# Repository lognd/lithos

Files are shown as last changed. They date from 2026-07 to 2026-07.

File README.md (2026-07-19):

# lithos

lithos is four declarative engineering-design languages -- **hematite**
for mechanical parts and assemblies, **cuprite** for electrical and
computer designs, **fluorite** for fluid circuits, **calcite** for
civil/architectural design -- built over one shared regolith, plus the
**regolith** toolchain that type-checks them and discharges their
engineering claims against verification models. The core idea inverts
the usual workflow: instead of drawing an implementation and analyzing
it afterward, a design *states intent and obligations* (what the
artifact must do, how it is made, what it promises to its neighbors)
and the toolchain proves those obligations -- or reports honest
failures as data, with source spans and provenance. Text is the single
source of truth: diffable, reviewable, and statically checkable without
rendering or simulating anything.

## Names (one geology theme)

| Name | What it is |
|---|---|
| **lithos** | the umbrella project (the languages + toolchain + registry); branding, not a code identifier |
| **hematite**  | the mechanical language; files `.hema` |
| **cuprite** | the electrical/computer language; files `.cupr` |
| **fluorite**  | the fluid-circuit language; files `.fluo` (ratified cycle 20) |
| **calcite** | the civil/architectural language; files `.calx` (chartered cycle 26, D133) |
| **regolith**  | the toolchain/CLI/import name (crates `regolith-*`, Python package `regolith`, lockfile `regolith.lock`) |
| **magnetite** | the package manager (manifest `magnetite.toml`, module `regolith.magnetite`, CLI `regolith magnetite`); its registry is "the magnetite registry" (cycle 26, D132; quarry/lodestone retired) |
| **feldspar**  | an external solver pack, its own repo (github.com/lognd/feldspar); optional -- discharges FEA and closed-form engineering claims through the pack contract, checked out beside this repo for local dev |

hematite, cuprite, fluorite, and calcite are deliberately "different
vocabularies over the same machinery": the type system, quantity/
interval engine, contract model, ownership discipline, and the
claim/obligation/evidence pipeline are defined once in the regolith
and bound per domain. Learning one language is most of the way to
knowing the others.

## Architecture in brief

The one-sentence shape: a Rust compiler core behind one coarse,
schema-versioned PyO3 boundary, wrapped by a Python orchestrator that
talks to the outside world. The split follows the spec's own
serialization point -- obligations are self-contained and serializable
-- so the boundary is coarse and stable rather than chatty.

- **Rust core** (`crates/regolith-*`): lexer (logos) + layout pass +
  lossless CST parser (rowan), the quantity/unit/interval engine, the
  entity database with queries/ownership/borrows, contract IR and
  budget arithmetic, lowering of claims to content-addressed
  obligations, and one diagnostic renderer. Pure, deterministic, and
  testable entirely without Python.
- **Python orchestrator** (`python/regolith/`): the verification
  harness (model registry plus numpy/scipy model packs that discharge
  physical claims), build tiers and the evidence cache, lockfile
  authorship, the `magnetite` package client, and the `regolith` CLI.

The harness discharges claims against a model registry; closed-form
model packs ship in this repo, and higher-fidelity models (FEA and
other numeric solvers) come from **feldspar**, an optional external
solver pack (github.com/lognd/feldspar, its own repo -- checked out
beside this one for local dev). feldspar is not required: a build
without it degrades honestly, discharging what the in-tree closed-form
packs can prove and reporting the rest as open obligations rather than
failing silently. It plugs in through the one plugin seam
(`regolith.plugins`, AD-26); the pack contract itself is normative in
[`docs/spec/toolchain/20-solver-abstraction.md`](docs/spec/toolchain/20-solver-abstraction.md)
sec. 7-8.

Errors are data on both sides: `regolith-diag` diagnostics in Rust,
typani `Result` values in Python; exceptions and panics are reserved
for programmer bugs. Shared schemas are single-sourced in Rust
(schemars) and code-generated into pydantic models. The full normative
architecture (decisions AD-1..39) is in
[`docs/spec/toolchain/00-architecture.md`](docs/spec/toolchain/00-architecture.md).

## A taste of the syntax

From [`examples/tracks/hematite/pillow_block.hema`](examples/tracks/hematite/pillow_block.hema),
a profile whose radius is left for the toolchain to allocate (`minimize`
picks the value that satisfies the obligations):

```
profile BodyOutline:
    walk:
        from base_plane
        line right                    # a: base
        line up                       # b: right wall
        arc tangent, bulge=left       # c: dome
        line down                     # d: left wall
        close
    constraints:
        a.length = 90mm
        b.length = 22mm
        c.radius = in [28mm, 36mm] minimize
        symmetric(b, d, about=mid_plane)
    exports:
        mid_plane: datum
```

The `examples/` tree holds many more, including a ten-file cubesat
project (`examples/flagships/cubesat/`) used as the integration stress test.

## Getting started

Prerequisites: the pinned Rust toolchain (`rust-toolchain.toml`, stable
1.90.0) and [uv](https://github.com/astral-sh/uv) for the Python side.
One command sets up a working dev environment (uv sync plus building the
compiled extension into the venv):

```
make install
make check
```

`make check` is the single quality gate -- format, lint, types, and both
Rust and Python tests, cheapest first. Key targets:

| target | does |
|---|---|
| `install` | uv sync + build the `regolith._core` extension (debug) |
| `dev` | rebuild the extension into the venv on Rust change |
| `check` | full gate: fmt, lint, typecheck, core-import guard, tests |
| `test` | all tests (`test-rs` / `test-py` to split) |
| `snapshots`  | review insta snapshots |
| `schema` | regenerate the generated pydantic schema from Rust |
| `bench` | criterion benchmarks over the cubesat corpus |
| `fuzz` | fuzz the lexer/parser/CBOR decode (needs nightly cargo-fuzz)|
| `coverage` | Rust + Python coverage |
| `build` | release wheel via maturin |
| `health` | the repo health gate (`tools/health`): check + consistency + demos + fleet legs (D219) |

Run `make help` for the full list.

## Repository layout

Full doc index (spec, workflow, guide): [docs/index.md](docs/index.md).

```
docs/
  spec/            technical truth: regolith/ (shared abstract layer,
                    01..13), hematite/ cuprite/ fluorite/ calcite/
                    (the four language tracks), toolchain/ (normative
                    architecture + numbered design charters)
  workflow/        process: ground rules, dispatch protocol,
                    work-orders/, design-log/ (dated findings and
                    decisions, verbatim history)
  guide/           teaching guides, one per track plus authoring guides
crates/            the Rust core (regolith-util .. regolith-py)
python/regolith/   the Python orchestrator, harness, magnetite, and CLI
examples/          designs in target syntax (the golden / pressure-test corpus)
stdlib/            the standard library packages (std.*)
tests/             cross-boundary goldens, CLI end-to-end, and invariant tests
```

## The CLI

`regolith` is the single entry point; verbs include `check` (the
geometry-free linter), `fmt`, `debug`, `build`, `ship`, `optimize`
(the discrete/continuous search engine), `test` (the design-test
runner over `.test.<ext>` files), `doc`, `config`
(`get`/`where`/`list`/`set` over the four-level config doctrine),
`rules test`/`rules try` (rule-pack authoring), `plugin list` (AD-26
plugin seam), and the `magnetite` package-manager subtree
(`magnetite new`, `vendor`, `fetch`, `key`, `index`, `manifest
check`, with `new` and `vendor` also aliased at the top level). Run
`regolith --help` or `regolith <verb> --help` for the current,
authoritative list -- verbs land and change per work order faster
than this README does.

## graphite: the interaction surface

**graphite** (the drawing mineral) is the repo's interaction surface --
a TUI, and (cycle 35, D233/D234) a professional web dashboard/explorer/
artifact-viewer product. It EXTRACTED to its own sibling repo,
github.com/lognd/graphite, checked out beside this one for local dev,
exactly like feldspar: its own product charter, design system, and
work-order queue live in that repo's `docs/`, and its own `make check`
is its gate. It consumes only regolith's public surfaces -- CLI verbs
as subprocesses, reported JSON, and the D228 progress channel -- never
orchestrator or harness internals.

```
cd ../graphite && make install
graphite tui [project]     # terminal UI
graphite serve [project]   # dashboard, explorer, artifact viewers
```

The full guide, including what ships today versus what is still in
flight, is [`docs/guide/12-graphite.md`](docs/guide/12-graphite.md).

## Status

Honest state of the project:

- **Languages and specs: complete.** The regolith and all four language
  tracks (hematite, cuprite, fluorite, calcite) are settled; the
  technical open-question queue is empty by design. `docs/` is the
  normative source, led by the invariant ledger
  (`docs/spec/regolith/13-invariants.md`).
- **Toolchain: substantially built, `make check` green.** The Rust core
  (lexer, layout, CST parser, entity DB, quantity/interval engine,
  contract IR, and lowering to obligations), the PyO3 bridge, the
  Python orchestrator, the harness with closed-form model packs, and the
  `magnetite` package tool are implemented and pass the gate. CI runs
  format/lint/type/test on a matrix, with fuzzing and benchmarks wired.
- **Invariant suite (INV-1..30): mostly real green,** with a small
  number of deliberately tracked `xfail` fixtures where the enforcing
  machinery is still being wired.
- **Roadmap:** the mechanical geometry realizer (`FeatureProgram` IR
  through build123d/OCCT to STEP), the optimization engine
  (`regolith optimize`), CAM and HDL verification, and the
  design-test runner (`regolith test`) have all landed; higher-
  fidelity FEA verification escalates to the optional feldspar
  solver pack rather than living in-tree. Remaining work is tracked
  in `TODO.md` and the design-log queue -- not here (this README
  does not duplicate the ledger).

## License

GPL-2.0-only (the Linux kernel's license; owner-decided 2026-07-08):
free to use, study, modify, and redistribute -- derivatives play by
the same rules. Full text in `LICENSE`.

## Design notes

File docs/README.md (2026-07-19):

# lithos -- Documentation

Declarative, goal-oriented engineering design languages built on one
shared regolith:

- **hematite** -- mechanical design (parts, processes, assemblies).
- **cuprite** -- electrical and computer design (circuits, boards,
  logic, processors).
- **fluorite** -- fluid circuits (feed systems, coolant loops,
  hydraulics, pneumatics; ratified cycle 20, D93).
- **calcite** -- civil/architectural design (spaces, structure,
  envelope; chartered cycle 26, D133 -- the youngest track).

Named on one geology theme (D78, cycle 10; fluorite cycle 20;
magnetite + calcite cycle 26): **hematite** is iron ore (steel,
structure -> mechanical); **cuprite** is copper ore (wire, current ->
electrical); **fluorite** is the mineral named for flowing (flux ->
fluids); **calcite** is the mineral of limestone and cement (->
buildings); **magnetite** (the package manager) attracts them all;
everything is worked by **regolith** (the shared toolchain). The
whole project -- languages, toolchain, registry -- is umbrella-branded
**lithos**. Retired names: `quarry`/`lodestone` (-> magnetite, D132),
`mill`/`loom`/`dcad`/`deda`, and calcite's dead draft usage as the
fluid track's name (`.calc`, D93; the civil track uses `.calx`);
retired names appear verbatim only in `design-log/` history.

All the languages invert the traditional workflow:

```
Traditional:  Implementation -> (manual analysis) -> "does it work?"
Here:         Claims + Contracts -> (solvers, provers) -> Implementation + Evidence
```

The designer declares what the artifact must do, how it will be made,
and what it promises to other artifacts. The system derives the
implementation, allocates the numbers nobody wants to pick by hand,
and attaches evidence to every physical claim. Text is the single
source of truth: diffable, reviewable, and statically checkable
without rendering or simulating anything -- which makes design
generation (human or LLM) a locally verifiable problem. The north
star: write a declarative file, inject a high-skill engineer at the
intermediate steps only if necessary, and get something out the end
that just works.

The languages are deliberately "different vocabularies over the same
machinery": the type system, the contract model, the ownership
discipline, the claim/obligation/evidence pipeline, the lowering
architecture, and the build system are all defined once, in the
regolith, and bound per domain. Learning one language should mean
already knowing 80% of the others.

## Reading order

1. `spec/regolith/` -- the abstract backing layer. Read this first; every
   language track is an instantiation of it.
2. `spec/hematite/` -- the mechanical language. The most mature track.
3. `spec/cuprite/` -- the electrical and computer language.
4. `spec/fluorite/` -- the fluid-circuit language (ratified v1, cycle 20).
5. `spec/calcite/` -- the civil/architectural track (charter cycle 26,
   elaborated cycle 27, ratified 2026-07-08, D149; front end landed,
   WO-47).
6. `guide/` -- the teaching guides (getting started + per-track).

## Directory map

Three top-level categories (D138, cycle 26): `spec/` is technical
truth, `workflow/` is process, `guide/` is for people.

```
docs/
  spec/          TECHNICAL -- normative specifications
    regolith/    the shared abstract layer (domain-neutral), 01-13;
                 13-invariants.md is the guarantee ledger (INV-1..35;
                 INV-33 withdrawn/RESERVED, D253.4)
    hematite/    mechanical track (unified spec; version on header)
    cuprite/     electrical + computer track
    fluorite/    fluid-circuit track, `.fluo` (ratified v1, cycle 20)
    calcite/     civil/architectural track, `.calx` (charter cycle 26;
                 ratified D149, 2026-07-08)
    toolchain/   00-architecture.md (NORMATIVE, AD-1..47),
                 grammar.ebnf, numbered design charters (10-..46-);
                 20-solver-abstraction.md sec. 7-8 is the feldspar
                 pack contract (AD-26 plugin seam)

  workflow/      PROCESS -- how the project is built
    README.md    ground rules, the dispatch protocol, the WO
                 dependency graph
    work-orders/ WO-01..171, agent-executable, one per dispatchable
                 unit; the live dispatch queue is `tickets.md`
                 (`frob ticket doable`) -- WO `Status:` lines are
                 historical narrative, not a second queue
    design-log/  dated findings + decisions ledgers, one per design
                 cycle -- THE project history, verbatim (never edited)

  guide/         PEOPLE -- teaching + authoring guides
                 (getting started, per-track guides, then
                 authoring/tooling guides: DFM rules, optimization,
                 graphite, parity reports, CAM/HDL verification,
                 board correctness, design testing)

../examples/     the spec pressure corpus (see examples/README.md):
                 tracks/ per-language single-file tests, systems/
                 multi-file spec-pressure projects (dune_buggy,
                 reaction_wheel, regen_engine, sdr_transceiver),
                 flagships/ the charter-31 program members held to
                 the full ship+parity bar (cubesat Kestrel, arm_a6,
                 cnc_router_r1, printer_k1, uav_talon, and more),
                 hdl/ coverage fixtures, negative/ diagnostic
                 fixtures, registry/ component records
../stdlib/       the standard library packages (std.*, D135;
                 organization normative home: charter 39,
                 spec/toolchain/39-stdlib-organization.md)
```

graphite (the TUI + web dashboard/explorer interaction surface) is no
longer in this tree: it EXTRACTED to its own sibling repo (cycle 35,
D233/D234, github.com/lognd/graphite), checked out beside this one
for local dev exactly like feldspar. See `guide/12-graphite.md`.

## Status legend

Used throughout:

- **[SETTLED]** -- decided; changing it is a spec revision.
- **[LEANING: x]** -- default direction chosen, revisit allowed cheaply.
- **[OPEN-n] / [EOPEN-n] / [FOPEN-n] / [SOPEN-n]** -- needs a decision
  (mech / elec / fluid / regolith numbering). The technical open queue
  is EMPTY by design (F90); deferred items carry explicit reopen
  criteria in each track's open-questions doc.
- **[SEAM-n]** -- designed on both sides, the joint itself unspecified.

## Cross-domain composition

A mechatronic system is one `system` with parts from several domains:
a board is simultaneously an electrical artifact and a mechanical one;
a building (calcite) hosts fluid loops (fluorite) and power (cuprite).
The regolith's contract model is what makes this tractable -- an
interface may carry roles and promises from more than one domain's
quantity namespaces. See `regolith/10-domain-binding.md`.

## feldspar (the optional solver pack)

**feldspar** (github.com/lognd/feldspar) is an external, optional
solver pack -- its own repo, checked out beside this one for local
dev. It supplies higher-fidelity FEA and closed-form engineering
verification models that plug into the regolith harness's model
registry through the one plugin seam (`regolith.plugins`, AD-26).
It is not required: a build without feldspar checked out degrades
honestly, discharging whatever the in-tree closed-form model packs
can prove and reporting the rest as open obligations rather than
failing. The pack contract itself -- what a pack must implement,
claim-kind naming, coverage/evidence encoding, the payload-ref
channel -- is normative in
`spec/toolchain/20-solver-abstraction.md` sec. 7-8. Cite paths inside
it as `feldspar:<path>` (never a `../` path; see Conventions below).

## Conventions

- Cross-repo citations are repo-qualified, never filesystem-relative:
  `feldspar:docs/spec/09-model-integration.md` means that path in the
  `feldspar` repo (github.com/lognd/feldspar). `../` paths out of
  this repository are banned in living docs (they do not resolve on
  GitHub); design-log history keeps whatever it originally said.

- All documentation and source examples are ASCII-only. The languages
  themselves define ASCII canonical operator spellings (`&`, `dia`,
  `+-`, `deg`, `mu_`); formatters may render unicode, files never
  store it.
- Spec versions ride each track's header line and bump when the track
  materially changes; the per-cycle change ledgers live in
  `design-log/` (one dated file per cycle, findings F* and decisions
  D* numbered globally).

## Revision history

Lives in `workflow/design-log/`, one dated ledger per design cycle -- that is
the authoritative trail of every finding (F1..) and decision (D1..).
This file intentionally carries no duplicate changelog (D137: git
history and the design logs are the archive).

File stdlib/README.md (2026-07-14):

# stdlib/ -- the `std.` catalog (D135, WO-45)

**Normative home:** `docs/spec/toolchain/39-stdlib-organization.md`
(charter 39, D227/AD-37) is the normative organization doctrine for
everything in this directory -- namespace taxonomy, package anatomy,
content classes, the lithos/feldspar boundary rule, and the naming/
growth discipline, all machine-checked in the health consistency leg
(`tools/stdlib/organization.py`). This README is the working package
INDEX (below) plus the D135/D58 history this catalog started from;
where the two disagree, charter 39 wins. See also
`docs/guide/28-growing-the-stdlib.md` for a worked "where does my new
content go" walkthrough.

Governance history (regolith/11 sec. 8, D135):

- `std.` is a RESERVED namespace prefix in the magnetite registry: only
  the lithos project publishes under it.
- Nothing in the compiler special-cases `std` (grep `std.` in `crates/`
  stays clean of new logic), with the one documented exception that the
  unit tables (what `std.units` would be) live in `regolith-qty` because
  quantities are load-bearing at L1, before package resolution runs.
  `std.quantities` (below) is therefore a nominal package: it declares
  the namespace/claim-form surface the tracks already assume, so a
  project's `magnetite.toml` can depend on it like any other package,
  but it ships no records of its own -- the math lives in `regolith-qty`.
- **In-repo development home:** each `stdlib/<package>/` directory is a
  real magnetite package (its own `magnetite.toml` + record/model
  content). CI and the example corpus (`examples/`) consume these
  in-repo copies directly, via `regolith.magnetite.manifest.resolve_dependencies`
  pointed at `stdlib/` as a local search path -- no network, no separate
  "path source" concept invented (checked `magnetite/sources.py` first,
  per the WO note: `resolve_dependencies` already IS local-path
  resolution; `Sources`/`Registry` in `sources.py` is a distinct concern,
  URL-based routing for a future fetch step, not needed here).
  Publication to the public registry (out of scope, regolith/11 sec. 10)
  would be the same act as for any third-party package; the project
  signing key confers the tier (INV-14).
- **Tier honesty (D58):** every record here that transcribes a
  real-world datasheet/handbook value without an attached certified
  test report says `tier=community` in-file, and cites its source.
  Nothing here claims `tier=certified`.

## Packages (v1)

| package | kind(s) | content |
|---|---|---|
| `std.quantities` | quantities | namespace/claim-form declarations only (math in `regolith-qty`) |
| `std.materials` | materials | starter metal/polymer records, `tier=community`; cycle-33 F112 queue adds `records/composites.toml` (6 rows: E-glass/epoxy and carbon/epoxy unidirectional lamina engineering constants transcribed from the widely-reprinted Tsai/Jones/Barbero textbook table, plus a cross-ply and a quasi-isotropic laminate-modulus row per fiber system derived from those lamina constants by Barbero's closed-form approximations; `density_kg_m3` omitted on every row, no source above pins it honestly) |
| `std.contact` | materials | dry/greased contact-pair friction records, `tier=community` |
| `std.mech` | interfaces, matings | mount/flange interface packs, process capability packs (cnc/forged/formed/cast/molding/sheet/tube/turned/weld/joining/gear/linear/spring/bearings/seals), bolted/press/bearing matings; WO-64 W3/WO-66 follow-up added `Prismatic` to `mech.matings` (mirrors `Revolute`'s single-exposed-dof pattern for linear motion, content-only, no compiler change) |
| `std.sheet_metal` | process | sheet-metal process capability records; the DFM RULE-PACK half is EXCLUDED (WO-28 engine remainder owns the rule format) -- this package is the record content + package home only |
| `std.elec` | interfaces, matings, components | port/family/protocol/bus packs (buffers, buses, digital, families, logic, power, protocols, sense) PLUS (WO-66, D174/D179) a GENERATED `passive_family` E-series batch (`records/e_series.toml`, IEC 60063 resistor/capacitor parametric families) and a hand-cited `connectors.toml` batch (JST-XH/PH, Molex KK, screw-terminal classes). WO-66 follow-up batch 2 (2026-07-10) adds `records/cells.toml` (Samsung INR18650-25R cylindrical Li-ion class, EEMB LP503759 pouch LiPo class, plus a `series_pack` class deriving voltage/mass by declared cell x S-count arithmetic -- not a transcribed vendor pack SKU) and `records/servos.toml` (Hitec HS-311 standard + HS-55 micro RC servo classes), all hand-cited manufacturer datasheet figures. Cycle-33 F112 queue batch 2 (2026-07-10) adds two more `crystals.toml` rows (Epson FA-238 32.768kHz tuning-fork RTC crystal, Abracon AB-8.000MHZ HC-49/US class) and three more `connectors.toml` rows (JST-PH 4-position, Molex-KK 6-position, and a 0.1in board-to-board pin-header class carrying the first `exposure_class = "internal"` example), same hand-cited shape as the WO-79/WO-66 batches. Config-strap rows (the third WO-79-pattern item on the same queue entry) were evaluated and CUT: no stdlib package hosts MCU strap records today (the three straps: tables that exist -- `examples/registry/{rp2040,atsamd21,stm32g0}.cupr` -- are corpus, not stdlib/, out of this batch's scope), and no additional MCU part could be cited to the same section-number precision those three already meet without risking the fabricated-precision failure mode `rp2040.cupr`'s own header explicitly warns against; named growth, not silently dropped. |
| `jlc_2l` | process | JLCPCB 2-layer fab + basic SMT assembly capability records (vendor-named, rides beside `std.elec`, NOT under the `std.` prefix) |
| `std.fluid` | materials | media property tables + fitting/loss/pipe-schedule records; WO-60 (D166) added a `components.toml` batch (pump, ball valve, in-line filter, metering orifice), real-catalog cited; WO-64 W1/W2 (WO-66 follow-up, D182) added `records/polymer_melt.toml` (PLA/PETG melt-medium classes: solid density + cited melt-density/zero-shear-viscosity point sets, PETG's melt density/viscosity OMITTED with a note pending a verifiable source) and two more `[[pump]]` rows in `components.toml` (Sunon 4020 12V DC axial fan, Delta 5015 24V DC radial blower -- rated flow endpoints only, real-catalog cited) |
| `std.intents` | verbs | intent-verb schemas (`sense`, `actuate`) |
| `std.debug` | verbs | debug/probe/indicate verb schemas |
| `std.models` | models | registration manifest binding the EXISTING `python/regolith/harness/models/` code -- the code does not move, this package only names it |
| `std.mech.mechanisms` | matings, process | pattern library (D144/AD-28, WO-53 seed + Batch B; WO-60 Batch C): `four_bar`, `slider_crank`, `lead_screw`, `belt_drive`, `gear_train`, `bearing_arrangement`, `helical_spring`, `flexure_pivot`, `toggle_linkage` -- coupler-law `mating`s, `advise:`-only recognition rules (`dfm:` block) |
| `std.elec.patterns` | interfaces, components, process | pattern library (D144/AD-28, WO-53 seed + Batch A): `level_shifter`, `decoupling`, `reverse_polarity`, `tvs_clamp`, `rc_debounce`, `ldo` -- `block`s + reference impls, `advise:`-only recognition rules (`erc:` block) |
| `std.civil` | occupancy, loads, matings, sections, materials | WO-48 slice C + WO-60 widening: occupancy/egress tables (IBC), load cases + ASCE 7/AISC/NDS/geotech combination sets, transfer classes as real `mating`s with `dof: kept=` (`Pinned`/`Moment`/`Bearing`/`Roller`/`BasePlate`/`EmbeddedPost`), starter section/material/soil records PLUS (WO-60, D166) a real AISC 16th-ed. `w_shape` family (16 sections) and `hss_square` family (28 sections, ASTM A500 Grade C) so section search has a real multi-member domain; `astm_a500_grc` material added to match. The reference building-code rule pack is EXCLUDED (`TODO(WO-28)`: the engine remainder it needs is still blocked upstream). WO-66 (D174) adds a GENERATED `sections_channels_angles.toml` (`steel_channel`/`steel_angle` families, same AISC v16.0 edition) as an ADDITIVE file beside `sections.toml` -- zero existing rows touched or renamed. WO-66 follow-up batch 2 (2026-07-10) widens the `timber_sawn` family in `sections.toml` from 2 to 11 rows (nominal 2x6 through 2x12, 4x4/4x6, and 6x8/6x10/6x12 beam-class sizes; dressed dimensions per the ALSC/PS 20-based NDS Supplement Table 1B table the two original rows already cite, section properties computed from those dressed dims by the same method the original rows use) -- ADDITIVE ONLY, the two original rows untouched. |
| `std.cost` | rates, pricing, unit_costs, models | WO-54 (D147, toolchain/27): rate/pricing/unit-cost FIXTURE records (every number invented -- never transcribed vendor/RSMeans data, research note 2026-07-09 sec. 4) + the harness-half naming of the reference estimator models (`cost_elec_bom`/`cost_fluid_bom`/`cost_civil_takeoff`, the std.models code-does-not-move precedent). Includes the deliberately-expired `acme.quote_2025q4` negative-fixture pricing source. |
| `ti.logic` | components | WO-60 (D166): TI 74HC-series glue-logic component records (SN74HC02 quad NOR, SN74HC138 3-to-8 decoder, SN74HC688 8-bit identity comparator) -- the `nor_glue` candidate family for WO-56's `by select(nor_glue, cpld, mcu_chip_selects)` demo. Vendor-named, rides beside `std.elec` (regolith/11 sec. 2's own worked example row), NOT under the `std.` prefix. |
| `microchip.cpld` | components | WO-60 (D166): ATF1502AS/ATF1502ASL 32-macrocell CPLD component records (two speed grades, -7 and -25) -- the `cpld` candidate for the same WO-56 demo. Vendor-named. |
| `st.mcu` | components | WO-60 (D166): STM32F4 FSMC (RM0090) external-bus-interface chip-select record -- the `mcu_chip_selects` candidate for the same WO-56 demo (an MCU's own EBI/FSMC decode instead of external glue). Vendor-named. |

| `std.fasteners` | components | WO-66 (D174): ISO metric fastener grids -- socket head cap screws (ISO 4762), hex bolts (ISO 4014), hex nuts (ISO 4032), plain washers (ISO 7089), GENERATED from `tools/stdlib/gen_fasteners.py` over the committed `tools/stdlib/data/iso_fasteners.toml` table (D178 shape ratification). |
| `std.bearings` | components | WO-66 (D174): deep-groove ball bearing grid (60xx/62xx/608 class, ISO 15 boundary dims) + LM_UU linear bushing seed, hand-cited (D180). |
| `std.motion` | components | WO-66 (D174): NEMA 17/23 stepper rated-point classes, Tr8 leadscrew class, GT2 belt/pulley class, MGN12/15 linear rail seed, hand-cited (D180). |
| `std.machines` | components | WO-66 (D174, feeds WO-67/AD-35): 3-axis mill / FDM printer / CO2 laser CLASS records (travel/kinematics/spindle-or-nozzle), hand-cited (D180). |
| `std.tooling` | components | WO-66 (D174, feeds WO-67/AD-35): solid-carbide end-mill and ISO 235/DIN 338 jobber-drill geometry classes, hand-cited (D180). |
| `std.power` | records | WO-134 (charter 43 sec. 2-3/5, D250): NEC (NFPA 70) 2023 Edition Article 310/250 tables transcribed as data -- `conductor_ampacity` (Table 310.16, copper 14 AWG-500 kcmil + aluminum 12 AWG-500 kcmil, 60/75/90C columns), `temp_correction_factor` (Table 310.15(B)(1), 21-85C ambient bands), `conduit_fill_adjustment` (Table 310.15(C)(1), 4-41+ current-carrying conductors), `grounding_electrode_conductor` (Table 250.66), `equipment_grounding_conductor` (Table 250.122), and `motor_locked_rotor_code` (ANSI/NEMA MG 1-2016 (R2018) sec. 10.37.2 locked-rotor kVA/HP code-letter classification, A-V). Transformers, breakers/fuses (frame/trip/AIC/curve), motor HP/kW/PF/efficiency catalog rows, and busway are NAMED REFUSALS (D250 sec. 3: no offline-verifiable specific catalog source this session) recorded in the WO-134 close-out, not fabricated. |

`std.fluid.circuits` / `std.civil.assemblies` (D144 pattern libraries,
remaining catalog batches) are catalog GROWTH, not this WO's seed
(charter `docs/spec/toolchain/26-pattern-libraries.md` sec. 3
non-goal).

## Record format

Record BODIES that are ordinary language source (interface/mating/
process declarations consumed by a track's front end) are authored in
that track's own syntax, exactly like `examples/registry/*.cupr`. Data
records with no track-specific syntax yet (materials, contact pairs,
fluid media/pipe tables) are authored as plain TOML under each
package's `records/` directory and loaded by
`regolith.magnetite.stdlib_records.load_toml_records` into the ordinary
`regolith.magnetite.records.Record` model -- Python-side data
authoring only, no new Rust grammar (this WO is Python + records, no
Rust per its `Language:` header).

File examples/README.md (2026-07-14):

# examples/ -- the spec pressure corpus

Every file here is a pressure test of the language specs and (where
the toolchain can compile it) a golden-corpus input. Conventions:
comments cite the spec section a construct exercises; engineering
numbers are realistic; `.hema`/`.cupr` files are parse-clean
(INV-20: a poisoned subject is corpus rot unless deliberately
negative); claim forms the harness cannot yet lower are EXPECTED and
captured by the deferral golden (`tests/golden/`). Never hand-edit a
golden -- regenerate per the driver docstrings and diff-review.

Taxonomy rule (D188, cycle 32): `tracks/` single-file per-track
pressure tests; `systems/` multi-artifact spec-pressure designs
(CLOSED to new members); `flagships/` charter-31 program members
held to the full bar (ship + parity + demonstration inventory +
walls ledger) -- new machine-scale builds go HERE. A systems/
member may graduate to flagships/ by deliberate move + WO.

```
examples/
  tracks/       single-file (or paired) per-track pressure tests
    hematite/   mech: pillow_block, sheet_bracket, weldment_frame,
                molded_clip, torch_igniter (flagship), gear_reducer,
                regen_chamber, suspension_link; + manifold and
                sensor_boom (feldspar fixtures, D148); +
                coolant_gallery (the D152 cavity->flow_paths
                exemplar, WO-51)
    cuprite/    elec + computer: thermostat, mux6to64,
                buck_converter, motor_drive, fpga_mcu_board,
                sampled_buck, flight_controller; + psu_enclosure
                (feldspar fixture, D148)
    xdomain/    cross-track pairs: sensor_pod, imu_board,
                servo_drive + servo_module
    fluorite/   (cycle 23 / D122, grown by WO-31 D5) seven fluid
                circuits -- check-clean since WO-31, lowered since
                WO-32
    calcite/    (cycle 27 / D139) four civil designs -- spec
                pressure tests until WO-47, then its golden corpus
  flagships/    charter-31 program members, held to the full bar
                (ship + parity + demonstration inventory + walls
                ledger). New machine-scale builds land HERE (D188).
    la_jig8/    (cycle 36 / WO-127, charter 40 sec. 4) the
                logic-analyzer tap jig: the test hardware that probes
                a target board is ITSELF a lithos design, shipped
                through the same pipeline (census, calc book,
                gerbers, firmware, its own harness pack). The dogfood
                proof of charter 40's "easy to physically test"
                promise; paired with demos/demo17. Mates -- never
                restates -- the std.elec `tap_header_2x08_254` pinout
                record (D242 routed it here, not to systems/).
  systems/      multi-file, multi-track projects (the stress corpus,
                design-log cycle 23 / D119)
    cubesat/    Kestrel: the ten-file flagship + magnetite.toml
    cnc_router/ espresso_machine/ sdr_transceiver/ -- the cycle-23
                stress trio
    small_office/ (cycle 27 / D139) the cross-track building
                flagship: .calx + .fluo + .cupr + cost profiles
    reaction_wheel/ regen_engine/ dune_buggy/ -- the feldspar
                pressure fixtures, migrated cycle 27 (D148; the
                G-nn friction logs; see ../feldspar-fixtures.md)
  hdl/          (D120) foreign-HDL fixture pairs proving
                the cuprite/09 coverage matrix: legal .v/.sv/.vhd
                sources + native cuprite equivalents + equivalence
                obligations
  registry/     component-record fixtures (stm32g0, atsamd21,
                rp2040, i2c_protocol) -- the datasheet-transcription
                format, EOPEN-12/D58
  negative/     (cycle 23 / D123) the rule-breaking corpus: each
                file breaks EXACTLY ONE rule, graded obvious ->
                hidden; `# BREAKS:`/`# EXPECT:` headers drive
                tests/golden/test_negative_corpus.py; known-uncaught
                breaks are `# EXPECT-TODO:` xfails = demand signal
```

`.fluo` files have been checked sources since WO-31/32 (registered
extension, net discipline, lowering). `.calx` files are the current
spec-pressure generation: invisible to `regolith check` until WO-47
registers the extension, exactly the arc `.fluo` followed.

Every `std.*` reference in this corpus (`import std.mech.X (...)`,
bare `material: <Name>`, `process=pcb_fab(jlc_2l)`, ...) resolves
against the real starter packages in `stdlib/` at the repo root
(D135, WO-45) -- no phantom references; `tests/magnetite/
test_stdlib.py` enumerates and checks every one. `std.civil`
references (calcite fixtures) and the `std.compute`/`std.fluorite`
language-builtin namespaces are the named exceptions (see that test
module's docstring).

THIS DIRECTORY IS THE ONE CORPUS (D148, cycle 27): the feldspar
repo's `feldspar:examples/lithos/` is a verbatim MIRROR of it, refreshed by
feldspar's `make sync-examples` from a sibling checkout -- never
edited there. Fixture changes land HERE first.
Per-project READMEs carry a file map
(file | subsystem | pressure applied) and a "Candidate findings"
ledger that the coordinating design cycle promotes into
`docs/workflow/design-log/` (project authors never edit the design log).

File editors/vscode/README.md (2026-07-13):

# lithos (VS Code extension)

Makes VS Code a lithos environment for `.hema` (hematite), `.cupr`
(cuprite), `.fluo` (fluorite), and `.calx` (calcite) files: generated
TextMate highlighting, the bundled `regolith-ls` language server (when
present), snippets, `lithos: check/build/fmt/rules test` commands, and
(WO-120/D229) feature parity with the toolchain's current surface:

- **Progress-tracked commands**: `lithos: build --release`, `ship`,
  `preview`, `optimize`, `test`, `health` run the real CLI with
  `REGOLITH_LOG=DEBUG`, parse its D228 progress stream (the ONE parser
  site for that wire shape is `src/progress.ts`, citing
  `python/regolith/progress.py`'s docstring verbatim), and mirror it
  into a VS Code progress notification; diagnostics still flow through
  the existing LSP path (AD-7) and the output channel carries the full
  run log.
- **Claim hovers**: hovering a claim line inside a `require ...:` block
  shows its verdict/margin (discharged) or waiver memo/deferral/
  violation reason, read from the shipped `dist/calc/calc_book.json`
  (WO-114) -- never recomputed. With no matching shipped row (or no
  `dist/` at all), the hover degrades to an honest "(no build
  artifacts)" tail, same discipline as every other hover (D111).
- **Go to artifact** (`lithos.goToArtifact`, also on the command
  palette): from the claim under the cursor, opens the calc sheet PDF,
  calc book JSON, STEP file, or 3D viewer the audit index says
  discharges it (`src/artifacts.ts`/`src/goto-artifact.ts`).
- **Rigor census** (activity bar view "lithos" -> "Rigor census"): one
  row per `dist/` project found under the workspace, showing
  discharged/waived/deferred counts straight off its audit index
  summary, flagged stale when a source file is newer than the report.

See `docs/spec/toolchain/24-developer-tooling.md` sec. 4,
`docs/workflow/work-orders/WO-39-editor-extension.md`, and
`docs/workflow/work-orders/WO-120-vscode-extension-parity.md` for the
design and scope.

## WO-38 residuals, re-assessed (WO-120 deliverable 4)

- **Artifact-fed hover**: LANDED, via a different path than WO-38's cut
  assumed. WO-38 needed a `registry_version`-keyed evidence-cache read
  the orchestrator alone could compute; WO-114's `dist/calc/
  calc_book.json` is a self-contained, read-only JSON artifact keyed by
  claim name, so `crates/regolith-ls/src/artifacts.rs` reads it
  directly -- no Python embedding, no registry-version sidecar needed.
- **Registry-id completion**: STILL CUT. No Rust crate in
  `regolith-ls`'s dependency reach (`regolith-api` and below) reads a
  magnetite package index; that index reader does not exist anywhere in
  Rust today. Landing this needs a new Rust-side magnetite index reader
  crate, which is an architecture decision (a new crate + its layering
  slot), not an in-scope WO-120 implementation detail -- escalated as
  WO120-F1.

## Development

```
npm install
npm run gen:grammar          # regenerate syntaxes/*.tmLanguage.json from
                              # the compiler's own tables (cargo run -p
                              # regolith-syntax --bin grammar-json)
npm run gen:magnetite-schema # regenerate schemas/magnetite.schema.json
npm run compile               # tsc + esbuild -> dist/extension.js
npm test                      # grammar snapshot + drift + keyword tests
npm run package                # build a .vsix (no marketplace publish)
```

Both generators are drift-checked in CI (`npm run check:grammar`,
`npm run check:magnetite-schema`) exactly like `python/regolith/_schema/`
-- regenerate and commit rather than hand-editing `syntaxes/*.json` or
`schemas/magnetite.schema.json`.

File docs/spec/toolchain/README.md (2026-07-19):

# toolchain spec index

Normative toolchain architecture (`00-architecture.md`, AD-1..47) plus
the numbered design charters it wins over any WO body conflicting with
it. This is a link index; `00-architecture.md` is still the normative
root.

| doc | file |
|---|---|
| 00-architecture | [00-architecture.md](00-architecture.md) |
| 10-test-infra-and-ci | [10-test-infra-and-ci.md](10-test-infra-and-ci.md) |
| 20-solver-abstraction | [20-solver-abstraction.md](20-solver-abstraction.md) |
| 21-rule-packs | [21-rule-packs.md](21-rule-packs.md) |
| 22-mech-geometry-realizer | [22-mech-geometry-realizer.md](22-mech-geometry-realizer.md) |
| 23-lowering-output-surface | [23-lowering-output-surface.md](23-lowering-output-surface.md) |
| 24-developer-tooling | [24-developer-tooling.md](24-developer-tooling.md) |
| 25-drawings-and-artifacts | [25-drawings-and-artifacts.md](25-drawings-and-artifacts.md) |
| 26-pattern-libraries | [26-pattern-libraries.md](26-pattern-libraries.md) |
| 27-costing | [27-costing.md](27-costing.md) |
| 28-optimization | [28-optimization.md](28-optimization.md) |
| 29-interaction-surface | [29-interaction-surface.md](29-interaction-surface.md) |
| 30-geometry-lowering | [30-geometry-lowering.md](30-geometry-lowering.md) |
| 31-flagships | [31-flagships.md](31-flagships.md) |
| 32-stdlib-depth | [32-stdlib-depth.md](32-stdlib-depth.md) |
| 33-cam-verification | [33-cam-verification.md](33-cam-verification.md) |
| 34-topology | [34-topology.md](34-topology.md) |
| 35-signal-integrity | [35-signal-integrity.md](35-signal-integrity.md) |
| 36-board-correctness | [36-board-correctness.md](36-board-correctness.md) |
| 37-design-testing | [37-design-testing.md](37-design-testing.md) |
| 38-emission-and-release | [38-emission-and-release.md](38-emission-and-release.md) |
| 39-stdlib-organization | [39-stdlib-organization.md](39-stdlib-organization.md) |
| 40-debug-and-bring-up | [40-debug-and-bring-up.md](40-debug-and-bring-up.md) |
| 41-artifact-presentation | [41-artifact-presentation.md](41-artifact-presentation.md) |
| 42-injection-and-artifact-surface | [42-injection-and-artifact-surface.md](42-injection-and-artifact-surface.md) |
| 43-power-distribution | [43-power-distribution.md](43-power-distribution.md) |
| 44-boundary-charter | [44-boundary-charter.md](44-boundary-charter.md) |
| 45-process-record-schema | [45-process-record-schema.md](45-process-record-schema.md) |
| 46-traced-profiles | [46-traced-profiles.md](46-traced-profiles.md) |

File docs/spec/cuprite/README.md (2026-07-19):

# cuprite -- Declarative Electrical and Computer Design

> Spec 0.13 (design sketch). NAMED **cuprite** (`.cupr`) in cycle 9
> (D78). 0.10 -> 0.11 (cycle 18, WO-28 spec cycle): the `drc:`/`erc:`
> rule grammar and the discipline boundary landed
> ([04-structural-layer.md](04-structural-layer.md) sec. 4, [07-vocabulary-sketch.md](07-vocabulary-sketch.md)
> sec. A2). 0.11 -> 0.12 (cycle 23, D120): the HDL coverage matrix
> ([09-hdl-coverage.md](09-hdl-coverage.md)) makes the "HDL superset" banner precise and
> testable. 0.12 -> 0.13 (cycle 36, D248/AD-42, WO-132): the power
> layer ([10-power-layer.md](10-power-layer.md)) adds facility power
> distribution as a fourth `NetDiscipline`. This track is
> deliberately younger than the mechanical one: the regolith is
> proven against mech first, and this directory's job is to
> demonstrate that the same machinery carries electrical and computer
> design without deformation -- and to flag where it does not.

cuprite is the electrical instantiation of the regolith (`../regolith/`).
It covers two coupled sub-tracks:

- **Circuit track:** boards and analog/mixed-signal design -- from named
  intents down to gerbers.
- **Computer track:** computation as a first-class design object -- from
  workload intents down to RTL you synthesize or silicon you buy.

At the highest level there are **no chips, no pins, no nets** -- only
named intents, flows between them, and boundary truth. Implementation is
derived, the same way hematite derives geometry from claims.

| doc | contents |
|---|---|
| [01-overview.md](01-overview.md) | vision; how the two sub-tracks relate; inheritance from the regolith |
| [02-intent-layer.md](02-intent-layer.md) | the top: named intents, flows, boundary, budgets |
| [03-behavioral-layer.md](03-behavioral-layer.md) | the HDL superset: blocks, ports, processes, continuous relations, single-driver ownership |
| [04-structural-layer.md](04-structural-layer.md) | binding to real components, packages, pins, layout; DRC/ERC; PVT corners |
| [05-computer-track.md](05-computer-track.md) | workloads -> architecture contracts -> implementation (buy or build) |
| [06-lowering.md](06-lowering.md) | the elec L0-L6 stack and checks per level |
| [07-vocabulary-sketch.md](07-vocabulary-sketch.md) | draft keyword tables mapped to the regolith |
| [08-open-questions.md](08-open-questions.md) | the EOPEN list |
| [09-hdl-coverage.md](09-hdl-coverage.md) | the HDL coverage matrix |
| [10-power-layer.md](10-power-layer.md) | facility power distribution: the fourth `NetDiscipline`, its vocabulary, discipline rules, claim forms (WO-132) |

Status: the core is [SETTLED] as of 0.10 -- the boundary/interior
intent rule, the event-bounded hybrid semantics (03 sec. 1a), the
analog net discipline, host binding, the component record schema, and
the computer track's realization ledger were each settled by worked
examples (16 single-file designs plus the ten-file Kestrel project),
and the EOPEN queue is empty ([08-open-questions.md](08-open-questions.md)). What keeps this
track honestly younger than mech: it has not been implemented against,
and its vocabulary tables (`07`) remain a sketch in layout though not
in substance. Naming (EOPEN-1) is the one open decision.

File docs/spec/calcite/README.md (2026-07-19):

# calcite -- the civil/architectural track (`.calx`)

Chartered cycle 26 (D133), elaborated cycle 27 (D139): spaces +
structure + envelope over the shared regolith; loads and
building-code compliance as pack content; structural evidence
through the same obligation pipeline (feldspar is the frame/FEA
home). The name's earlier life as the fluid track's draft (`.calc`,
dead since D93) is unrelated; the civil track uses `.calx`.

Reading order:

- [01-charter.md](01-charter.md) -- the SETTLED v1 charter: scope, the three
  artifact families, lowering shape, non-goals with reopen criteria,
  corpus plan. Still the normative root; 02-04 elaborate it.
- [02-language.md](02-language.md) -- sites/grids, spaces, circulation nets, members,
  transfers, structures (the load-path net), loads, envelope
  assemblies, claims, cross-track composition, vocabulary.
- [03-lowering.md](03-lowering.md) -- the L0-L6 table, elaboration rules, the two
  net disciplines (E0204-E0209), the `frame` payload field list,
  obligation shapes, the ship surface.
- [04-open-questions.md](04-open-questions.md) -- deferrals with reopen criteria ONLY (the
  COPEN queue is empty by construction).

Corpus: `examples/tracks/calcite/` (bus_shelter, pole_barn,
footbridge, retaining_wall) + `examples/flagships/small_office/` (the
cross-track flagship: `.calx` + `.fluo` + `.cupr`).

Status: elaboration complete, awaiting owner ratification (WO-46
flips on ratification); front end = WO-47, lowering + `std.civil`
packs = WO-48, drawing sheets = WO-50 (D140).

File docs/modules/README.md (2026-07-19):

# Module contract docs

One file per `crates/regolith-*` crate, each a concise WHY/WHAT contract
for that crate's public API surface, with one anchor per symbol (or
tight symbol group) so `frob:doc` edges in the Rust source have a real
target. These are companions to -- not replacements for -- the
normative spec: where a spec section already describes a surface, the
crate doc points at it instead of duplicating prose (see
`docs/spec/toolchain/00-architecture.md` AD-1..43 for the crate-level
architecture these expand on).

Rust crates:

- [regolith-util](regolith-util.md) -- bottom-of-layering primitives
  (canonical CBOR, content addressing, hashing).
- [regolith-lower](regolith-lower.md) -- the pass-pipeline driver
  (AD-17).
- [regolith-syntax](regolith-syntax.md) -- lexing/parsing and the
  extension-string registry (AD-14).
- [regolith-sem](regolith-sem.md) -- semantic analysis.
- [regolith-ir](regolith-ir.md) -- the intermediate representations.
- [regolith-oblig](regolith-oblig.md) -- the obligation engine.
- [regolith-qty](regolith-qty.md) -- quantities and units.
- [regolith-diag](regolith-diag.md) -- the one diagnostic renderer
  (AD-7).
- [regolith-api](regolith-api.md) -- the stable API crate.
- [regolith-ls](regolith-ls.md) -- the LSP server.
- [regolith-py](regolith-py.md) -- the `regolith._core` PyO3 FFI
  crate (AD-2/AD-4, marshalling only).

Python packages (python/regolith):

- [py-regolith](py-regolith.md) -- package top level (compiler seam,
  config, errors, plugins, procio, toolenv, progress, schema base).
- [py-orchestrator](py-orchestrator.md) -- the build orchestrator.
- [py-harness](py-harness.md) -- the model harness.
- [py-realizer](py-realizer.md) -- mech/elec/firmware realizers.
- [py-backends](py-backends.md) -- artifact backends (drawings,
  three_d, bom, calc, and friends).
- [py-magnetite](py-magnetite.md) -- the package manager and citation
  models.
- [py-cli](py-cli.md) -- the CLI surface.
- [py-docgen](py-docgen.md) -- documentation generation.

Periphery:

- [tools](tools.md) -- tools/health, tools/stdlib, tools/codegen.
- [demos](demos.md) -- the demo proof packs and their harness.
- [vscode-extension](vscode-extension.md) -- editors/vscode.
- [examples](examples.md) -- examples/ flagship sources.

Entries whose file does not exist yet are planned surface for the
in-progress crates/python sweep (`tickets.md` T-0002); each file is
created together with its `frob:doc` edges.

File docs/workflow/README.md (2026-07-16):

# Implementation Work Orders

Agent-executable decomposition of the roadmap (mech `06-roadmap.md`):
WO-01..19 cover Phases A-B (schemas, parser, the geometry-free
`check` linter, lowering, harness spine); WO-20..29 cover Phases C-E
plus the solver/ship extensions (realizers, numeric solves, the
solver plugin layer + signed evidence per `design/20-solver-abstraction.md`,
rule packs per `design/21-rule-packs.md`, manufacturing backends, and the
lowering output surface per `design/23-lowering-output-surface.md`);
WO-30..37 cover cycles 20-21 (pack contract v2 per
`design/20-solver-abstraction.md` sec. 8, the fluorite fluid track per
`docs/spec/fluorite/`, computed fields, routed runs, the elec
pin-assignment completion, the elec behavioral bodies, and the
firmware realizer); WO-38..41 cover cycle 22 (the developer-tooling
surface per `design/24-developer-tooling.md`: language server, editor
extension, lints + watch, docsgen + scaffolding); WO-42 covers
cycle 24 (realized-domain IRs per AD-25/D128: L4 payload schemas,
realizer promotion, the realized-input channel, the staged build
loop); WO-43..49 cover cycle 26 (D132-D137: the `regolith build`
CLI verb, the AD-26 plugin seam, stdlib v1, the calcite civil track
spec/front-end/lowering, and the FluidPort medium binding);
WO-50..54 cover cycle 27 (D139-D147: drawings/schedules backends
with quality audit, the FeatureProgram producer, fluorite mixing +
gas corpus, pattern libraries, and costing); WO-55..60 cover cycle
30 (D159-D166: the optimization engine per `28-optimization.md`
with `by select` + section search + staged-loop optimization, the
interaction surface per `29-interaction-surface.md` -- pass
diagrams, config doctrine, the `graphite` TUI/GUI package -- and
stdlib growth batch C); WO-62..67 cover cycle 31 (D169-D175:
geometry depth per `30-geometry-lowering.md`, the parity bar +
flagship program per `31-flagships.md`, the stdlib depth program
per `32-stdlib-depth.md` (cross-repo with feldspar WO-23/24), and
CAM verification per `33-cam-verification.md`); WO-68..108 cover
cycles 32-34 (topology/SI/board-correctness/design-testing charters
34-37, the fleet program, and emission/release v2 per
`38-emission-and-release.md`, AD-36); WO-109..122 cover cycle 35
(the rigor campaign, D220..D229, + stdlib organization per
`39-stdlib-organization.md`, AD-37); WO-123..127 cover cycle 36
(debug/bring-up per `40-debug-and-bring-up.md`, AD-38, and artifact
presentation per `41-artifact-presentation.md`, AD-39). As of cycle 21 (D107,
reaffirmed cycles 26 and 27) EVERY remaining work order is zero-shot
dispatchable: no WO requires a design decision its file plus cited
specs does not contain. WO-46's output (the elaborated calcite spec,
executed cycle 27) awaits the owner ratification pass that flips its
Status and un-gates WO-47/48 (the D93 fluorite precedent).
Each `WO-nn-*.md` is self-contained: goal,
normative spec references, deliverables, acceptance criteria,
dependencies. An implementer agent should be able to execute one work
order end-to-end reading only that file plus the referenced spec
sections.

## Layout (taxonomy per D138, cycle 26: spec / workflow / guide)

```
docs/
  spec/                TECHNICAL truth: the regolith + language
                       tracks, and toolchain/ (00-architecture.md
                       AD-1..39, grammar.ebnf, the numbered design
                       charters 10-..41- -- a charter wins over the
                       WO bodies it governs)
  workflow/            PROCESS: this file (ground rules, dispatch
                       protocol, dependency graph, status
                       conventions), work-orders/ (WO-01..127, one
                       file per dispatchable unit), design-log/
                       (dated F*/D* ledgers -- verbatim history)
  guide/               PEOPLE: getting started + per-track teaching
                       guides + authoring guides
```

**Architecture is decided and normative:
`../spec/toolchain/00-architecture.md`**
(AD-1..26). It defines the Rust/Python split, the workspace layout,
the parser stack, the FFI boundary, and the per-WO language
assignment (AD-14). Where an older WO body conflicts with it, the
architecture document wins; WO acceptance criteria stand.

## Ground rules (all work orders)

1. **Languages:** per `00-architecture.md` AD-1/AD-14 and each WO's
   `Language:` header line. Rust: pinned stable toolchain, workspace
   lints, `thiserror` (no `anyhow` in library crates), `tracing`
   everywhere; user-facing failures are `regolith-diag` diagnostics
   (values), `Err` is for infrastructure and bugs. Python 3.12+:
   models are **pydantic v2** (`ConfigDict(frozen=True)`), fallible
   operations return **typani** `Result[T, E]`; user-facing failures
   are error values, never exceptions; exceptions only for
   programmer bugs (`CoreBug` from the boundary included).
2. **Logging:** Rust `tracing` (span per pass, log every resolution
   decision and error path), bridged via pyo3-log; Python module
   logger + dictConfig per `~/.claude/refs/logging.md`. Never
   `print` for diagnostics -- the ONE diagnostic renderer lives in
   `regolith-diag` (AD-7).
3. **Layout** (fixed by WO-01 per AD-2): cargo workspace `crates/`
   (`regolith-util`, `regolith-diag`, `regolith-qty`, `regolith-syntax`, `regolith-sem`,
   `regolith-ir`, `regolith-oblig`, `regolith-api`, `regolith-py`) + Python package
   `python/regolith/` (`compiler.py` facade, `_schema/` generated,
   `orchestrator/`, `harness/`, `magnetite/`, `cli/`), pytest in
   `tests/`, goldens under `tests/golden/`. Strict crate layering;
   `regolith-py` contains marshalling only.
4. **Docs as part of done:** every public symbol gets a one-line
   docstring (Rust `///` included); each WO updates its listed doc
   artifacts in the same change.
5. **ASCII only** in every file. Conventional-commit messages, no
   Co-Authored-By line. Use `frob` utilities (edit staging, outline)
   for Python changes; `make check` must pass before a WO is closed.
6. **Naming:** all names are SETTLED (cycle 9 D78, renamed cycle 10;
   fluorite added cycle 20 D93; magnetite + calcite cycle 26
   D132/D133): languages **hematite** (mechanical, `.hema`),
   **cuprite** (electrical/computer, `.cupr`), **fluorite** (fluid
   circuits, `.fluo`), and **calcite** (civil/architectural, `.calx`
   -- chartered, WO-46..48); package manager **magnetite**
   (`magnetite.toml`; quarry/lodestone are retired names, the
   registry carries no separate name); the umbrella
   distribution/import/CLI name is **regolith** (lockfile
   `regolith.lock`) -- one geology theme. Extension strings live in
   ONE registry module (`regolith-syntax`); nothing else may
   hard-code any of these strings. Note on calcite: its pre-cycle-26
   usage as the fluid track's DRAFT name (with extension `.calc`) is
   dead, and `.calc` stays dead -- the civil track's extension is
   `.calx` (D133); the civil-track name assignment is a fresh
   cycle-26 owner decision.

## Dispatch protocol (every agent, every work order)

An agent picking up a WO must do these IN ORDER; no code before
step 4 is complete.

1. **Read, in order:** this README (ground rules), then
   `00-architecture.md` end-to-end (it is normative and wins over
   the WO body), then the WO itself, then every spec section the
   WO's `Spec:` line names. WO bodies written before cycle 9 may
   still phrase deliverables in Python terms; the `Language:`
   header + architecture doc decide what is actually built.
2. **Plan hierarchically before any leaf.** Decompose the WO
   top-down: deliverables -> components -> functions/types, down to
   leaves that are each trivially implementable, and map the WHOLE
   tree before implementing any single leaf. Identify, per leaf,
   which crate/module it lives in (AD-2 layering), what it depends
   on, and which acceptance criterion covers it.
3. **Write the plan down** as a checklist (TODO.md section or the
   dispatch's tracking mechanism) with one entry per leaf, plus one
   entry per WO acceptance criterion and per doc artifact. The
   checklist is driven to zero before the WO is closed; cut scope is
   recorded as cut, never silently dropped.
4. **Check the plan against the WO's acceptance criteria** -- every
   criterion must be covered by some leaf; every leaf must serve
   some deliverable. Anything in neither list is scope creep: leave
   it out.
5. **Stick to the work order.** The WO's scope is a contract: no
   extra features, no speculative generality, no refactors of
   neighboring code. On spec ambiguity, STOP and escalate to a
   design-log entry; on architecture ambiguity, escalate to
   `00-architecture.md`; never invent or quietly reinterpret.
6. **Close out:** `make check` green, invariant tests the WO enables
   un-reddened (WO-17 placement per AD-11), doc artifacts updated in
   the same change, WO `Status:` line flipped.

## Dependency graph

```
WO-01 scaffolding (hybrid workspace; both languages)
  -> WO-02 units/quantities -> WO-03 intervals/ranges -> WO-04 value sources   [Rust regolith-qty]
  -> WO-06 diagnostics                                                          [Rust regolith-diag]
WO-02..04, WO-06
  -> WO-05 lexer/parser (CST + typed AST)                                       [Rust regolith-syntax]
  -> WO-07 entity DB -> WO-08 query engine -> WO-09 ownership/borrows           [Rust regolith-sem]
  -> WO-10 stages/scopes                                                        [Rust regolith-sem]
  -> WO-11 profile walks (needs WO-05)                                          [Rust regolith-syntax + regolith-sem]
WO-05..11
  -> WO-12 contract IR (interfaces, matings, ledgers)                           [Rust regolith-ir]
  -> WO-13 claims -> obligations/evidence schemas                               [Rust regolith-oblig]
WO-06, WO-13
  -> WO-18 FFI bridge + schema pipeline + typed facade                          [both]
WO-12..13, WO-18
  -> WO-14 lockfile                                                             [Python orchestrator]
  -> WO-16 package/registry loader                                              [Python magnetite]
WO-05..13, WO-18
  -> WO-19 lowering pipeline (AST->entities->IR->obligations->discharge)        [Rust regolith-lower]
     -> gates WO-15 golden corpus + the bulk of WO-17
WO-05..14, 16, 18, 19 -> WO-15 `check` CLI + golden tests over examples/        [Python cli]

WO-13, WO-18, harness spine
  -> WO-20 solver plugin layer (packs + subprocess adapter)                     [Python harness; AD-19]
WO-20, WO-16
  -> WO-21 evidence signing + trust floors (adds INV-28)                        [both; AD-20]
WO-19, WO-20
  -> WO-22 mech geometry realizer (feature IR -> OCCT -> STEP)                  [Python realizer]
  -> WO-26 harness completion (claim-form lowering, numeric tier, planners)     [both]
WO-12, WO-11
  -> WO-23 L2 numeric solves (statics, stiffness, sketch) [Rust regolith-ir `solve`]
WO-16, WO-19, WO-20
  -> WO-24 elec structural realizer (bind -> netlist -> KiCad layout)           [Python realizer]
WO-22, WO-24, WO-14, WO-21
  -> WO-25 manufacturing backends + `regolith ship` (L6)                        [Python backends/cli]
WO-20, WO-21, WO-22
  -> WO-27 reference external FEA pack (packs/feldspar, separate distribution)  [Python, own wheel]
WO-05, WO-08, WO-19 (static half; realized-fact half also WO-22/24)
  -> WO-28 rule packs: DFM/DRC/ERC authoring surface + engine                   [Rust + Python cli; AD-21]
WO-19 (+ the WO-05 residue it selects)
  -> WO-29 lowering output surface (feature program, binding bridge,
     domain entities, connect->Mating)                                          [Rust regolith-lower/-sem/-syntax + schema; Python bridge]
     -> gates the END-TO-END halves of WO-22/WO-24, the WO-28 engine
        remainder (deliverables 3-8), and WO-23's connect->Mating cut
        (see `design/23-lowering-output-surface.md`, the F96 pattern)

WO-20, WO-21
  -> WO-30 pack contract v2 (structured coverage, payload-ref channel,
     given resolution + regimes, kind competition)                              [Rust regolith-oblig + Python harness/orchestrator]
     -> gates WO-27's remaining conformance surface + feldspar M4/M6
WO-05, WO-07/08
  -> WO-31 fluorite front end (.fluo, grammar/CST, AD-23 net core +
     elec discipline refit)                                                     [Rust]
WO-31, WO-30, WO-22 (engine half)
  -> WO-32 fluorite lowering (flownet payload + the routed-geometry
     extraction seam)                                                           [Rust + Python]
WO-30, WO-13/19
  -> WO-33 computed indexed fields (compute claims, field payloads)             [Rust + Python]
WO-32 (the extraction seam)
  -> WO-34 routed runs (cuprite harness: blocks, extracted lengths)             [Rust + Python]
WO-24 (engine half), WO-16
  -> WO-35 elec assignment completion (pin-mux solver, real-KiCad gate)         [Python realizer]
WO-05, WO-11
  -> WO-36 elec behavioral bodies (typed CST -> ConverterGraph, INV-16)         [Rust]
WO-35, WO-24 (engine half), WO-36, WO-16
  -> WO-37 firmware realizer (contract header, BSP codegen, extern bindings)    [Python realizer]
WO-05..19 (done)
  -> WO-38 language server regolith-ls (LSP on the compiler crates; AD-24)      [Rust]
     -> WO-39 editor extension `lithos` (generated grammars + bundled server)   [TypeScript editors/vscode]
        (grammar half of WO-39 is dispatchable before WO-38)
WO-06, WO-19, WO-16
  -> WO-40 lint framework + `check --watch` (Lint code family, [lints] config)  [Rust + Python]
WO-05, WO-16, WO-18
  -> WO-41 docsgen (`regolith doc`) + scaffolding (`magnetite new`)                [Python]
WO-30, WO-22 (engine half), WO-24 (engine half), WO-32 (D1/D2)
  -> WO-42 realized-domain IRs (L4 schemas, realizer promotion,
     realized-input channel, staged build loop; AD-25/D128)                     [Rust + Python]
     -> gates WO-32 D4b end-to-end, WO-34 extraction over real
        records, and WO-25's IR-derived reports
WO-42 (done), WO-25 framework
  -> WO-43 `regolith build [--release]` CLI verb (D136)                          [Python cli]
WO-20, WO-21, WO-25 framework, WO-37
  -> WO-44 plugin architecture v1 (`regolith.plugins`, AD-26/D134)               [Python]
WO-16, (WO-44 preferred)
  -> WO-45 stdlib v1 (`stdlib/` std.* packages, D135)                            [Python + records]
docs/spec/calcite/01-charter.md (SETTLED, D133)
  -> WO-46 calcite spec elaboration (docs + corpus; owner-ratified)              [docs]
     -> WO-47 calcite front end (.calx, grammar/CST, civil net disciplines)      [Rust]
        -> WO-48 calcite lowering + std.civil (frame IR per AD-25; needs WO-45;
           code-pack half also WO-28 engine)                                     [Rust + Python]
WO-31, WO-32 (done)
  -> WO-49 FluidPort medium binding + FOPEN-1 (closes WO-32's last item)         [Rust]
     -> WO-52 fluorite Mixer + compressible-regime corpus (D141/D142)            [Rust]
WO-25 framework, WO-42 (done), (WO-44 preferred; civil leg after WO-48)
  -> WO-50 drawings + schedules backends (DrawingModel IR, quality audit;
     AD-27/D140)                                                                 [Rust + Python]
WO-42 (done), WO-11 (done), WO-29 (done)
  -> WO-51 FeatureProgram producer (Walk promotion + cavity->flow_paths;
     D143 -- closes WO-22's end-to-end half)                                     [Rust + Python]
WO-45, WO-44, WO-41, WO-28 engine remainder
  -> WO-53 pattern libraries v1 (seed packs + advise recognition;
     AD-28/D144)                                                                 [packages + Python]
WO-30 (done), WO-45, WO-44 (+ WO-48/planner gates per estimator)
  -> WO-54 costing v1 (profiles, records, estimators, itemized evidence;
     AD-29/D147)                                                                 [Rust + Python + records]
WO-30/42 (done), NogoodCache (done), WO-14 causes
  -> WO-55 optimization engine + THE cycle-30 schema bump (AD-30/D159/D160)      [Rust schemas + Python orchestrator/cli]
     -> WO-56 `by select` + calcite section search (D161; corpus verdicts)       [Rust + Python]
     -> WO-57 staged-loop (realized-domain) optimization (D162)                  [Python]
        (WO-56/57 serialize at integration: shared orchestrator/CLI surfaces)
     -> WO-58's trace-sheet slice; WO-59's trace view
WO-50 (done)
  -> WO-58 pass-visualization diagram producers (D165; bdf-shaped views)         [Python backends]
     -> WO-59 graphite v1: config + TUI + local-web GUI (AD-31/D163/D164)        [Python; apps/graphite]
        (WO-59 deliverable 1, `regolith config`, is independent -- may land first)
WO-45/53 conventions (done)
  -> WO-60 stdlib growth batch C (D166; feeds WO-56's demo, soft)                [records]
WO-55 (bump first), WO-58's landed layout/wiring conventions
  -> WO-61 ContractGraphPayload + contract-graph sheet (D167; the ONE
     serialized follow-up bump; completes WO-58's escalated D2)                  [Rust + Python]
WO-22/42/51/55/57 (done)
  -> WO-62 geometry depth: closure solve, gauge source, coverage ledger,
     RealizedAssembly (AD-32; owns cycle-31's bump 23->24)                       [Rust + Python]
WO-50 (done), WO-55 (done)
  -> WO-63 parity report in ship --explain (AD-33/D170)                          [Python]
31-flagships.md (charter)
  -> WO-64 flagship-1 printer: phase A contract-first NOW; B/C after
     WO-62+63 (AD-33/D172)                                                       [corpus authoring]
WO-45/53/60 conventions (done)
  -> WO-66 stdlib depth wave 1: tools/stdlib generation + exhaustive
     families (AD-34/D174; feldspar half = its WO-24, after its WO-23)           [Python + records]
WO-51/42/20/44 (done), (WO-66 soft for machine/tool records)
  -> WO-67 CAM verification v1: std.cam check-mode pack (AD-35/D175)             [Python pack]
feldspar WO-23 (its repo: tributary load paths; D173)
  -> WO-65 five-design section-search verdict flip (the WO-56/F108
     residual's named reopen; un-gated -- WO-68 landed both of its
     escalated blockers, D181)                                                   [Python]
WO-62 (done)
  -> WO-68 forall-combo obligation emission + `in registry(...)`
     domains + FrameMember.section_domain (D181; owns bump 24->25,
     the D168 train rule) -- DONE, un-gates WO-65's remainder         [Rust regolith-syntax/-lower/-oblig + Python]

D256 hash window (cycle 37; serializes before every other lithos
code WO listed below, per its own design-log entry)
  -> WO-138 std.fluid property depth: roughness + IAPWS/NASA-Glenn
     point tables + the six missing media (D258.1/F158)              [records + tools/stdlib]
     -> WO-139 friction-factor model (64/Re + Haaland; D97 transition
        honesty; D258.3)                                             [Python harness]
        -> WO-140 minor losses (Hooper 2-K/Darby 3-K/Borda-Carnot;
           Crane/Idelchik owner-gated out; D258.2)                    [records + Python]
        -> WO-141 feldspar fluids pack bridge, LITHOS HALF ONLY (the
           feldspar half is its own already-dispatched WO; F159)      [Python orchestrator/harness]
        -> WO-143 Moody calc-sheet figure (`diagram.moody`, charter 41
           rule 6, AD-39 visual proof)                                [Python backends/drawings]
     -> WO-142 heat-transfer correlation growth (feldspar-side +
        conditional thin lithos pad check; parallel after WO-138)     [feldspar repo (+ Python)]
  WO-140, WO-141 (lithos half), WO-143
     -> WO-144 fluid demo close-out (small_office waiver burn-down,
        demo run + PROOF.md, F152 honesty bar; regime/fill half
        additionally gated on the F157 claim-shape slice)             [corpus + demos]

D256 hash window
  -> WO-145 processors first slice: `Cited`/`Citation` models +
     health tightening + ti.mcu MSP430FR5 family (D257; DigiKey
     stays discovery-only and out of this WO entirely)                [records + Python]

WO-146 traced-profile format spec + `.rgp` ratification (D261.3;
  docs-only, NOT window-gated -- may run before/parallel to D256)     [docs]
D256 hash window, WO-146
  -> WO-147 `.rgp` schema + extern-profile elaboration; OWNS the
     cycle-37 SCHEMA_VERSION bump (D261.4; carries the WO-141
     FlownetPayload/DischargeRequest claim-target passenger)          [Rust]
     -> WO-148 traced-profile Python realizer + citation +
        artifact-index consumption (D261.4)                          [Python]
     -> WO-149 native-walk fitting / "promote to native profile"
        (v1.5, UNSCHEDULED -- reopen criterion only, D261.4)          [Rust + Python]

D256 hash window
  -> WO-150 no bare dimensioned values in artifacts: structural
     unreachability + sweep half + INV-34(-TBD) proof argument
     (D262) -- precedes WO-143 (the Moody sheet renders through
     THIS WO's enforced interfaces)                                   [Rust + Python]

D256 hash window
  -> WO-151 waveform/mask record class + spec + the authored-posture
     refusal (E11xx `bringup_expectation_authored_posture`; D263.1-3)  [docs + Python]
     -> WO-152 waveform/mask sheet rendering + AUTHORED badge
        (D263.1)                                                      [Python]

D256 hash window
  -> WO-153 the in-house process-I/O seam `regolith.procio` (D264.1;
     six call sites migrate, AD-19 wire protocol kept verbatim,
     tools/health stays raw)                                          [Python]

(docs-only, not window-gated -- may run any time, parallel to WO-153)
  -> WO-154 sim/timing gate spec deltas + INV-<N> ledger entry text
     (D264.3-6)                                                        [docs]

WO-153, WO-154
  -> WO-155 cuprite functional sim gate: source-generic
     `hdl.sim_assert`, stimulus-binding grammar, `signal_table`
     payload, content-address cache (D264.2/3/4/5)                    [Rust + Python]
WO-145 (done), WO-155
  -> WO-156 timing closure v1: `budget kind=timing` grounded over
     WO-145's cited part values + route-derived delay (D264.2/6)      [records + Rust + Python]
WO-155
  -> WO-157 sim/timing fleet adoption: census flip, waiver burn,
     coverage/named-absence sweep, E1105 cross-check, INV-<N>
     ship-path check (D264; F152 honesty bar)                         [corpus + Python + goldens]
     (WO-156 additionally gates the timing-half rows; sim-half may
     land first as an honest partial)
WO-157
  -> WO-158 riscv_hart_rv1 sim demo: census-rise PROOF.md +
     expected_signals-vs-sim E1105 cross-check demo beat             [demos + corpus]
```

Sequencing (cycle 26 restatement; supersedes the D101/D107/D128
paragraphs -- their history is in the design logs): the live queue
and its order are maintained in ONE place, TODO.md's "DISPATCH
QUEUE" section. Structural constraints that stay true regardless of
queue order: anything bumping `SCHEMA_VERSION` serializes with
anything else that does (WO-48, WO-50, WO-54 all add schemas);
WO-40 and WO-51 serialize with anything editing regolith-lower's
pass driver; WO-47/48 are gated on WO-46's ratification; WO-45
wants WO-44 first (else its registrations move twice); WO-25's
remainder wants WO-43; WO-52 lands with or after WO-49 (it extends
that WO's consistency check); WO-53 wants WO-45 + the WO-28 engine
remainder; WO-54's estimator set scopes to its landed gates (its
dependency note).

WO-02/03/04/06 are parallelizable after WO-01. WO-07..11 are
parallelizable after WO-05. WO-17 (the invariant suite,
regolith/13) starts after WO-06 and grows with every WO: a WO is not
done while it reddens an invariant test it enables; test placement
per AD-11 (each INV family lands beside its enforcing layer;
cross-boundary INVs in pytest).

## Stub convention (architecture-first scaffolding)

The crates are being scaffolded architecture-first: the full public
type surface, module layout, and tests land first; the logic bodies a
less-capable agent can fill follow. Every deferred body is a greppable
marker so the remaining work is a single search:

```
grep -rn 'todo!("STUB WO-' crates/     # Rust bodies still to implement
```

Each marker names its WO and what it must do
(`todo!("STUB WO-03: outward-rounded endpoint sum ...")`). Trivial data
plumbing (constructors, accessors, serde derives, builders) is
implemented inline so types are usable and tests compile; only real
logic is stubbed. Tests for stubbed behaviour are written now and
`#[ignore]`-d with a reason ending `... pending`; un-ignoring them is
the acceptance signal when the body lands. A WO is `done` only when its
STUB markers are gone, its ignored tests pass, and `make check` is
green.

## Status

Mark each WO's Status line (`todo` / `in-progress` / `done` / `cut`)
in place; a cut must name why and where the scope went.

### Status-line vocabulary (HEALTH-F4, WO-116; normalized 2026-07-13)

The first word after `Status:` is the ONLY token
`tools/health/consistency.py::_wo_status_map` parses (everything
after it is free-text detail, parenthetical or not, and is never
matched). Every WO file's first word MUST be one of this enumerated
set -- no synonyms, no alternate casing, no compound hyphenation
inventing a new word:

- `todo` / `open` -- never started (`open` is the sanctioned
  synonym already established across the cycle-35 queue, WO-109..117;
  new WOs may use either word, but not a third spelling).
- `in-progress` -- actively worked, not yet landed end to end.
- `honest-partial` / `partial` -- landed with a named, evidence-backed
  residual the file's own close-out ledger records (`partial` is the
  bare/lighter-weight spelling for a residual noted inline rather than
  in a separate ledger section; both are non-gating by construction,
  see below). Former stragglers `SCALAR HALF DONE`,
  `landed-with-accepted-residuals`, `done-honest-partial` all meant
  exactly `honest-partial` and are retired to it.
- `phase` -- a multi-phase WO tracks sub-phase completion inline
  (`phase A done; phase B seeded ...`); non-gating, same as
  `honest-partial`.
- `done` -- every deliverable and acceptance criterion landed
  (former straggler `DONE`, any casing variant, retired to this).
- `cut` -- scope explicitly dropped; the file must name why and
  where the scope went (see above).

The consistency check's gating rule only cares whether the word
starts with `done` or `cut` (queue-done + file-done/cut is not a
lie) versus `todo` (queue-done + file-todo IS the gating lie) --
everything else, including `honest-partial`, is a non-gating
reported residual by design. Keeping the vocabulary to this
enumerated set (rather than ad hoc phrases) is what lets that
`.startswith` check and any future stricter enum match stay correct
without also special-casing prose.

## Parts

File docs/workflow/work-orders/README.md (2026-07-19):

# Work orders index

Every dispatchable unit of work, one file per WO. This is a link index
only -- status, dependencies, and acceptance criteria live in each WO's
own `Status:`/`Depends:` header and body; the live dispatch queue is
`tickets.md` (`frob ticket doable`), not this table.

| WO | file |
|---|---|
| WO-01-scaffolding | [WO-01-scaffolding.md](WO-01-scaffolding.md) |
| WO-02-quantity-core | [WO-02-quantity-core.md](WO-02-quantity-core.md) |
| WO-03-intervals-ranges | [WO-03-intervals-ranges.md](WO-03-intervals-ranges.md) |
| WO-04-value-sources | [WO-04-value-sources.md](WO-04-value-sources.md) |
| WO-05-parser | [WO-05-parser.md](WO-05-parser.md) |
| WO-06-diagnostics | [WO-06-diagnostics.md](WO-06-diagnostics.md) |
| WO-07-entity-db | [WO-07-entity-db.md](WO-07-entity-db.md) |
| WO-08-query-engine | [WO-08-query-engine.md](WO-08-query-engine.md) |
| WO-09-ownership-borrows | [WO-09-ownership-borrows.md](WO-09-ownership-borrows.md) |
| WO-10-stages-scopes | [WO-10-stages-scopes.md](WO-10-stages-scopes.md) |
| WO-11-profiles | [WO-11-profiles.md](WO-11-profiles.md) |
| WO-12-contract-ir | [WO-12-contract-ir.md](WO-12-contract-ir.md) |
| WO-13-obligations | [WO-13-obligations.md](WO-13-obligations.md) |
| WO-14-lockfile | [WO-14-lockfile.md](WO-14-lockfile.md) |
| WO-15-check-cli | [WO-15-check-cli.md](WO-15-check-cli.md) |
| WO-16-registry-loader | [WO-16-registry-loader.md](WO-16-registry-loader.md) |
| WO-17-invariant-suite | [WO-17-invariant-suite.md](WO-17-invariant-suite.md) |
| WO-18-ffi-bridge | [WO-18-ffi-bridge.md](WO-18-ffi-bridge.md) |
| WO-19-lowering-pipeline | [WO-19-lowering-pipeline.md](WO-19-lowering-pipeline.md) |
| WO-20-solver-plugin-layer | [WO-20-solver-plugin-layer.md](WO-20-solver-plugin-layer.md) |
| WO-21-evidence-signing | [WO-21-evidence-signing.md](WO-21-evidence-signing.md) |
| WO-22-mech-geometry-realizer | [WO-22-mech-geometry-realizer.md](WO-22-mech-geometry-realizer.md) |
| WO-23-l2-numeric-solves | [WO-23-l2-numeric-solves.md](WO-23-l2-numeric-solves.md) |
| WO-24-elec-structural-realizer | [WO-24-elec-structural-realizer.md](WO-24-elec-structural-realizer.md) |
| WO-25-manufacturing-backends | [WO-25-manufacturing-backends.md](WO-25-manufacturing-backends.md) |
| WO-26-harness-completion | [WO-26-harness-completion.md](WO-26-harness-completion.md) |
| WO-27-reference-fea-pack | [WO-27-reference-fea-pack.md](WO-27-reference-fea-pack.md) |
| WO-28-rule-packs | [WO-28-rule-packs.md](WO-28-rule-packs.md) |
| WO-29-lowering-output-surface | [WO-29-lowering-output-surface.md](WO-29-lowering-output-surface.md) |
| WO-30-pack-contract-v2 | [WO-30-pack-contract-v2.md](WO-30-pack-contract-v2.md) |
| WO-31-fluorite-front-end | [WO-31-fluorite-front-end.md](WO-31-fluorite-front-end.md) |
| WO-32-fluorite-lowering | [WO-32-fluorite-lowering.md](WO-32-fluorite-lowering.md) |
| WO-33-computed-fields | [WO-33-computed-fields.md](WO-33-computed-fields.md) |
| WO-34-routed-runs | [WO-34-routed-runs.md](WO-34-routed-runs.md) |
| WO-35-elec-assignment | [WO-35-elec-assignment.md](WO-35-elec-assignment.md) |
| WO-36-elec-behavioral-bodies | [WO-36-elec-behavioral-bodies.md](WO-36-elec-behavioral-bodies.md) |
| WO-37-firmware-realizer | [WO-37-firmware-realizer.md](WO-37-firmware-realizer.md) |
| WO-38-language-server | [WO-38-language-server.md](WO-38-language-server.md) |
| WO-39-editor-extension | [WO-39-editor-extension.md](WO-39-editor-extension.md) |
| WO-40-lints-and-watch | [WO-40-lints-and-watch.md](WO-40-lints-and-watch.md) |
| WO-41-docsgen-and-scaffolding | [WO-41-docsgen-and-scaffolding.md](WO-41-docsgen-and-scaffolding.md) |
| WO-42-domain-irs | [WO-42-domain-irs.md](WO-42-domain-irs.md) |
| WO-43-build-cli | [WO-43-build-cli.md](WO-43-build-cli.md) |
| WO-44-plugin-architecture | [WO-44-plugin-architecture.md](WO-44-plugin-architecture.md) |
| WO-45-stdlib-v1 | [WO-45-stdlib-v1.md](WO-45-stdlib-v1.md) |
| WO-46-calcite-spec | [WO-46-calcite-spec.md](WO-46-calcite-spec.md) |
| WO-47-calcite-front-end | [WO-47-calcite-front-end.md](WO-47-calcite-front-end.md) |
| WO-48-calcite-lowering | [WO-48-calcite-lowering.md](WO-48-calcite-lowering.md) |
| WO-49-fluidport-binding | [WO-49-fluidport-binding.md](WO-49-fluidport-binding.md) |
| WO-50-drawings-backends | [WO-50-drawings-backends.md](WO-50-drawings-backends.md) |
| WO-51-feature-program-producer | [WO-51-feature-program-producer.md](WO-51-feature-program-producer.md) |
| WO-52-fluorite-mixing-and-gas | [WO-52-fluorite-mixing-and-gas.md](WO-52-fluorite-mixing-and-gas.md) |
| WO-53-pattern-libraries | [WO-53-pattern-libraries.md](WO-53-pattern-libraries.md) |
| WO-54-costing | [WO-54-costing.md](WO-54-costing.md) |
| WO-55-optimization-engine | [WO-55-optimization-engine.md](WO-55-optimization-engine.md) |
| WO-56-discrete-selection | [WO-56-discrete-selection.md](WO-56-discrete-selection.md) |
| WO-57-staged-optimization | [WO-57-staged-optimization.md](WO-57-staged-optimization.md) |
| WO-58-pass-diagrams | [WO-58-pass-diagrams.md](WO-58-pass-diagrams.md) |
| WO-59-graphite | [WO-59-graphite.md](WO-59-graphite.md) |
| WO-60-stdlib-growth | [WO-60-stdlib-growth.md](WO-60-stdlib-growth.md) |
| WO-61-contract-graph-payload | [WO-61-contract-graph-payload.md](WO-61-contract-graph-payload.md) |
| WO-62-geometry-depth | [WO-62-geometry-depth.md](WO-62-geometry-depth.md) |
| WO-63-parity-report | [WO-63-parity-report.md](WO-63-parity-report.md) |
| WO-64-flagship-printer | [WO-64-flagship-printer.md](WO-64-flagship-printer.md) |
| WO-65-section-verdicts | [WO-65-section-verdicts.md](WO-65-section-verdicts.md) |
| WO-66-stdlib-depth | [WO-66-stdlib-depth.md](WO-66-stdlib-depth.md) |
| WO-67-cam-verification | [WO-67-cam-verification.md](WO-67-cam-verification.md) |
| WO-68-forall-emission-and-domains | [WO-68-forall-emission-and-domains.md](WO-68-forall-emission-and-domains.md) |
| WO-69-plan-linkage | [WO-69-plan-linkage.md](WO-69-plan-linkage.md) |
| WO-70-flagship-uav | [WO-70-flagship-uav.md](WO-70-flagship-uav.md) |
| WO-71-flagship-mainboard | [WO-71-flagship-mainboard.md](WO-71-flagship-mainboard.md) |
| WO-72-flagship-cnc-router | [WO-72-flagship-cnc-router.md](WO-72-flagship-cnc-router.md) |
| WO-73-flagship-hydro-press | [WO-73-flagship-hydro-press.md](WO-73-flagship-hydro-press.md) |
| WO-74-flagship-pavilion | [WO-74-flagship-pavilion.md](WO-74-flagship-pavilion.md) |
| WO-75-flagship-robot-arm | [WO-75-flagship-robot-arm.md](WO-75-flagship-robot-arm.md) |
| WO-76-fea-loop | [WO-76-fea-loop.md](WO-76-fea-loop.md) |
| WO-77-material-removal-vocabulary | [WO-77-material-removal-vocabulary.md](WO-77-material-removal-vocabulary.md) |
| WO-78-signal-integrity | [WO-78-signal-integrity.md](WO-78-signal-integrity.md) |
| WO-79-board-correctness | [WO-79-board-correctness.md](WO-79-board-correctness.md) |
| WO-80-model-pin | [WO-80-model-pin.md](WO-80-model-pin.md) |
| WO-81-flagship-riscv | [WO-81-flagship-riscv.md](WO-81-flagship-riscv.md) |
| WO-82-hdl-verification | [WO-82-hdl-verification.md](WO-82-hdl-verification.md) |
| WO-83-design-testing | [WO-83-design-testing.md](WO-83-design-testing.md) |
| WO-84-record-path-resolution | [WO-84-record-path-resolution.md](WO-84-record-path-resolution.md) |
| WO-85-load-lowering-cluster | [WO-85-load-lowering-cluster.md](WO-85-load-lowering-cluster.md) |
| WO-86-cg-moment-budget | [WO-86-cg-moment-budget.md](WO-86-cg-moment-budget.md) |
| WO-87-elec-entity-population | [WO-87-elec-entity-population.md](WO-87-elec-entity-population.md) |
| WO-88-convertergraph-ffi | [WO-88-convertergraph-ffi.md](WO-88-convertergraph-ffi.md) |
| WO-89-digital-vocabulary | [WO-89-digital-vocabulary.md](WO-89-digital-vocabulary.md) |
| WO-90-opaque-require-and-forall-plural | [WO-90-opaque-require-and-forall-plural.md](WO-90-opaque-require-and-forall-plural.md) |
| WO-92-conformance-windows | [WO-92-conformance-windows.md](WO-92-conformance-windows.md) |
| WO-93-flagship-cubesat | [WO-93-flagship-cubesat.md](WO-93-flagship-cubesat.md) |
| WO-94-flagship-espresso | [WO-94-flagship-espresso.md](WO-94-flagship-espresso.md) |
| WO-96-assembly-instructions | [WO-96-assembly-instructions.md](WO-96-assembly-instructions.md) |
| WO-97-bounded-sketch-optimize | [WO-97-bounded-sketch-optimize.md](WO-97-bounded-sketch-optimize.md) |
| WO-98-release-acceptance-ledger | [WO-98-release-acceptance-ledger.md](WO-98-release-acceptance-ledger.md) |
| WO-99-emission-registries-and-package | [WO-99-emission-registries-and-package.md](WO-99-emission-registries-and-package.md) |
| WO-100-real-views-and-3d | [WO-100-real-views-and-3d.md](WO-100-real-views-and-3d.md) |
| WO-101-bom-v2-cost-schedule | [WO-101-bom-v2-cost-schedule.md](WO-101-bom-v2-cost-schedule.md) |
| WO-102-computer-track-backends | [WO-102-computer-track-backends.md](WO-102-computer-track-backends.md) |
| WO-103-real-kicad-outline-and-gerbers | [WO-103-real-kicad-outline-and-gerbers.md](WO-103-real-kicad-outline-and-gerbers.md) |
| WO-104-geometry-schema-wave | [WO-104-geometry-schema-wave.md](WO-104-geometry-schema-wave.md) |
| WO-105-fleet-ship-campaign | [WO-105-fleet-ship-campaign.md](WO-105-fleet-ship-campaign.md) |
| WO-106-fleet-release-gate | [WO-106-fleet-release-gate.md](WO-106-fleet-release-gate.md) |
| WO-107-log-readability-and-color | [WO-107-log-readability-and-color.md](WO-107-log-readability-and-color.md) |
| WO-108-optimization-proof-packs | [WO-108-optimization-proof-packs.md](WO-108-optimization-proof-packs.md) |
| WO-109-claim-routing-by-call-form | [WO-109-claim-routing-by-call-form.md](WO-109-claim-routing-by-call-form.md) |
| WO-110-builtin-model-depth | [WO-110-builtin-model-depth.md](WO-110-builtin-model-depth.md) |
| WO-111-feldspar-model-growth | [WO-111-feldspar-model-growth.md](WO-111-feldspar-model-growth.md) |
| WO-112-lowering-surface-expansion | [WO-112-lowering-surface-expansion.md](WO-112-lowering-surface-expansion.md) |
| WO-113-corpus-enrichment-and-waiver-burndown | [WO-113-corpus-enrichment-and-waiver-burndown.md](WO-113-corpus-enrichment-and-waiver-burndown.md) |
| WO-114-calc-package-audit-trail | [WO-114-calc-package-audit-trail.md](WO-114-calc-package-audit-trail.md) |
| WO-115-feature-proof-packs | [WO-115-feature-proof-packs.md](WO-115-feature-proof-packs.md) |
| WO-116-cycle34-residue-burndown | [WO-116-cycle34-residue-burndown.md](WO-116-cycle34-residue-burndown.md) |
| WO-117-verification-and-health-v2 | [WO-117-verification-and-health-v2.md](WO-117-verification-and-health-v2.md) |
| WO-118-stdlib-organization-alignment | [WO-118-stdlib-organization-alignment.md](WO-118-stdlib-organization-alignment.md) |
| WO-119-graphite-progress-feedback | [WO-119-graphite-progress-feedback.md](WO-119-graphite-progress-feedback.md) |
| WO-120-vscode-extension-parity | [WO-120-vscode-extension-parity.md](WO-120-vscode-extension-parity.md) |
| WO-121-docs-refresh-and-guides | [WO-121-docs-refresh-and-guides.md](WO-121-docs-refresh-and-guides.md) |
| WO-122-bound-parse-hardening | [WO-122-bound-parse-hardening.md](WO-122-bound-parse-hardening.md) |
| WO-123-artifact-presentation-v2 | [WO-123-artifact-presentation-v2.md](WO-123-artifact-presentation-v2.md) |
| WO-124-board-fab-completeness | [WO-124-board-fab-completeness.md](WO-124-board-fab-completeness.md) |
| WO-125-debug-profile-and-taps | [WO-125-debug-profile-and-taps.md](WO-125-debug-profile-and-taps.md) |
| WO-125-plan | [WO-125-plan.md](WO-125-plan.md) |
| WO-126-bringup-harness-pack | [WO-126-bringup-harness-pack.md](WO-126-bringup-harness-pack.md) |
| WO-127-la-jig-exemplar | [WO-127-la-jig-exemplar.md](WO-127-la-jig-exemplar.md) |
| WO-128-resolved-numerics-and-units | [WO-128-resolved-numerics-and-units.md](WO-128-resolved-numerics-and-units.md) |
| WO-129-injection-channel | [WO-129-injection-channel.md](WO-129-injection-channel.md) |
| WO-130-universal-artifact-surface | [WO-130-universal-artifact-surface.md](WO-130-universal-artifact-surface.md) |
| WO-131-one-code-space-and-explain | [WO-131-one-code-space-and-explain.md](WO-131-one-code-space-and-explain.md) |
| WO-132-power-front-end | [WO-132-power-front-end.md](WO-132-power-front-end.md) |
| WO-133-power-lowering | [WO-133-power-lowering.md](WO-133-power-lowering.md) |
| WO-134-std-power-records | [WO-134-std-power-records.md](WO-134-std-power-records.md) |
| WO-135-power-models | [WO-135-power-models.md](WO-135-power-models.md) |
| WO-136-power-calcite-tandem | [WO-136-power-calcite-tandem.md](WO-136-power-calcite-tandem.md) |
| WO-137-factory-flagship | [WO-137-factory-flagship.md](WO-137-factory-flagship.md) |
| WO-138-fluid-property-depth | [WO-138-fluid-property-depth.md](WO-138-fluid-property-depth.md) |
| WO-139-friction-factor-model | [WO-139-friction-factor-model.md](WO-139-friction-factor-model.md) |
| WO-140-minor-losses | [WO-140-minor-losses.md](WO-140-minor-losses.md) |
| WO-141-fluids-pack-bridge | [WO-141-fluids-pack-bridge.md](WO-141-fluids-pack-bridge.md) |
| WO-142-heat-transfer-correlation-growth | [WO-142-heat-transfer-correlation-growth.md](WO-142-heat-transfer-correlation-growth.md) |
| WO-143-moody-calc-sheet-figure | [WO-143-moody-calc-sheet-figure.md](WO-143-moody-calc-sheet-figure.md) |
| WO-144-fluid-demo-closeout | [WO-144-fluid-demo-closeout.md](WO-144-fluid-demo-closeout.md) |
| WO-145-processors-first-slice | [WO-145-processors-first-slice.md](WO-145-processors-first-slice.md) |
| WO-146-traced-profile-spec | [WO-146-traced-profile-spec.md](WO-146-traced-profile-spec.md) |
| WO-147-traced-profile-elaboration | [WO-147-traced-profile-elaboration.md](WO-147-traced-profile-elaboration.md) |
| WO-148-traced-profile-realizer | [WO-148-traced-profile-realizer.md](WO-148-traced-profile-realizer.md) |
| WO-149-native-walk-promotion | [WO-149-native-walk-promotion.md](WO-149-native-walk-promotion.md) |
| WO-150-unit-enforcement | [WO-150-unit-enforcement.md](WO-150-unit-enforcement.md) |
| WO-151-waveform-mask-record-class | [WO-151-waveform-mask-record-class.md](WO-151-waveform-mask-record-class.md) |
| WO-152-waveform-sheet-rendering | [WO-152-waveform-sheet-rendering.md](WO-152-waveform-sheet-rendering.md) |
| WO-153-procio-seam | [WO-153-procio-seam.md](WO-153-procio-seam.md) |
| WO-154-sim-gate-spec | [WO-154-sim-gate-spec.md](WO-154-sim-gate-spec.md) |
| WO-155-cuprite-sim-gate | [WO-155-cuprite-sim-gate.md](WO-155-cuprite-sim-gate.md) |
| WO-156-timing-closure-v1 | [WO-156-timing-closure-v1.md](WO-156-timing-closure-v1.md) |
| WO-157-sim-fleet-adoption | [WO-157-sim-fleet-adoption.md](WO-157-sim-fleet-adoption.md) |
| WO-158-riscv-sim-demo | [WO-158-riscv-sim-demo.md](WO-158-riscv-sim-demo.md) |
| WO-159-surface-facade | [WO-159-surface-facade.md](WO-159-surface-facade.md) |
| WO-160-artifact-provenance-tier | [WO-160-artifact-provenance-tier.md](WO-160-artifact-provenance-tier.md) |
| WO-161-registration-derived-classification | [WO-161-registration-derived-classification.md](WO-161-registration-derived-classification.md) |
| WO-162-promotion-ticket-rule | [WO-162-promotion-ticket-rule.md](WO-162-promotion-ticket-rule.md) |
| WO-163-realized-layout-put-seam | [WO-163-realized-layout-put-seam.md](WO-163-realized-layout-put-seam.md) |
| WO-164-realizer-capability-registry | [WO-164-realizer-capability-registry.md](WO-164-realizer-capability-registry.md) |
| WO-165-perfboard-program | [WO-165-perfboard-program.md](WO-165-perfboard-program.md) |
| WO-166-wire-edm-die-set-program | [WO-166-wire-edm-die-set-program.md](WO-166-wire-edm-die-set-program.md) |
| WO-167-dwelling-wiring-program | [WO-167-dwelling-wiring-program.md](WO-167-dwelling-wiring-program.md) |
| WO-168-process-record-schema | [WO-168-process-record-schema.md](WO-168-process-record-schema.md) |
| WO-169-process-population-wave1 | [WO-169-process-population-wave1.md](WO-169-process-population-wave1.md) |
| WO-170-process-population-wave2 | [WO-170-process-population-wave2.md](WO-170-process-population-wave2.md) |
| WO-171-process-population-wave3 | [WO-171-process-population-wave3.md](WO-171-process-population-wave3.md) |

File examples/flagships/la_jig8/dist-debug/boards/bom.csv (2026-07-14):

reference | part_number | description | vendor_ref | quantity
cb_3v3 | CAP-22UF-X5R-0805 | Bulk reservoir, 3V3 rail | cap_22uf_x5r_0805 | 1
cb_core | CAP-22UF-X5R-0805 | Bulk reservoir, 1V1 core rail | cap_22uf_x5r_0805 | 1
cb_vbus | CAP-22UF-X5R-0805 | Bulk reservoir, VBUS | cap_22uf_x5r_0805 | 1
cd_bypass | CAP-100NF-X7R-0402 | Local HF bypass, one per RP2040 power pin (iovdd/dvdd/usb_vdd/adc_avdd/qspi_vdd/vreg_vin) | cap_100nf_x7r_0402 | 6
d_dm | PESD5V0S1BA | ESD clamp, USB D- | tvs_pesd5v0s1ba | 1
d_dp | PESD5V0S1BA | ESD clamp, USB D+ | tvs_pesd5v0s1ba | 1
d_vbus | PESD5V0S1BA | TVS clamp, VBUS | tvs_pesd5v0s1ba | 1
j_swd | FTSH-105-01-L-DV-K | SWD debug header (the jig is itself debuggable) | swd_header_ftsh_105 | 1
j_tap | TAP-HDR-2X08-254 | Tap header, 2x8 2.54mm shrouded box header -- MATES the target board's debug-profile header (std.elec tap_header_2x08_254) | tap_header_2x08_254 | 1
j_usb | USB4085-GF-A | USB Type-C 2.0 receptacle, 16-pin -- bus power in, capture stream out | usb_c_2p0_receptacle_16p | 1
tp_rails | TP-1MM2 | Rail probe pads: VBUS, 3V3, core | tp_probe_pad_1mm2 | 3
u_mcu | RP2040 | Capture MCU: PIO parallel capture + native USB device | rp2040 | 1

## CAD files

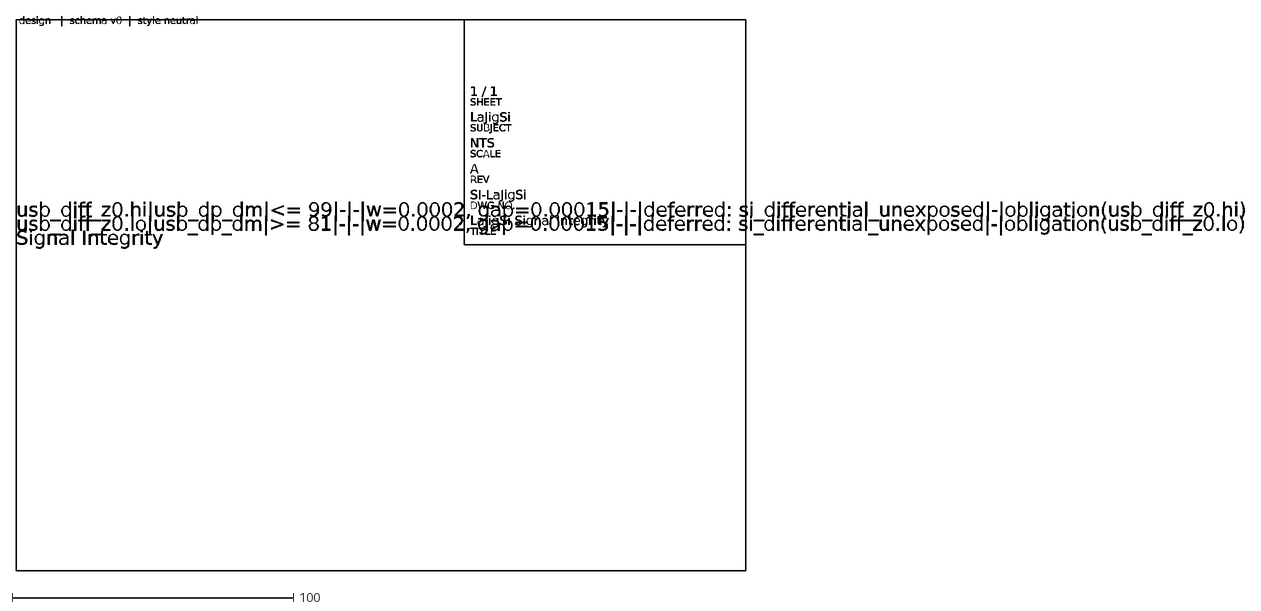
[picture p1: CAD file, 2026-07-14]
examples/flagships/la_jig8/dist-debug/drawings/drawings/LaJigSi.dxf
TITLE
LaJigSi Signal Integrity
DWG NO.
SI-LaJigSi
REV
A
SCALE
NTS
SUBJECT
LaJigSi
SHEET
1 / 1
design | schema v0 | style neutral
Signal Integrity
usb_diff_z0.lo|usb_dp_dm|>= 81|-|-|w=0.0002, gap=0.00015|-|-|deferred: si_differential_unexposed|-|obligation(usb_diff_z0.lo)
usb_diff_z0.hi|usb_dp_dm|<= 99|-|-|w=0.0002, gap=0.00015|-|-|deferred: si_differential_unexposed|-|obligation(usb_diff_z0.hi)

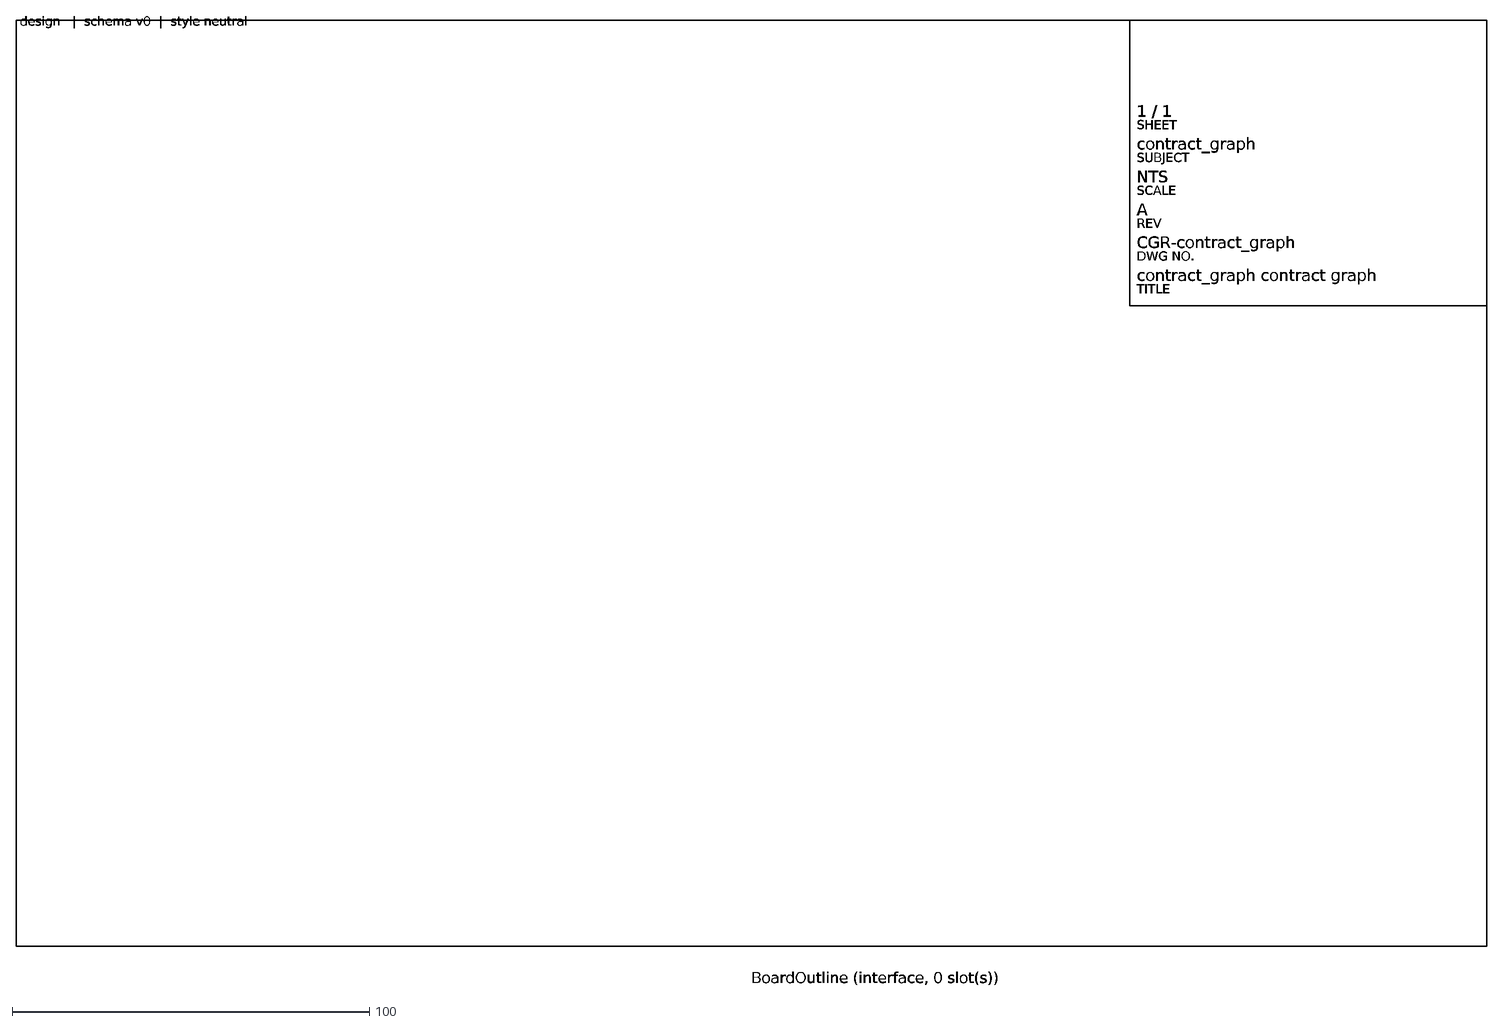
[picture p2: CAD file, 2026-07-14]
examples/flagships/la_jig8/dist-debug/drawings/drawings/contract_graph.dxf
TITLE
contract_graph contract graph
DWG NO.
CGR-contract_graph
REV
A
SCALE
NTS
SUBJECT
contract_graph
SHEET
1 / 1
design | schema v0 | style neutral
BoardOutline (interface, 0 slot(s))

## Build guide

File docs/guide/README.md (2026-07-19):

# The lithos guide

Learning-path documentation for the four design languages and their
toolchain. Read in order:

| doc | what you learn |
|---|---|
| [00-getting-started.md](00-getting-started.md) | install, write a first part, run `regolith check`, read a diagnostic |
| [01-hematite-guide.md](01-hematite-guide.md) | the mechanical language, by example, with the full vocabulary |
| [02-cuprite-guide.md](02-cuprite-guide.md) | the electrical/computer language, same treatment |
| [03-fluorite-guide.md](03-fluorite-guide.md) | the fluid-circuit language, same treatment |
| [04-calcite-guide.md](04-calcite-guide.md) | the civil/architectural language, same treatment |
| [10-writing-dfm-rules.md](10-writing-dfm-rules.md) | authoring DFM/DRC/ERC rule packs (for manufacturing experts too) |
| [11-optimization.md](11-optimization.md) | `regolith optimize`: the discrete/continuous search engine, trace, resume, pinning |
| [12-graphite.md](12-graphite.md) | `regolith config` doctrine + graphite (now a sibling repo, D233/D234): install pointer, what ships today, honest in-flight pointers |
| [13-parity-report.md](13-parity-report.md) | `regolith ship --explain`: the D170 parity ledger (provenance classes, decision/demand tables, the honest attention-list caveat) |
| [14-cam-verification.md](14-cam-verification.md) | verifying a supplied G-code plan (`std.cam`): parse, envelope, collision, removal, coverage |
| [15-board-correctness.md](15-board-correctness.md) | the encoded board-review checklist (`std.board_correctness` `erc:` packs, WO-79) |
| [16-hdl-verification.md](16-hdl-verification.md) | verifying digital logic (`std.hdl`): verilator build/sim_assert/equiv_directed over the cuprite/09 fixture corpus |
| [17-design-testing.md](17-design-testing.md) | `regolith test`: `test` declarations, `.test.<ext>` discovery, the runner and its cache |
| [18-external-tools.md](18-external-tools.md) | the optional external tools (verilator, ghdl, ngspice, kicad-cli, ccx, gmsh, feldspar): what each unlocks, install + troubleshooting, `regolith doctor` |
| [19-signal-integrity.md](19-signal-integrity.md) | calculated impedance windows over fab stackup records, sized termination claims, the stackup `by select`, and the SI table sheet (WO-78, charter 35) |
| [20-emission-and-packaging.md](20-emission-and-packaging.md) | the `dist/<project>/` release package layout, `[artifacts] formats` selection, and extending emission with a producer/renderer plugin (WO-99, charter 38) |
| [21-reading-build-output.md](21-reading-build-output.md) | the two-stream split (stdout is data, stderr is the log stream), the readable/colorized default log view, and `-v`/`-q`/`--color`/`NO_COLOR` (WO-107, D217) |
| [22-proving-optimizations.md](22-proving-optimizations.md) | the `demos/` proof packs: `make demos`, physical artifacts (drawings/STEP/GLB/BOM) per optimizer surface AND per user-facing feature family (WO-108/WO-115, D218/D222), the content-hashed manifest + PROOF.md, and the completeness/determinism gate |
| [23-health-gate.md](23-health-gate.md) | `make health` (D219): the check/consistency/demos/fleet legs, the standardized `LegSummary` row shape, and what each leg actually gates versus reports |
| [24-calc-package.md](24-calc-package.md) | the `calc/` calc book + audit index: per-discharged-obligation calc sheets (inputs with provenance pins, model/citation, margin, evidence hash chain) and the total obligation accounting that maps every obligation to one disposition (WO-114, D221) |
| [25-manufacturability-and-models.md](25-manufacturability-and-models.md) | the `manufacturable(<process>)` realized-geometry channel ([[machine]]/[[tool]] grounded envelope checks, the named deferral vocabulary, what a VIOLATED verdict means), the NPSH/torsion closed forms, the critical-speed pack adapter, and the bare unit-cost adapter (WO-110, D232) |
| [26-reading-the-rigor-census.md](26-reading-the-rigor-census.md) | the D220 rigor doctrine: discharged vs accepted-deviation vs deferred, what the fleet census golden reports today, and what the health fleet leg actually gates on it |
| [27-authoring-for-discharge.md](27-authoring-for-discharge.md) | D224 corpus authoring: provenance rules (record / derivation / citation), the same-change waiver burn-down, and fixing the DESIGN on a real VIOLATED verdict -- worked from the real arm_a6 bearing and uav_talon spar stories |
| [28-growing-the-stdlib.md](28-growing-the-stdlib.md) | charter 39: the `std.` namespace taxonomy, the lithos-vs-feldspar boundary rule, citation/tier bar, generated batches, and where a new record/model/pack goes |
| [29-the-progress-channel.md](29-the-progress-channel.md) | the D228 progress-event wire shape (`python/regolith/progress.py`): in-process subscription vs subprocess stderr parsing, and the graphite/editor consumers |
| [30-hardware-bring-up.md](30-hardware-bring-up.md) | `--emit-profile debug` (WO-125) + the `harness/` bring-up pack (WO-126, charter 40): the tap model, `tap_map.json`/INV-32, `expected_signals.json`'s D224 provenance rule, `bringup.md`, and the sigrok-cli capture configs |
| [31-diagnostics-and-explain.md](31-diagnostics-and-explain.md) | the ONE code space (D247/WO-131): the families incl. E09xx/E10xx/E11xx, the code-stability rule, `regolith explain <code> [--json]`, the machine-checked completeness legs, and how a producer adds a new coded failure |
| [32-the-artifact-surface.md](32-the-artifact-surface.md) | WO-130 (D244/AD-41): the universal `artifact_index.json`, the closed viewer vocabulary + its one-home registry, the health consistency check, `regolith artifacts`, and the three edit models (boards/drawing sheets/assemblies) |

Numbering convention: 00 is getting started, 01-09 are per-track
guides in track order (hematite, cuprite, fluorite, calcite), 10+
are authoring/tooling guides.

Two ground rules for reading:

1. **These guides teach; the spec decides.** Every list here is a
   learning view of a normative document, and each section names its
   source (`docs/spec/hematite/`, `docs/spec/cuprite/`, `docs/spec/regolith/`). If a
   guide and the spec ever disagree, the spec wins and the guide has
   a bug -- please fix the guide.
2. **Status honesty.** The toolchain is under construction. What each
   guide shows is marked:
   - WORKING -- runs today (`regolith check`, `fmt`, `debug`,
     `build`, `ship`, `optimize`, `test`, the rule-pack engine, the
     geometry realizer, the closed-form harness).
   - DESIGNED -- specced and work-ordered, not yet runnable; each
     guide names the WO that will flip its section.

The corpus in `examples/` is the best companion to these guides:
dozens of single-file designs per track under `examples/tracks/`,
multi-file systems under `examples/systems/`, and the charter-31
flagship programs under `examples/flagships/` (led by the ten-file
Kestrel cubesat, `examples/flagships/cubesat/`) -- all in real
syntax, all compiled by CI, all built and shipped by the health
fleet leg.

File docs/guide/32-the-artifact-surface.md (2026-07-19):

# The universal artifact surface: one index, no hardcoded families

STATUS: WORKING (WO-130; provenance tier WO-160/AD-45; registration-
derived classification WO-161/AD-46). Every `regolith ship` package
carries an `artifact_index.json` at its root describing EVERY file it
emitted -- family, kind, path, content hash, size, media type, a
viewer hint, a required provenance tier, and the subject/claim/
obligation ids that produced it (when known).
`regolith artifacts <package_dir> [--json]` publishes it straight from
the shipped package -- no rebuild.

The index is READ-ONLY DESCRIPTION: it says what a file IS, so a viewer
can render any family without a hardcoded list. The write-back half
(edit models, the `override` ledger and CLI) was PARKED by D253 and is
preserved on the branch `experimental/injection-channel`.

Source: design-log F145/D244 (charter `docs/spec/toolchain/
42-injection-and-artifact-surface.md` secs. 6-7, AD-41). Machinery:
`python/regolith/backends/registry.py` (the viewer-hint registry, one
home beside the AD-36 producer/renderer registrations),
`python/regolith/backends/artifact_index.py` (the index itself),
wired into `python/regolith/backends/ship.py` and the `regolith
artifacts` CLI verb (`python/regolith/cli/app.py`).

## Why this exists

Before this WO, a consumer that wanted to RENDER a shipped package
(graphite's preview pane, an editor, a one-off script) had to know, by
name, which families existed and how to read each one. That list
lived nowhere central and fell behind: F145 recorded graphite
rendering 5 of the fleet's 8 artifact families and previewing only the
`Edge.Cuts` layer of a 14-layer board fab set, because its renderer
carried its own hardcoded family switch that two cycles of new
families (`harness`, the full fab set) never reached.

The fix is structural, not a patch to graphite's switch statement: the
toolchain now publishes ONE typed index describing every file well
enough that a consumer never needs to know what family it is. A new
family is viewable the day it ships, because the index -- not a
viewer's own code -- is what says how to show it.

## The index shape

One row per emitted file (`regolith.backends.artifact_index.ArtifactRow`):

```json
{
  "family": "boards",
  "kind": "gerber_layer.F_Cu",
  "relpath": "boards/gerbers/board-F_Cu.gtl",
  "content_hash": "<sha256 hex>",
  "bytes": 223,
  "media_type": "application/vnd.gerber",
  "viewer": "gerber",
  "provenance": {"tier": "deterministic", "tool": null},
  "source_refs": []
}
```

`provenance` (WO-160, AD-45) is REQUIRED -- no default, never
post-hoc-inferred from relpath naming or toolenv state. `tier` is
`real_tool` (produced by an actual third-party tool invocation --
`tool` required, `{name, version_digest}`) or `deterministic`
(regolith's own deterministic logic, no external tool -- `tool` is
`null`). A producer supplies it at construction time
(`OutputFile.of(relpath, content, provenance=...)`); an untagged
`OutputFile` resolves to the honest `deterministic` default when
`build_index` builds the row, never an invented `real_tool` claim. The
fake/real KiCad fork (`regolith.backends.elec.ElecBackend`) is the
worked example: the real `kicad-cli` leg tags every export with
`tier=real_tool, tool={name: "kicad-cli", version_digest: <observed
version string>}`; the fake-KiCad tier (`elec_fabset.
build_fake_fab_set`) tags its files `tier=deterministic, tool=null`
explicitly.

`family` is the package's top-level directory the file lives under
(`boards`, `drawings`, `3d`, `bom`, `cost`, `firmware`, `hdl`,
`instructions`, `harness`, `evidence`, `calc`, `mech`), or `"ledgers"`
for the root-level side files (`manifest.json`, `index.md`,
`gate_summary.json`, `parity_ledger.json`, `acceptance_ledger.json`,
and `artifact_index.json` itself -- which never lists its own row, the
same rule `index.md` already followed). `kind` narrows within a
family (e.g. `gerber_layer.F_Cu` vs. `drill.PTH` vs. `job_file` all
live under `boards`). `viewer` is the CLOSED vocabulary:

```
svg | raster | gerber | glb | table | markdown | json | text | binary
```

A viewer that understands none of a family's own richer forms still
has the honest fallback ladder `table`/`json`/`text`/`binary` -- a
consumer always has something truthful to render (a hash + size + a
reason beats a blank pane).

## Where the viewer hint lives

ONE home, beside the family's own registration: `regolith.backends.
registry.default_artifact_family_registry()` -- the same module the
AD-36 producer/renderer registries already live in. Every family
`regolith.backends.package.FAMILY_DIRS` names carries a default
viewer here; each family's own `path_patterns` (WO-161, matched via
`registry.match_path_pattern`) narrow individual files whose kind does
not match the family default (a
board's `board_status.json` is `json`, not `gerber`; its gerber
layers keep the family default). **A family with no registered
default is a REGISTRATION ERROR** -- `build_index` refuses to build a
lossy index rather than silently omitting rows, and the ship refuses
with it. This is the loud-vs-silent discipline the producer/renderer
registries already enforce for duplicates, extended to viewer hints.

Registering a new family's hint is one call:

```python
registry.register(ArtifactFamilyRegistration("my_family", "table"))
```

## The health consistency check

`regolith.backends.artifact_index.check_index_consistency(index,
files)` enforces five things, ALL as failures (never warnings):

1. every emitted file appears in the index;
2. every index row resolves to an emitted file;
3. every row's family carries a registered viewer hint;
4. every row's family carries a `path_patterns` entry that actually
   matches its relpath (WO-161) -- with `classify()` deleted, this is
   the one remaining place a new artifact type could sneak in without
   registering patterns at all;
5. every row's `provenance` is internally consistent -- `tool` present
   iff `tier == "real_tool"` (WO-160).

`ship` runs this immediately after building the index and BEFORE
writing `artifact_index.json`; drift refuses the whole ship. Tests in
`tests/backends/test_artifact_index.py` demonstrate each case: an
index row built against a family that was never registered (case 3),
a family registered but with no matching `path_patterns` entry (case
4), and a `real_tool` row with `tool=None` (case 5) -- the check fails
naming the offending relpath/family in every case.

## Publishing the index without a rebuild

```
regolith artifacts <ship_output_dir>
regolith artifacts <ship_output_dir> --json
```

Reads `artifact_index.json` straight from the package; `--json` emits
the raw bytes (what a script/graphite parses), the default renders an
ASCII table (family, kind, viewer, size, path).

## Escalations recorded at close-out

(The edit-model escalations F-WO130-1/-2/-4 went with the D253 park --
see below; they live on with the code on `experimental/injection-channel`.)

- **F-WO130-3**: `source_refs` (subject/claim/obligation ids) is
  populated empty by `ship` today -- threading per-file provenance
  through every backend's `OutputFile` is out of this WO's zero-shot
  scope (`OutputFile` carries no id today); the field exists and is
  honestly empty rather than fabricated, ready for a follow-up WO to
  populate.
- **F-WO130-5**: the CLI's `builtin_backends["mech"]` package (STEP
  models, its own `bom.csv`/`bom.json`, `fab_notes.json`) had never
  joined `package.FAMILY_DIRS` -- closed in this same change (added to
  `FAMILY_DIRS` and given a viewer hint), itself an instance of the
  exact hardcoded-list drift F145 describes, one layer down.

## What was parked (D253)

WO-130's edit-model deliverable -- the movable-slot models for boards,
drawing sheets, and assemblies, and the `edit_model` reference that
pointed each artifact row at one -- is PARKED, together with the whole
WO-129 injection channel (the `overrides.toml` ledger, target
resolution, and the `regolith override` verbs). All of it is preserved
on the branch `experimental/injection-channel`; D253 is the decision and
F150 is the finding that made it safe (the channel was inert -- no build
or ship path ever read the ledger).

The index half above STANDS and is what the artifact surface is: a
viewer reads `artifact_index.json` and renders any family. Moving an
engineering quantity is a source edit, not a GUI gesture.

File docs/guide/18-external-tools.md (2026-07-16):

# External tools

WORKING (`regolith doctor` + the `regolith.toolenv` registry; the
per-tool call-site wiring varies -- each tool's entry below says
what is wired up in this repo today).

The toolchain shells out to a handful of OPTIONAL external binaries
for the higher evidence tiers (real layout, real simulation, real
FEA), and loads one optional Python plugin pack (feldspar). None of
them are required to install regolith or to run `regolith check`.
Two rules govern every one of them:

1. If a design does NOT need a tool, its absence is a graceful,
   honest skip -- the affected claims render INDETERMINATE (deferred,
   with a named reason), never a broken build, never a crash.
2. If a design DOES need a tool (e.g. it makes an elec layout claim,
   which needs `kicad-cli`), a missing tool is a LOUD, constructive
   diagnostic: the tool's name, why THIS design needs it, and exact
   install guidance -- never a bare traceback, never a silent pass.

Every tool's identity, capability wording, and install-hint COMMAND
strings are single-sourced in ONE module,
`python/regolith/toolenv.py`. This guide quotes them for reading
convenience, but the registry is authoritative: `regolith doctor`
prints the live strings, and a drift test
(`tests/test_toolenv.py::test_guide_quotes_registry_capabilities`)
keeps this guide's capability wording in sync with the code.

## `regolith doctor` -- start here

```
regolith doctor
```

Prints one row per registered tool: found/MISSING, the resolved
path, the probed version, the capability the tool unlocks, and (for
anything missing) the install guidance -- the same strings this
guide quotes, from the same registry. `regolith doctor --json`
emits the identical data as JSON for CI environment probes.

`regolith doctor` is the FIRST thing to run on any "nothing
discharges" symptom (see the feldspar troubleshooting entry below).

## The tools

### kicad-cli (+ pcbnew)

- Unlocks: elec layout tier for cuprite designs
  (placement/routing/DRC/export). Without it, layout realization and
  the elec manufacturing backend (`regolith ship`'s gerber/drill/pos
  exports) return an honest `tool_unavailable` error value, and
  `elec.layout.drc_clean` claims cannot be discharged.
- Wired up today: yes -- `regolith.realizer.elec.kicad` and
  `regolith.backends.elec`.
- Real board outlines (WO-103, charter 38 sec. 1.10): the real KiCad
  wrapper (`regolith.realizer.elec.kicad_wrapper`) draws the DESIGN'S
  own rectangular board outline (`LayoutRequest.outline_w_mm`/
  `outline_d_mm` -- the same geometry the deterministic fake tier
  already renders; the old fixed 50mm placeholder square is retired).
  `kicad-cli pcb export gerbers|drill|pos` then re-exports that real,
  outline-shaped (but unrouted -- no footprint-library resolution
  machinery exists yet, routing is a separate scope) board; in a
  `regolith ship` release package these land in the `boards/` family
  beside the pinned `board.kicad_pcb` and an honest
  `board_status.json`, and the package index labels the family with
  that status (unrouted gerbers are fab-shape evidence, labeled as
  such). The fake tier (`regolith.realizer.elec.fake_kicad`) remains
  the deterministic, no-install CI leg, always stamped
  `generator regolith-fake-kicad`; it never claims to be the real
  leg's output.
- Install: `sudo apt install kicad` (the KiCad PPA for KiCad 10).
  The `pcbnew` python API additionally needs `make kicad-link` to
  link the system module into the venv; `kicad-cli` alone does not
  open the real-tool gate
  (`regolith.realizer.elec.kicad.real_kicad_available()`).

### verilator

- Unlocks: HDL sim-tier evidence for cuprite digital designs
  (`hdl.build`, `hdl.sim_assert`, `hdl.equiv_directed` for
  Verilog/SystemVerilog fixtures). Without it, every hdl.* claim
  renders indeterminate with the install hint cited in the deferral
  message.
- Wired up today: yes -- `regolith.harness.models.hdl` (the std.hdl
  pack, WO-82).
- Install: `sudo apt install verilator`.

### ghdl

- Unlocks: VHDL sim-tier evidence for cuprite digital designs.
  Registered so the VHDL deferral message can honestly report ghdl's
  live PATH status; note that TODAY no ghdl adapter is implemented
  (a WO-82 scope cut) -- VHDL hdl.* claims defer even with ghdl
  installed, and the deferral message says which case you are in.
- Install: `sudo apt install ghdl`.

### ngspice

- Unlocks: SPICE simulation tier for cuprite analog/power designs.
- Wired up today: no realizer in this repo invokes it yet;
  registered so `regolith doctor` reports the full optional surface
  and a future call site never re-derives install text.
- Install: `sudo apt install ngspice` (see troubleshooting for the
  KiCad-PPA conflict).

### ccx (CalculiX)

- Unlocks: FEA solve tier (CalculiX) for hematite/feldspar stress
  claims.
- Wired up today: invoked by the feldspar pack (its own repo), not
  by lithos directly; registered here so one `regolith doctor` run
  covers the whole environment.
- Install: `sudo apt install calculix-ccx`.

### gmsh

- Unlocks: FEA meshing tier for hematite/feldspar geometry-to-mesh.
- Wired up today: invoked by the feldspar pack, same note as ccx.
- Install: `sudo apt install gmsh` where apt can resolve it; on
  KiCad-PPA and/or arm64 hosts apt cannot -- see troubleshooting,
  conda-forge is the working route there.

### sigrok-cli

- Unlocks: logic-analyzer capture tier for the WO-126 bring-up
  harness pack (dist/<proj>/harness/ capture configs).
- Wired up today: the harness pack's capture configs are always
  emitted (config-only tier); `sigrok-cli` absence never blocks a
  ship -- it is only needed to actually RUN a capture by hand. See
  guide `30-hardware-bring-up.md`.
- Install: `sudo apt install sigrok-cli`.

### feldspar (plugin pack, not a binary)

- Unlocks: the external FEA/solver evidence tiers for hematite (and
  the mixed-domain flagships). It is a Python plugin distribution,
  not a PATH binary, so it is NOT in `regolith doctor`'s binary
  table; its absence-handling is the WO-27 skip-if-absent posture
  (`tests/packs/test_feldspar_conformance.py`): tests and harness
  runs that need it skip/defer honestly.
- Install (local dev): check the repo out beside this one and
  `uv pip install -e ../feldspar` into the ACTIVE venv.

## `regolith.procio` -- the ONE process-invocation seam (WO-153)

Every tool invocation above (kicad-cli, verilator, and the AD-19
subprocess-solver wire protocol) runs through `python/regolith/procio.py`
-- the one seam that generalizes `regolith.harness.adapter.
solve_via_subprocess`'s wire discipline (typed argv, a mandatory
explicit timeout, captured stdout/stderr, a typani `Result` failure
value, never a bare exception) to every OTHER call site instead of
restating it. Design precedent: `../lograder`'s process module proved
two ideas (typed-argv models, invocation-as-data with mandatory
timeouts) that `procio` adopts fresh, without depending on or vendoring
lograder (see the module docstring for the dependency-posture
reasoning, D264 ruling 1).

Adding a new tool verb: define a `procio.ToolArgs` subclass whose
`emit()` returns the flag/positional argv for that verb (see
`VerilatorLintArgs`/`KicadDrcArgs` for the shape), then call
`procio.run_tool(name, args, cwd=..., timeout_s=...)` -- it resolves
`name` through this module's own `toolenv` registry (a missing binary
short-circuits to the tool's teaching message, never an auto-install
attempt) and returns `Result[ToolOutput, ToolFailure]`.

The ONE recorded exception (D264 ruling 1): `tools/health/*` and
`tools/codegen/generate_codes.py` stay on raw `subprocess.run` --
dev tooling outside the shipped package; migrating them would couple
the health harness to the package under test for no benefit.

## Troubleshooting

### ngspice: dpkg "trying to overwrite .../ngspice/analog.cm"

On a host with the KiCad PPA enabled, `sudo apt install ngspice`
can fail with dpkg refusing to overwrite
`.../ngspice/analog.cm` (or another `.cm` file): the
`libngspice-kicad` package ships the same XSPICE code models as the
ngspice CLI package. Fix:

```
sudo apt install ngspice -o Dpkg::Options::="--force-overwrite"
```

Caveat: the CLI package's (v36) code models then shadow the KiCad
lib's (v43) copies on disk. If KiCad's built-in simulator later
misbehaves, undo the shadowing with
`sudo apt install --reinstall libngspice-kicad`.

### gmsh: unmet OCCT dependencies (libocct-*-7.6 Breaks 7.5)

Ubuntu jammy's `gmsh` package needs OCCT 7.5, but a KiCad-10-PPA
host pins `libocct-*-7.6`, which declares `Breaks` on 7.5 -- apt
`gmsh` is unwinnable on such a host; do not fight the resolver.
Additionally, on arm64 there is NO pip wheel and NO upstream binary
tarball for gmsh. The working route:

```
micromamba create -n gmsh -c conda-forge gmsh
ln -s ~/micromamba/envs/gmsh/bin/gmsh /usr/local/bin/gmsh   # or ~/.local/bin
```

(the symlink gives global PATH visibility, which is what the
registry's `which()` resolution and every subprocess call site
need). On x86_64 the upstream Linux64 tarball from gmsh.info is an
alternative to conda-forge.

### calculix-ccx: apt refuses to install it

`calculix-ccx` has NO OCCT dependency. If apt refuses it, it was
almost certainly batched in one transaction with `gmsh` (whose OCCT
conflict poisons the whole transaction) -- install it alone:

```
sudo apt install calculix-ccx
```

### feldspar: every harness discharge defers (discharged=0)

Symptom: a build that used to discharge claims suddenly reports
zero discharged, all deferred, with NO error anywhere. Cause: a
rebuilt venv (e.g. `uv sync` after a lockfile change, or a fresh
clone) drops the editable feldspar install, and the plugin seam
skips the absent pack honestly -- which is exactly the graceful-skip
posture doing its job, but it looks like a silent regression if you
do not know to check. Fix:

```
uv pip install -e ../feldspar
```

Run `regolith doctor` FIRST on any "nothing discharges" symptom: it
shows the binary-tool half of the environment at a glance, and a
fully-green doctor table with zero discharges points you straight at
the plugin half (feldspar).

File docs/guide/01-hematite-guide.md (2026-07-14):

# The hematite guide (mechanical design)

hematite describes manufactured mechanical artifacts: what they are
made of, how they are made, what they promise, and what must be true
of them. This guide walks the language bottom-up, then gives the
complete vocabulary. Normative sources: `docs/spec/hematite/02-language.md`
(the language), `docs/spec/hematite/04-vocabulary.md` (every keyword),
`docs/spec/regolith/` (everything shared with cuprite).

## 1. The core idea

A hematite part is not a solid model you sculpt -- it is a
**manufacturing pipeline with contracts**. You declare stages
(laser-cut, press-brake, mill), features within stages, interfaces
the part implements, and claims that must hold. Geometry is an
OUTPUT (realized at build time), not the input.

Three sentence summary of the whole language: **blocks declare,
sources resolve, claims prove.** Every construct is exactly one of:
a declaration (structure), a value source (who decides a number), a
claim (what must be true), or a selector (which entities).

## 2. Profiles (2D sketches, done differently)

A `profile` is a 2D constraint system serialized as a **walk** --
the topology written as a path, with the metric constraints separate:

```
profile BracketFlat:
    walk:
        from left_edge
        line right                 # a
        line up                    # b
        line left                  # c
        close                      # d
    hole wire_pass:
        circle(dia 8mm)
    constraints:
        a.length = 80mm
        b.length = 50mm
        wire_pass.center to a = 32mm
    regions:
        flange_band: between(c, c.offset(12mm))
        web:         interior - flange_band - holes
    exports:
        mid_plane: datum
```

- The walk pins every discrete branch (direction words like `right`,
  `bulge=left` on arcs, `tangent` joins) so the sketch has ONE
  topology; constraints then pin the metrics. Under- and
  over-constraint are compile diagnostics (the DOF ledger).
- `regions:` names areas features can consume; `exports:` publishes
  datums. No freehand splines -- curves come from `from_table()` /
  `from_fn()`.

### 2a. Closure, sheet gauge, and what actually realizes (WO-62 D171/AD-32)

A labeled `close` step (`d: close`) is an unconstrained 2-DOF return
vector -- it closes the loop by definition, so it absorbs the entire
closure gap and leaves nothing for another `free` segment length to
solve against. Two shapes follow from that:

- Every OTHER explicit segment pinned (as `BracketFlat` above, once
  `c.length` is asserted): closes trivially, no diagnostic.
- Any explicit segment still `free` alongside a `close` edge:
  under-constrained by construction -- `E0447`, naming the residual
  segment and the missing constraint class. Assert its length, or the
  closure gap has no source.

The over-constrained sibling (every length pinned but the numbers
don't agree) is `E0441`, unchanged.

Sheet-metal blank thickness has its own value SOURCE: a stage's
`process=laser_cut(sheet=<t>)` (or a sibling sheet process spelled the
same shape) supplies it, recorded as `cause: process(<proc>.sheet)`
(INV-21) in the lockfile. An explicit `thickness=` arg on the `Blank`
op itself wins when spelled. A sheet part with neither is `E0448` --
never a silently unthickened blank.

Only some `then:` constructors realize to actual OCCT geometry today;
the realizer PUBLISHES which ones as a committed, drift-checked
**feature-coverage ledger**
(`python/regolith/realizer/mech/coverage.py`): every constructor either
`realizes` or is a named `skips(E0443)` row, and every skip the current
corpus exercises is listed there (checked live against the compiler by
`tests/realizer/mech/test_coverage.py`, the schema-check pattern
applied to capability -- an unledgered addition reddens that test). An
op outside the ledger's `realizes` set is always the named `E0443`
skip, never a silent truncation of the emitted `FeatureProgram`.

### 2a. Assembly realization (WO-62 slice B; charter `30-geometry-
lowering.md` sec. 1.4)

An `assembly`'s `connect:` mate graph realizes to a placed, content-
addressed `RealizedAssembly` (kind `assembly.realized`, AD-25's L4 IR
set): `regolith.realizer.mech.assembly.solve_assembly` places every
part deterministically over a spanning order of the mate graph (the
first declared part sits at identity; every other part is placed by
composing mate transforms along the first tree edge that reaches it).
A mate not on the spanning tree closes a loop; if its declared
transform disagrees with the tree placement it closes back to (beyond
the interface tolerance), the solve returns a diagnostic naming every
mate on the loop rather than silently absorbing the mismatch. The
solved assembly exports to one STEP file (every part's own realized
solid, placed), and extracts an assembly-level mass/COM plus every
pairwise interference fact (both part names, an overlap measure) --
these compose with the cycle-30 optimizer as ordinary evidence with no
engine change (`docs/spec/toolchain/28-optimization.md`).

Today's integration seam (recorded honestly, the same posture WO-42's
`geometry_realizable` model documents): no `regolith-lower` pass yet
turns a `connect:` block's `align:`/`dof:` mating clauses into a
numeric mate-transform graph, so `solve_assembly` is exercised over a
hand-declared `AssemblyDef` (see `tests/realizer/mech/test_assembly.py`
and the exemplar `examples/tracks/hematite/gantry_carriage.hema`) until
that lowering lands.

## 3. Parts and stages

```
part SensorBracket:
    material: AISI_304

    stage cut: process=laser_cut(sheet=1.5mm)
        then:
            blank  = Blank(BracketFlat)
            mounts = PatternOf<Pierce<circle(dia 4.5mm)>>(n=4,
                         grid(2, 2, 56mm x 30mm),
                         frame=blank.mid_plane.offset(y=8mm))

    stage formed: process=press_brake, from=cut
        flange = Bend(edge=cut.blank.top_edge, angle=90deg, radius=free)
```

- `stage <name>: process=<pack>(...)` binds one process step;
  `from=` chains stages. The process pack brings capability limits
  and DFM rules with it.
- Inside a stage, `then:` opens a concurrent scope (features read a
  snapshot, commit together); `seq:` is the sequential sugar. Bare
  statements are their own scope.
- Machining stages contain `setup` blocks (`hold:` the fixtured
  geometry, `flip about <axis>` to re-fixture); omitted setups are
  planner-allocated.
- Multi-piece parts (weldments) use `pieces:` with per-piece
  materials and joining stages with `joins=[...]`.
- Discrete externally-chosen configurations use
  `variant <name>: {a, b}` with `when <variant> = <v>` guards; every
  variant is verified.

### 3a. Declared material removal (the honest erosion; WO-77)

Lightening a part is DECLARED, never synthesized: you name a removal
family over the stage's working solid and (optionally) leave its
parameters to the optimizer with the ordinary bounded/discrete slot
forms. Four families exist (charter `34-topology.md` sec. 2, D200):

```
stage milled: process=cnc_mill(std.removal)
    then:
        body       = Blank(PanelOutline, depth=18mm)
    then:
        lightening = Ribs(count in [4, 8], pitch=20mm,
                          thickness in [2mm, 5mm], height=12mm)
        tray       = PocketGrid(nx=3, ny=2, wall=4mm, floor=3mm)
        hollow     = Shell(t=2mm)
        core       = Lattice(cell=gyroid, density=0.35)
```

- Signatures: `Ribs(count: int, pitch: length, thickness: length,
  height?: length)` (height defaults to the region's depth),
  `PocketGrid(nx: int, ny: int, wall: length, floor: length,
  depth?: length)`, `Shell(t: length)`, `Lattice(cell: {gyroid,
  honeycomb, cubic}, density: [0, 1])`. A malformed spelling is the
  constructive `E0451`, naming the signature.
- Bounded slots (`count in [4, 8]`) are ordinary planner slots: the
  optimizer explores them against your mass/stiffness claims and pins
  the winner with `cause: optimize(...)` -- DFM rules re-check every
  pinned candidate (a lattice a process cannot make is infeasible,
  not clever).
- `Ribs`/`PocketGrid`/`Shell` realize to real geometry; `Lattice`
  lowers like any op but has no v1 realizer projection -- its program
  stays honestly pending with the skip named (the coverage ledger's
  "lattice: no v1 projection" row).

**Ownership is real.** A feature that consumed a face owns it; a
later feature touching it is a borrow conflict (a compile error, not
a surprise at regen). Cross-stage references are qualified
(`cut.blank.top_edge`); `rebind()` re-evaluates after an intervening
modifier; datums (`.as_datum()`) are borrow-exempt reference geometry.

**Queries, never indices.** Entities are addressed semantically:

```
faces.where(normal=+z).only
holes.where(dia < 5mm).all
edges.nearest(mid_plane)
at_intersection(boss, web)      # explicit cross-ownership join
```

`.only` asserts exactly one match (over/under-match is E0301);
`.all` takes the set; `.any` says any member is acceptable
(orbit-checked). Numeric indices do not exist.

## 4. Interfaces, impls, matings

An `interface` is a contract: a reference frame, named geometric
roles, tolerance demands, and promise slots:

```
interface SensorPad:
    frame:
        origin: pad.center
        z: pad.normal
    roles:
        pad: planar, rect(>= 20mm x 20mm)
    tolerances:
        pad: flatness(0.2mm)
    loads:
        static: <= 12N
        structure: static
```

A part binds geometry to the roles with `impl`:

```
impl SensorPad for self:
    pad = formed.flange.face
```

The binding is a permanent borrow; `= todo!` defers the conformance
PROOF (release-gated) while keeping the contract concrete. `refines`
narrows an interface one-way -- the only inheritance-like mechanism.

A `mating` is a connection contract between named sides: `align:`
(frame coincidence -- the only positioning mechanism), `fit:` (ISO
286 designations, capability-checked), `dof:` (`removed=`/`kept=`
freedoms feeding the assembly ledger), `preload:`, `effects:`
(declared physics via `model<sig>(...)`), `capability:`, and its own
`require` groups.

## 5. Assemblies

```
assembly SensorMount:
    parts:
        bracket: SensorBracket
        rails:   4 x Rail
    boundary:
        ambient: [-20degC, 60degC]
        event drop: shock(50g, 11ms, half_sine)
    connect:
        mount: PadMate(a=bracket, b=sensor) exposing align.theta
    budget alignment: kind=tolerance
        members: [bracket, rails.all]
        allocate: worst_case
    require Survival:
        shock: peak(mech.stress, during drop) < material.sigma_y, sf=1.5
```

- `boundary:` is the ONLY place a human asserts physical truth
  (loads, temperatures, life, spectra). Parts have no boundary;
  standalone parts take loads from `interface_envelope(<I>)`.
- `budget` blocks allocate a shared quantity across `members:` with
  a policy; `locked:` fixes individual entries by hand.
- `n x thing` forms orbits; `pairwise(a_set, b_set) by <Mating>`
  zips equal-cardinality sets into per-pair connections.
- `redundant(<dof>)` declares static indeterminacy explicitly.

## 6. Claims

Claims live in named `require` groups on parts, matings, and
assemblies. The full shared claim system (windows, events, masks,
`forall`, safety factors) is regolith vocabulary -- see the tables
below and `docs/spec/regolith/07-claims-and-evidence.md`. Mech-specific
claim forms worth knowing by name: `mech.life`/`mech.damage`
(fatigue, `scatter_factor=`), `mech.weld_stress`,
`equilibrium(...): stable`, `manufacturable(stage)`, and the `mfg.*`
namespace (`unit_cost`, `cycle_time`, `lead_time`).

Honest-deferral ladder (shared): `assume!(expr, basis=...)` accepts a
claim without evidence; `todo!` defers an impl's proof;
`waive <target> [on <scope>]: basis: ...` accepts a specific failed
result. All three are ledgered and release-gated; none can turn
violated into discharged.

## 7. The complete vocabulary (learning view)

Normative source: `docs/spec/hematite/04-vocabulary.md` -- the spec wins
on any disagreement. `[S]` = regolith-shared with cuprite.

### Registries (shared foundations)

| keyword | purpose |
|---|---|
| `namespace` [S] / `quantity` [S] | typed physical quantities (`mech.stress: Pa`) |
| `zones(...)` [S] | zone-indexed field values |
| `class` [S] / `properties:` [S] | material class hierarchy + property schema |
| `material` | concrete material: `f(T)` intervals, `condition(...)`, fatigue data |
| `contact { A, B }` [S] | unordered-pair properties (friction, conductance) |
| `process` [S] / `capability:` [S] | manufacturing module: capability table + DFM rules |
| `signature` [S] / `impl <sig> by` [S] | physics model contracts and implementations |

### Sketch layer

| keyword | purpose |
|---|---|
| `profile` / `walk:` / `from <datum>` | 2D constraint system; topology as a walk |
| `line`, `arc`, `tangent`, `perpendicular`, `bulge=left/right` | walk entities, joins, branch pins |
| `close [via axis]` | loop closure; revolve centerline |
| `hole <name>:` / `regions:` / `constraints:` / `exports:` | inner loops, named areas, metrics, published datums |
| `from_table()`, `from_fn()` | data-/math-defined curves |

### Part layer

| keyword | purpose |
|---|---|
| `import <pkg-or-path> (<names>)` [S] | bring declarations into scope (cross-language too) |
| `part` / `material:` | a manufactured component |
| `pieces:` / `joins=[...]` | weldments: per-piece stock and joining |
| `variant <name>: {a, b}` / `when <v> = <x>` | discrete config axes; guarded construction |
| `stage` [S] / `from=` / `sealed` [S] | process steps; import sealing |
| `setup` / `hold:` / `flip about` | workholding states |
| `then [label] [on <region>]:` [S] / `seq:` [S] | concurrent scope / sequential sugar |
| `datum` [S] / `.as_datum()` | borrow-exempt reference geometry |
| `impl <Interface> for <Part>` [S] / `todo!` | role binding; deferred proof |
| `merge(a before b / a over b)` [S] / `rebind()` [S] | overlap ordering; re-borrow |
| `sequence: a before b` [S] / `plan:` | pinned manufacturing order; supplied plan |

### Contract layer

| keyword | purpose |
|---|---|
| `interface` [S] / `frame:` / `roles:` / `tolerances:` | contract, its frame, slots, GD&T demands |
| `loads:` / `stiffness:` / `thermal:` + `structure:` [S] | promise slots + time structure |
| `refines` [S] | one-way contract narrowing |
| `mating` / `align:` [S] / `fit:` / `dof:` (`removed=`/`kept=`) | connection contract |
| `couples:` [S] / `preload:` [S] / `effects:` [S] / `capability:` [S] | kinematics, internal state, physics, envelope |

### Assembly layer

| keyword | purpose |
|---|---|
| `assembly` / `parts:` [S] / `vendor()` [S] | the system and its part bindings |
| `boundary:` [S] | THE human-asserted physical truth |
| `connect:` [S] / `exposing` [S] / `redundant(<dof>)` / `lubrication:` | connection instances |
| `budget` [S] / `members:` / `allocate:` / `locked:` | cross-part allocation |
| `zones over <set>:` / `remainder` | named partitions of entity sets |
| `target <name> of <system>` [S] / `reserves:` / `draws:` [S] | additive overlays and set-asides |

### Claims and evidence (all [S])

| form | purpose |
|---|---|
| `require <Group>:` | named claim group |
| `forall <cfg> [in <domain>]:` | quantify over a config domain |
| `sf=` / `scatter_factor=` | safety multiplier; fatigue scatter divisor |
| `@hint(...)` | droppable guidance (never load-bearing) |
| `all` | the full subject domain (`mech.mass(all)`) |
| `during` / `within .. after` / `until` | time windows over events |
| `peak`, `settles`, `overshoot`, `rms(band=)`, `stays_within(mask)` | transient/frequency claim forms |
| `event` / `mask` | named time datums; piecewise envelopes |
| `equilibrium(...): stable` | stability claim |
| `manufacturable(stage)` / `mfg.*` | planning claims |
| `trust: >= <tier>` | evidence-tier floor |
| `assume!(expr, basis=)` / `todo!` / `waive ... basis:` | the honest-deferral ladder |
| `by analysis / catalog(ref) / test(ref)` | evidence provenance |
| `model=<impl>` | pin the discharge model (cannot forge a pass) |

### Value sources (all [S]; every numeric slot)

| form | meaning |
|---|---|
| literal (`5mm`, `>= 80kN/mm`, `3.3V +- 5%`) | asserted truth (comparators are one-sided literals) |
| `within [lo, hi]` | demanded two-sided window (infix in claims) |
| `in [lo, hi] [minimize/maximize]` | bounded freedom; optimizer decides |
| `free` | process-rule (DFM/DRC) minimum decides |
| `derived [(sf=k)]` | consequence of system analysis; lockfile-pinned |
| `allocated [(policy)]` | share of a budget / planner output |

### Queries and selectors

| form | purpose |
|---|---|
| `.where(pred, ...)` | filter |
| `.all` / `.only` / `.any` | cardinality intents |
| `.nearest(datum)` | semantic addressing (never positional) |
| `at_intersection(a, b)`, `&` | explicit cross-ownership joins |
| `.cavity(inlet=...)` | derived void entity |
| `pairwise(a, b) [by <Mating>]` [S] / `n x thing` [S] | orbit zip; count constructor |
| `[a, b]` vs `[i .. j]` [S] | closed interval vs half-open positional range |

### Coherence, override, policy (all [S])

| form | purpose |
|---|---|
| `override <record> by <evidence>` | shadow a registry record (evidence mandatory) |
| `use { A, B }` / `use <impl>` | pin an ambiguous resolution |
| `policy:` with `prefer x [over y]` / `forbid x` / `minimize <global>` | allocation preferences and global objectives |
| `extern(<ref>, <format>)` | foreign content, checked against contract, never merged |

### Retired words (do not write these)

`pairs`, `var()`, `rated()`, `promised()`, `with`, `scope:`,
`verify-only`, `generates:`, `state_requirements:`, `environment:`,
`fix:`, `margin=` (as multiplier), `requires` (in classes),
`domain_decl`, bracket query sugar, `==` on continuous quantities,
positional mating sides, `.original`/`.current`, freehand splines,
numeric entity indices, `pins:`, `locked()`, `dof: free=`,
`preload_at:`, `minimize(<arg>)`/`maximize(<arg>)`, `@ <value>`
point-conditions, `artifact("path", Name)`. (Full list with reasons:
hematite/04 sec. 4.)

## 8. Reading diagnostics

Families you will meet (normative: regolith/09): E01xx quantity/type
(the `==` ban is E0102), E03xx queries (`.only` mismatch E0301,
borrow conflicts E0302), E04xx contracts/ledgers (boundary
subsumption E0407, over-allocation E0432), E05xx
generics/orbits, E06xx DFM/DRC rule violations, E07xx waivers
(stale E0701, basis-less E0702), plus the emission/packaging,
injection/override and bring-up families E09xx/E10xx/E11xx
(D247). Every code is stable, and `regolith explain <code>` looks
one up:

```
$ regolith explain E0102
E0102 (EQUALITY_ON_CONTINUOUS, family=Parse)

MEANS:
  `==` (structural equality) was used to compare a CONTINUOUS quantity ...

WHY IT FIRES:
  ...

HOW TO FIX:
  Compare within a tolerance instead: use a `within [lo, hi]` claim ...

EXAMPLE:
  `length == 10mm` (rejected, E0102) becomes `length within [9.9mm, 10.1mm]`.
```

`--json` emits the same content machine-readably. Full detail --
the families, the code-stability rule, and how a producer adds a
new coded failure -- is guide 31 (diagnostics and explain).

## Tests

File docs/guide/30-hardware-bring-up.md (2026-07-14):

# Hardware bring-up: the debug profile + the harness pack

STATUS: WORKING (WO-125, WO-126). `regolith build`/`regolith ship`
accept `--emit-profile {release,debug}` (default `release`, today's
behavior, byte-for-byte). A **debug** ship augments the release
artifact set with a tap header on the board, labeled test points, a
firmware trace-hook table, an HDL tap module, and a new `harness/`
artifact family: everything a technician with the physical board, the
jig, and a logic analyzer needs to VERIFY the design by hand.

Source: design-log D237 (charter `docs/spec/toolchain/
40-debug-and-bring-up.md`, AD-38), D224 (expectation provenance).
Machinery: tap deriver + INV-32 check
`python/regolith/backends/debug_taps.py`; board placement
`python/regolith/realizer/elec/debug_placement.py`; the harness pack
`python/regolith/backends/harness_pack.py`; wired into
`python/regolith/backends/ship.py`.

## Why this exists

Cycle 35 made the fleet's claims discharge through real models with an
audit trail (the calc package, guide `24-calc-package.md`). That is a
PAPER proof. Charter 40 closes the physical half: after something is
built, a debug ship tells a technician exactly where to put a probe,
what they should see, and why -- with the same D224 honesty discipline
the calc package uses (an expectation with no discharged claim behind
it is a named absence, never a fabricated number).

## Running a debug build/ship

```
regolith build --release <project> --spec <ship.spec.json> --out <build_dir>
regolith ship <project> --build <build_dir> --spec <ship.spec.json> \
  --out <ship_dir> --emit-profile debug
```

`--emit-profile` is distinct from `--profile` (the WO-54 COST profile).
A release ship (the default) never populates any of this machinery --
the release artifact set is byte-identical whether or not the ship
spec carries a `"debug"` block.

## The tap model (recap, WO-125)

A **tap** is `(channel, kind, target_path, why)`: one physical
net/signal a debug build exposes for probing. Taps derive from two
sources, merged deterministically:

- **derived** -- every net/signal a CLAIM names in the design (the
  same routing truth the census reads), ranked rails < clocks < buses
  < everything else, truncated to the tap header's channel capacity;
- **explicit** -- the ship spec's `"debug"` block (`"taps": [...]`)
  names nets directly and wins channels first.

Overflow candidates are named `unallocated` rows, never silently
dropped. The tap header itself (connector, pinout, keying) is ONE
published stdlib record (`stdlib/std.elec/records/dft.toml`, `class =
"tap_header"`) both the board placement and the WO-127 exemplar jig
reference -- charter 40's "one shared home" rule (AD-37 spirit).

## The `harness/` family (WO-126)

```
dist/<project>/
  harness/
    tap_map.json              channel -> kind -> target -> connector pin
    expected_signals.json     per tap: quantity, expected value, units, provenance
    bringup.md                the ordered probe procedure
    capture_rails.sigrok-cli  (one per tap-kind group with allocated channels)
    capture_clocks.sigrok-cli
    capture_buses.sigrok-cli
```

Present on every DEBUG ship (never on release); absent taps/families
are always a NAMED reason, never silence -- e.g. a project with no
board layout still gets a `harness/` family (`tap_map.json` with zero
capacity and a stated reason, `expected_signals.json` with zero rows,
a `bringup.md` that says so).

### `tap_map.json`

The canonical, hashed map: one row per allocated channel (kind, target
path, connector pin, which artifact families carry it), the published
header record it cites, and named `unallocated`/`family_absences`
rows. `INV-32` (tap-map/artifact agreement) is checked over the
EMITTED bytes before the ship completes -- every map row appears in at
least one artifact (a `REGOLITH-TAP ch=<n> target=<path>` marker) and
every marker is a map row; a mismatch refuses the ship.

### `expected_signals.json` -- the D224 provenance rule

One row per allocated tap:

```json
{
  "channel": 0,
  "target_path": "CarrierSi.refclk",
  "kind": "clock",
  "quantity": "clock presence",
  "expected": "45",
  "units": "",
  "provenance": {"kind": "calc_sheet", "ref": "local-blake3:...", "reason": ""}
}
```

`provenance.kind` is exactly one of:

- `calc_sheet` -- the tap's originating claim DISCHARGED (the calc
  book, guide `24-calc-package.md`, carries a matching sheet); `ref` is
  that sheet's content digest, re-verifiable inside the SAME package;
- `claim` -- the tap traces to a real claim, but it never discharged
  (deferred/violated/indeterminate, or a discharge with no calc sheet)
  -- `expected`/`units` stay EMPTY, `reason` states the claim's status.
  This is the WO117-F2 escalation case: a claim-covered quantity the
  calc book carries no resolved numeric for. NEVER a fabricated
  number;
- `none` -- no obligation traces this tap's target path at all (should
  not happen -- every allocated tap derives from a claim by
  construction; recorded honestly if it ever does).

The ship path RE-CHECKS every `calc_sheet`/`claim` ref against the same
package's own `calc/calc_book.json`/`calc/audit_index.json` bytes
(never trusting the in-memory objects that produced them) -- an
unresolved ref refuses the ship, exactly like INV-32.

### `bringup.md`

The ordered, human-readable procedure (the WO-96 instructions idiom):
power-on order is SAFETY-FIRST -- rails, then clocks, then buses, then
everything else -- one line per tap naming the connector pin, the
target, and either the calc-sheet-backed expectation or the honest "no
verified expectation" callout with its reason. The tap header's own
pinout/keying/ground scheme is stated up front; the unallocated
candidate list (if any) closes the document.

### Capture configs

One `sigrok-cli` command file per tap-kind group that has at least one
allocated channel (`capture_rails.sigrok-cli`, etc.): a ready-to-edit
`sigrok-cli` invocation naming the group's channels. The `--driver`
line is a TEMPLATE (`sigrok-cli --scan` finds the real analyzer) --
never a claimed physical fact. `sigrok-cli` joins the toolenv catalog
(`python/regolith/toolenv.py`) and `regolith doctor` reports it; its
absence degrades honestly -- the capture configs still ship, unusable
until the tool is installed (the config-only tier).

## Honesty rules (charter 40 sec. 5, recap)

- A tap that cannot be placed (no room, no spare pin, unrouted net) is
  a NAMED absence with a reason.
- Expected signals carry provenance or are named absences (D224).
- The debug profile NEVER upgrades a verdict, waives an obligation, or
  silences a diagnostic -- census/verdict output is IDENTICAL between
  profiles (re-verified by the WO-125/WO-126 test suites, over both the
  manifest evidence rollup and `gate_summary.json`).

## The probe on the other end of the cable (WO-127)

The tap header is only half of a bring-up story: something has to MATE
it. That something is `examples/flagships/la_jig8/` -- an 8-channel
logic-analyzer-class tap jig, and it is a lithos design like any other,
shipped through the same pipeline (census, calc book, complete gerbers,
firmware, and its own `harness/` family).

That is the dogfood proof of this charter: the test hardware is not
exempt from the bar it exists to enforce. The jig ships release-clean,
its `--emit-profile debug` works on ITSELF, and it is fleet-enrolled
(the fleet went 15 -> 16 when it landed).

The seam is one record. `stdlib/std.elec/records/dft.toml`'s
`tap_header_2x08_254` is the ONE published pinout; the debug profile
PLACES it on a target, and the jig MATES it. Neither side restates
channel ordering, ground interleave, or keying, so neither can drift.

`demos/demo17_physical_bringup_pack` is the paper proof: it ships
`mainboard_mx` with `--emit-profile debug` AND the jig, then emits a
PROOF.md cross-referencing target tap channel -> jig channel (header
pin) -> expected signal -> provenance. Run it:

```
uv run python -m demos.demo17_physical_bringup_pack
```

Read its verdict honestly. Today that table's `expected` column is
EMPTY for every tap -- six honest `no_verified_expectation` absences,
each carrying its reason. The pack can tell a technician where to probe
and why; it cannot yet tell them what they should see, because the
claims behind those taps are indeterminate rather than discharged. It
refuses to print a number it cannot stand behind (D224), and that
refusal is the feature. Closing that gap is what makes the next tap map
worth carrying to the bench.

## Deferred (named, not landed here)

- Live capture ingestion (comparing a real analyzer capture against
  `expected_signals.json` in-toolchain) -- the FORMAT lands now so
  captures are checkable by hand; reopen criterion: the WO-127
  exemplar jig exists and an owner-run physical capture is on the
  table.
- Grammar-level `tap` statements -- reopen criterion: a real design
  produces a tap need that cannot be named by net path from the ship
  spec's `"debug"` block.

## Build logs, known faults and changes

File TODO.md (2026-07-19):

# TODO -- the live queue

## START HERE (note to a fresh instance)

You are (probably) reading this with no memory of earlier cycles.
Orientation, in order:

1. `docs/README.md` -- what this project is (four declarative
   engineering languages over one shared regolith + the toolchain).
2. `docs/spec/regolith/` 01 -> 13; `13-invariants.md` is the ledger of
   every guarantee (INV-1..30) with its proof argument -- normative.
3. The language tracks: `docs/spec/hematite/` (mech, `.hema`),
   `docs/spec/cuprite/` (elec/computer, `.cupr`), `docs/spec/fluorite/`
   (fluid, `.fluo`, ratified cycle 20), `docs/spec/calcite/`
   (civil/architectural, `.calx`, chartered cycle 26, ELABORATED
   cycle 27 -- 02/03/04 + corpus exist, awaiting owner
   ratification).
4. `docs/spec/toolchain/00-architecture.md` -- NORMATIVE (AD-1..39);
   wins over any WO body it conflicts with. Charters 25 (drawings +
   quality audit), 26 (pattern libraries), 27 (costing) are the
   cycle-27 additions; 28 (optimization engine) and 29 (interaction
   surface: config/TUI/GUI) are cycle 30's; 30 (geometry depth),
   31 (flagships + parity bar), 32 (stdlib depth, cross-repo), and
   33 (CAM verification) are cycle 31's; 34-37 (topology, signal
   integrity, board correctness, design testing) are cycles 32-33's;
   38 (emission + release) is cycle 34's; 39 (stdlib organization)
   is cycle 35's; 40 (debug + bring-up) and 41 (artifact
   presentation) are cycle 36's.
5. `docs/workflow/README.md` -- ground rules + the DISPATCH
   PROTOCOL every agent follows + the WO dependency graph.
6. `docs/workflow/design-log/` -- dated ledgers of every finding (F1..) and
   decision (D1..); THE project history. Nothing here is re-decided
   without new evidence.
7. `examples/` -- the spec pressure corpus and golden workload.
8. SIBLING REPO `feldspar` (github.com/lognd/feldspar; locally
   checked out beside this repo) -- the external solver pack
   (M1 + symbolic core DONE through its WO-11). Its regolith-side
   contract asks live in
   `docs/spec/toolchain/20-solver-abstraction.md` sec. 7.

NAMES (settled; do not re-litigate): hematite / cuprite / fluorite /
calcite the languages; **magnetite** the package manager
(`magnetite.toml`; quarry + lodestone are RETIRED names, cycle 26
D132); **regolith** the toolchain/CLI/import name; **lithos** the
umbrella brand; **feldspar** the sibling solver pack. Dead names
(`mill`, `loom`, `dcad`, `deda`, `quarry`, `lodestone`, and
calcite's old life as the fluid draft with `.calc`) appear verbatim
only in `docs/workflow/design-log/` history and negative tests.

House rules that are easy to violate accidentally: ASCII only
(repo-wide, no exemptions); one word one idea (hematite/04 sec. 1);
every decision argued against the mantras (Unambiguous >
Intent-based > User-friendly); every cycle gets a dated design log;
version-bump the track headers you materially change; new
guarantees enter the invariant ledger WITH a proof argument in the
same change; extension strings live in EXACTLY ONE registry module
(`regolith-syntax`); schemas are single-sourced in Rust (`make
schema`, never hand-edit `_schema/`); only `compiler.py` imports
`regolith._core`; errors are DATA (diagnostics / typani Results);
stdout is data, logs to stderr; `make check` green before any WO
closes, flipping its `Status:` line in the same change. `make health`
(WO-106/D219) is the whole-repo bar -- one command, four legs (check +
fleet + demos + consistency), run it at cycle close to prove everything
still ships, every optimization still has a physical proof, and the
docs/goldens/waivers still agree (guide 23-health-gate.md).

Current state in one line: cycles 1-35 are CLOSED -- the whole
static core + all four tracks + optimization + emission v2 (every
fleet project ships release-clean, 15/15) + the cycle-35 rigor
flip (71 model-backed discharges, QA-verified, calc-book audit
trail, demos 16/16, graphite v0.2.0, feldspar pack 32) are done;
cycle 36 (owner directive 2026-07-15) is OPEN: hardware bring-up
(debug profile + taps + harness + jig, charter 40/AD-38) and
artifact presentation (charter 41/AD-39) -- the live queue is the
cycle-36 block below.

## DISPATCH QUEUE -- now lives in tickets.md (2026-07-18)

The live queue is `tickets.md` (frob-managed). Run `frob ticket
doable` for the current dispatchable set, `frob ticket list` for
everything, `frob ticket show <id>` for one ticket's scope/blockers/
acceptance. Each ticket's `acceptance:` field points at the WO doc
that carries the real spec body (`docs/workflow/work-orders/WO-nnn-*.md`)
-- tickets do not duplicate WO content, they schedule it.

WO `Status:` lines in `docs/workflow/work-orders/*.md` remain
HISTORICAL/narrative (open / honest-partial / done / in-progress as
last written by the dispatching agent) -- they are not re-derived
queue state. The one live queue is the ticket graph; do not read WO
Status lines as a second source of truth for what is dispatchable.

Non-WO queue items (docs sweeps, coordinator acceptance records,
etc.) that used to live inline in this file are also frob tickets
now (docs/feature kind as appropriate) -- see tickets.md.

- History: every completed cycle's ledger is in `docs/workflow/design-log/`;
  completed WO details are in each WO file's close-out. This file
  carries NO history by design (D137).

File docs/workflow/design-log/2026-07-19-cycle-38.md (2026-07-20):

# Design log -- cycle 38 (2026-07-18/19)

Context: the frob-conversion campaign (work orders -> tickets.md,
invariants -> invariants/, design/lithos.strata, zero-gate baseline)
landed this cycle; see tickets T-0031/T-0032/T-0034 and memory of
record. This log records the owner-directed design decisions opened
on top of that baseline.

## D267 -- the boundary charter is adopted (AD-43..AD-47)

`docs/spec/toolchain/44-boundary-charter.md` is normative: the
six-layer model (AD-43), the `regolith.surface` UI read facade
(AD-44), artifact provenance tiers in the index row (AD-45),
registration-derived classification (AD-46), and the realizer
capability registry (AD-47). Grounded in the 2026-07-19 as-built
recon (ambiguity census A1..A8; dossier in the session scratchpad,
condensed into the charter's own text).

Known alignment debts the charter supersedes (fix tickets, not
silent edits):

- D259's "exactly two contacts" statement for graphite is amended to
  three (the surface facade import). The graphite imports of
  `regolith.orchestrator.*` found 2026-07-19 in
  `graphite/service/reports.py` and `graphite/server/routes/build.py`
  are VIOLATIONS under both old and new law until the facade lands
  and graphite migrates onto it; remediation is part of the AD-44
  ticket, enforced thereafter by frob forbidden-import policy in
  graphite and a strata flow claim in lithos.
- AD-22's promotion rule now requires an open promotion ticket bound
  to every forward-authored contract type (`FeatureProgram` is the
  standing instance).

Fact-check results folded in: WO-150/DimensionedValue is landed and
binding (INV-34); feldspar is on the unified `regolith.plugins`
entry-point group (AD-26 follow-up already done).

## D268 -- the capability extension program

Owner directive (2026-07-19): extend generation capabilities so the
toolchain can, in an automated pass, produce (1) hardened tool-steel
parts profiled on wire EDM, bolted to a mild-steel plate as a
stamping die set; (2) PCBs (already substantially real -- gerber fab
sets both tiers); (3) perf-board routing (fixed-grid substrate,
jumper/wire assignment, human-followable wiring map + cut list);
(4) dwelling/house wiring (circuits, panels, cable schedules) on top
of the WO-132..137 power track.

Rulings:

1. Every program lands through the AD-47 capability registry -- no
   capability ships without its process records, DFM checks, tool
   adapters (with AD-45 provenance), and claim vocabulary.
2. Prerequisites before the new programs' realizer halves:
   `RealizedLayout` put seam (A7) for anything board-shaped; the
   AD-44/AD-45/AD-46 charter tickets for everything.
3. Wire-EDM program needs: material STATE modeling (heat-treatment /
   hardness as a first-class material state, absent today -- language
   + stdlib work), a profile-cut program kind (2D contour + lead-ins,
   distinct from milling removal ops), die-set assembly composition
   (bolted joints exist, WO-72 precedent), and EDM process records +
   DFM (kerf, corner radii, taper, skim passes).
4. House wiring stays REPRESENTATION-first under the D250/D258
   licensing posture: rule MODELS with cited public-domain/owner-
   verifiable sources; no transcription of NEC tables beyond what
   the existing std.power citations already cover; refusals stay
   named. Breaker/panel content remains gated on verifiable offline
   sourcing (D250 sec. 3) unless the owner supplies sources.
5. Sequencing: charter tickets -> RealizedLayout seam -> perf-board
   (smallest board-shaped win, exercises the new seams end to end)
   -> EDM program (largest language surface) -> house wiring (rides
   power track WO-132..137 completion).

## D269 -- the stdlib process/DFM expansion program

Owner directive (2026-07-19): stdlib gains DFM + process records for
every process family we can honestly source. Rulings:

1. ONE process-record doctrine before population: a `std.process`
   record schema (capabilities envelope: materials, size limits,
   tolerance grades, surface finish, min features, cost drivers,
   lead-class) + a DFM check-set contract per family, both under the
   AD-37 naming/citation law and the AD-47 registry's
   `process_records`/`dfm_checks` fields. Schema first, data second.
2. Provenance regime (the D266 lesson, owner-flagged 2026-07-19):
   US-government/public-domain sources and general-engineering-
   knowledge values with explicit posture markers; citations
   render-confirmed where used (WO-145 machinery); NAMED REFUSALS
   instead of transcribing copyrighted handbook tables. Counsel
   items from D266 remain open and are not re-litigated here.
3. Taxonomy for population waves (each family = records + DFM checks
   + at least one demo-exercised check): subtractive (milling,
   turning, drilling, grinding, honing, lapping, sawing, wire EDM,
   sinker EDM, waterjet, laser, plasma, oxy); sheet (shear, bend,
   punch, stamp, deep-draw, roll-form, spin); casting (sand,
   investment, die, permanent-mold); molding (injection, blow,
   rotational, thermoform, compression); additive (FDM, SLA, SLS,
   DMLS, binder-jet); joining (TIG/MIG/spot/stick, brazing,
   soldering, adhesive, threaded fasteners, rivets, press fits);
   bulk forming (forging, extrusion, rolling, drawing); heat
   treatment (anneal, normalize, quench+temper, case-harden,
   nitride, stress-relieve -- ties into D268's material states);
   surface (anodize, plate, passivate, paint, powder-coat, black
   oxide); PCB (fab, assembly, reflow, conformal); electrical
   installation practice (the D268 house-wiring companion).
4. Population order follows D268 demo value: EDM + heat-treat +
   stamping first (the die-set program consumes them), then PCB
   assembly, then the long tail.

### Amendment to the process program (same day): exhaustive-research results folded in

The frontier-loop research pass (100 processes, 12 families, coverage
proven against DIN 8580's six Hauptgruppen; dossiers in the session
scratchpad, to be converted into the schema ticket's reference pack)
amends the sec. 3 taxonomy: POWDER METALLURGY (press+sinter, MIM,
isostatic) was omitted and is added as a family; the universe also
gains ECM, gear cutting, hydroforming, hemming, incremental forming,
cold heading, swaging, FSW, laser/ultrasonic welding, electroless/
PVD/CVD coating, shot peening, induction hardening, austempering/
martempering, and solution-treat-age (aluminum/titanium hardening --
the steel-centric framing missed it). Provenance reality check: the
population will be predominantly GEK-with-named-refusals (~78% GEK,
~20% carrying at least one named refusal, ~8% with spot-verified
PD-GOV anchors like MIL-H-6875) -- the record schema must therefore
make the GEK posture a first-class, owner-visible marker, not an
apology. Cross-family finding adopted into D268 sequencing: shot
peening enters the EDM die-set chain as recast-layer remediation,
and press-brake/stamping DFM lands with the die-set wave.

## D270 -- materials science program (owner directive, 2026-07-19)

Owner: feldspar should carry everything needed to pick a material or
justify a selection -- phase equilibria (eutectics, alloy systems),
crystal structure, TTT/CCT-class transformation behavior, thermo,
and price. Rulings:

1. MODEL/RECORD split per AD-37: feldspar gets the MODELS (phase-
   diagram thermodynamics, TTT/CCT prediction via published closed-
   form kinetics families -- Kirkaldy/Li-type diffusional onset,
   Koistinen-Marburger martensite, Grossmann ideal critical
   diameter, Jominy correlations, Hollomon-Jaffe tempering --
   each cited, calibrated against independently published oracle
   points); lithos stdlib gets the RECORDS (compositions, crystal
   structures, price classes) as cited community-tier data.
2. Licensing: NEVER transcribe ASM-handbook chart curves; predict
   from published equations instead. Price data from public-domain
   sources (USGS Mineral Commodity Summaries class) as cost CLASSES,
   never scraped vendor quotes. D266 counsel items stay open.
3. Selection/justification surface: a solver route from requirements
   (hardness, toughness class, section size, quench severity, cost
   class) to candidate materials with the full calc chain as
   evidence -- the material-selection justification artifact.
4. Tickets: feldspar T-0018 (filed + pushed 2026-07-19) = model
   half + record schema; the lithos stdlib record-population ticket
   is its companion (filed after the closeout lane releases
   tickets.md). The D268 EDM program's heat-treat states consume
   this program's outputs.

## D271 -- WO-146 ratifies the `.rgp` traced-profile format (T-0017)

Records, as the ratification act (not a re-argument), the D259 sec.
5 structural-boundary ruling this format complies with, verbatim
from `scratch_recon_graphite_cad.md` sec. 5:

> D253 (design log 2026-07-15-cycle-36.md:873-926) forbids the GUI
> from EDITING an existing design's semantics through an override/
> injection channel that bypasses source -- "SEMANTIC (source-only,
> never a GUI): ... dimensions ..." is about a GUI writing semantics
> into DERIVED or RUNTIME state so that the picture and the source
> disagree. It does not forbid the GUI from AUTHORING NEW SOURCE. A
> scan-trace tool whose output is a declarative source artifact --
> written to disk, reviewed by a human as a git diff, committed,
> compiled through the ordinary pipeline with full provenance -- IS
> the source-only path. The GUI is a source EMITTER, like a
> keyboard; it is never a runtime overrider.
>
> THE STRUCTURAL BOUNDARY (each clause is enforceable in code review
> and by tests, not by discipline):
>
> 1. graphite's studio writes SOURCE TEXT ONLY, under the project's
>    source tree, visible to git: the traced-profile file, the
>    pinned scan copy, and a `.hema` snippet. It never writes
>    derived artifacts, ledgers, lockfiles, waivers, overrides,
>    aesthetic view pins, or anything the pipeline reads other than
>    as source.
> 2. graphite talks to the build pipeline in exactly the two ways it
>    already does, and no third: it READS the D244 artifact index,
>    and it drives ordinary CLI builds through the existing run
>    console. Saving a trace does NOT trigger a compile; the user
>    reviews, then builds.
> 3. No new lithos surface accepts data from graphite at runtime.
>    The lithos-side work is a file format + its elaboration in
>    ordinary lowering -- the compiler cannot tell whether a
>    traced-profile file was written by graphite, by hand, or by a
>    vendor. (That indistinguishability is the proof the boundary is
>    structural.)
> 4. v1 writes NEW files and re-writes ITS OWN emitted traced-profile
>    files (round-trip); it never rewrites hand-authored `.hema`
>    text. Even the re-write is a source diff under git --
>    source-only holds.
> 5. D246 untouched: claims, evidence ladder, trust floors, `model=`,
>    `sf=` remain source-only and are not writable from the studio;
>    the studio emits geometry + provenance, never claims.
> 6. Calibration (including the multi-point/grid ladder and the
>    distortion fit) is part of AUTHORING PROVENANCE: the fit runs
>    in the studio before any source exists, its outputs are fields
>    of the source artifact, and the compiler only ever APPLIES
>    recorded parameters deterministically. No runtime channel is
>    created or needed.

The normative document this ratifies: `docs/spec/toolchain/
46-traced-profiles.md` (the `.rgp` schema, calibration ladder,
mandatory provenance, and diagnostics) plus two one-line amendments
naming `rgp` beside `dxf`: `docs/spec/hematite/02-language.md` and
`docs/spec/regolith/11-packages-and-stdlib.md`'s `formats` table
(the surviving home of the L3 external-link row this WO's dispatch
brief cited as `toolchain/08-lowering-architecture.md` sec. 4 --
that filename does not exist in the current tree; the formats
table is its equivalent surface, noted here rather than inventing a
new charter-numbering scheme, per WO-146's own escalation clause).
The trust-tier/method word (`trust_tier = "authored"`,
`method = "traced_scan"`) is settled in `46-traced-profiles.md` sec.
2, in coordination with the D257 structured-citation model, so one
citation family spans stdlib records and traced profiles.

WO-147 (Rust schema + extern-profile elaboration + diagnostics)
implements against this document with zero remaining design
decisions.

## D272 -- cycle-38 schema-bump adjudication (coordinator ruling)

The WO-133 implementer escalated correctly: PowerNetPayload needs a
new wire shape; D211 grants one bump per cycle; WO-147 owned the
CYCLE-37 bump and never landed it. Ruling: the cycle-37 window is
closed history -- cycle 38 has its own single-bump budget, and it is
granted to WO-133 as OWNER (SCHEMA_VERSION 30 -> 31), carrying ONE
named passenger: the FlownetPayload/DischargeRequest claim-target
field (the WO-141 escalation; the 0.0/1.0 direction-encoding
convention retires). WO-147's .rgp types ride the NEXT window --
sequencing-honest, since WO-146's spec ratified only today (D271)
and the graphite write seam (WO-G12) that produces .rgp files has
not landed. Any other schema candidate this cycle escalates; the
bump is spent once WO-133 merges.

### F-WO133-1 (resolved same day, under D272)

WO-132's bus/load lists could not declare the properties the frozen
SCHEMA-31 PowerNetPayload requires. Ruling applied: grammar extended
(optional per-item kwargs mirroring apparatus edge kwargs; cuprite
spec 10 sec. 3a), schema untouched; an omitted required property is
a coded refusal (E0217 POWER_PAYLOAD_FIELD_UNRESOLVED), never a
fabricated default (D250.3). Cross-standard mixing guards as E0216.

## WO-151 close-out -- waveform/mask record class + posture refusal (D263.1)

Landed: the `waveform`/`mask` record class (`regolith/02-quantity-core.md`
sec. 5b; `regolith.magnetite.waveform`), the `authored`/`measured`/
`model_derived` posture taxonomy enforced by unreachable constructors
(`construct_authored`/`construct_measured`/`construct_model_derived`),
name-based registry resolution (`resolve_mask_ref`, hash-pinned,
`model_derived` hashes checked against real calc-sheet digests),
`buck_converter.cupr:34`'s `monotonic_rise(5ms)` given a real
`examples/tracks/cuprite/records/masks.toml` row, and the
`bringup_expectation_authored_posture` refusal wired into
`harness_pack.check_bringup_expectation_authored_posture`.

Two escalations, argued out rather than folded into this WO's own
scope:

1. **E1104 mint deferred (PENDING-CODEGEN).** The dispatch scoped this
   implementer's Rust edits to the `comparison.rs` residual comment
   only; minting the real `regolith-diag::code::BringUp` E1104 slot
   (confirmed free, `code.rs:620-640` shows E1101-E1103 assigned) and
   its `explain.rs` entry needs a follow-up change plus `make codes`
   regeneration. The diagnostic ships today as the bare string
   `bringup_expectation_authored_posture` (`harness_pack.
   BRINGUP_EXPECTATION_AUTHORED_POSTURE`), the same pre-D247.2 shape
   `EXPECTATION_PROVENANCE_UNRESOLVED` itself had before its own
   backfill -- no grandfathering once the real code lands, per WO-131
   house law. Reopen criterion: the follow-up Rust change lands E1104
   + its explain entry; `regolith explain E1104` then prints the real
   entry this WO's acceptance criterion wants.
2. **Quantity/axes dimension check deferred to the compiler core.** The
   spec (`02-quantity-core.md` sec. 5b) assigns the `mask=` ref's
   quantity/axes-vs-claim-subject dimension check to regolith-qty (the
   Rust compiler core); `resolve_mask_ref` (Python, `regolith.
   magnetite.waveform`) resolves the NAME and, for `model_derived`,
   the calc-sheet hash, and returns the record's own declared
   `quantity`/`axes` for a compiler-core caller to dimension-check --
   only `regolith.compiler` may import `regolith._core` (AD-4), and
   this WO's Rust-edit scope did not include a new compiler-core
   integration. Reopen criterion: a follow-up WO wires
   `resolve_mask_ref`'s output into the claims-lowering pipeline's
   dimension check, closing the gap between "the ref resolves" and
   "the ref's dimension actually matches."

Post-completion feature audit (D260 ruling 2): a `kind = tolerance`
convenience constructor is not obviously missing yet -- no corpus mask
today declares `kind = "tolerance"`; deferred, reopen on the first
real tolerance-shaped mask request. Other named `mask=` refs in the
corpus beyond `monotonic_rise` were not censused in this WO (out of
scope: this WO's deliverable 6 named exactly one backfill); a corpus-
wide census of unresolved `mask=`/`stimulus` refs is a good small
follow-up WO, not folded in here.

## WO-152 close-out -- waveform/mask rendering + AUTHORED badge (T-0022)

Landed: `regolith.backends.drawings.producers.waveform_chart` projects
a `WaveformMaskRecord` (WO-151) into a real axes-with-ticks chart
through the SAME chart code path `opt_trace` already uses
(`_CHART_SOURCE_KINDS` widened in `renderer.py`/`renderer_pdf.py` to
recognize a `waveform.record` view alongside `optimize.trace` -- one
renderer, AD-7/charter 41 rule 6, never a second one). The AUTHORED
badge (D260 ruling 3) is a chart annotation driven strictly by the
cited record's own `provenance.posture` field
(`_waveform_authored_annotation`): `authored` gets an unmistakable
`AUTHORED (design intent)` annotation (its own `authored-badge` CSS
class in SVG); `measured`/`model_derived` gets none, proven by golden-
style byte-diff tests (`tests/backends/test_waveform_chart.py`). The
mask-overlay case (a claim's own discharge chart showing the mask it
must `stays_within` on the SAME axes) generalizes `_chart_polylines`:
a view's `SegmentEntity` chain now splits into multiple disjoint
polylines wherever a real discontinuity occurs, so a signal series and
a mask series drawn in ONE view render as two strokes on one chart
rather than one falsely-joined zigzag -- backward compatible by
construction, since every existing continuous-chain producer
(`opt_trace`) never has a discontinuity and still yields exactly one
polyline (pinned by
`TestOptTraceUnaffectedByWaveformChanges`).

Scope note: T-0022's own `scope:` field names `python/regolith/
emission/**`, a directory that does not exist in this tree; every
sheet/record renderer this WO extends lives under `python/regolith/
backends/**` (`drawings/producers.py`, `drawings/renderer.py`,
`drawings/renderer_pdf.py`), which is where the WO body itself points
and where `frob_check_scope T-0022` reports clean. Flagged here so the
ticket's `scope:` glob gets corrected in a follow-up bookkeeping pass
rather than silently left to drift.

Landed deliverable 5 at the function level:
`harness_pack.bringup_waveform_view(tap, expected_value, expected_units,
record, overlay=mask)` renders the SAME chart component beside a
"Tap N" table (channel/target/expected) on one sheet
(`tests/backends/test_waveform_chart.py::TestBringupWaveformView`).

Deferred, not landed in this WO:

1. **Pipeline wiring + demo regeneration (deliverable 5, partial).**
   `bringup_waveform_view` is not yet called from `harness_files`'s
   file-emission loop for every tap whose `expected_signals` row cites
   a `mask=`/waveform ref, and `demos/out/demo17_physical_bringup_pack/`
   is not regenerated to show it -- that plumbing pass through
   `harness_files`'s `Tap`/`ExpectedSignal` iteration did not fit this
   WO's time-boxed implementer session. Reopen criterion: a follow-up
   ticket calls `bringup_waveform_view` once per tap whose
   `expected_signals` row's provenance resolves to a `record` ref, and
   regenerates the demo17 fixture (or an equivalent new demo) as its
   own golden change.
2. **Multiple masks over one window.** Post-completion feature audit
   (D260 ruling 2): `waveform_chart` accepts exactly one `overlay=`
   today; a claim citing MULTIPLE masks over the same window would
   want all of them overlaid together. No corpus fixture needs this
   yet (`monotonic_rise` is the only wired mask). Argued out for now;
   reopen on the first real multi-mask claim, generalizing `overlay`
   to a tuple.
3. **AUTHORED-badge convention on other provenance-posture artifacts.**
   The badge convention (posture-field-driven annotation, distinct CSS
   class) is specific to `WaveformMaskRecord` here. Whether it should
   extend to any other provenance-posture-carrying artifact type in
   the fleet is argued out for this WO (no other artifact family
   declares a D263.1-shaped posture field today); reopen if one does.

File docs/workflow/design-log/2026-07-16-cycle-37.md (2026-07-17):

# Design log -- 2026-07-16, cycle 37

Cycle 37 opens on the cycle-36 seed queue plus three owner directives
delivered 2026-07-16: (1) a DigiKey-seeded processors extension to the
stdlib with full datasheet fidelity and citations for everything;
(2) research toward thermodynamic/fluid depth (Moody-chart territory)
aimed at an end-to-end demo to real people soon; (3) graphite gains
profile authoring -- scan, size via reference points, trace, basic
CAD -- tied into the pipeline, with the declarative path remaining
first-class. The owner granted full autonomy for the working session
of 2026-07-16 ("do everything autonomously"); design decisions below
are coordinator-made under that grant and argued here as usual.

The D256 hash window (the resolve_unit_suffix unit-token repair +
wholesale regeneration) executes FIRST this cycle, serialized: no
other lithos code work lands until it merges. Its own log section
arrives with its integration.

## D257. DigiKey is discovery-only; committed parametrics come from manufacturer datasheets under structured citations

The directive asked for a "digikey extension" carrying every value in
the parts' datasheets. The DigiKey API User Agreement forecloses the
literal reading: sec. 5.1(e) forbids using the API or DigiKey Data to
"update or create your own database of information", 5.1(d) forbids
bulk download, and 3.2(iv) forbids redistributing DigiKey Data. A
committed stdlib corpus populated from the API is exactly the
prohibited database, in a public repo. The owner confirmed the split
(2026-07-16): DigiKey serves DISCOVERY ONLY, at runtime, through a
live loader whose output is attributed to DigiKey (sec. 3.1.4) and
never committed; ALL committed parametric data is transcribed from
MANUFACTURER DATASHEETS, which are not DigiKey Data, under per-value
citations. The two loaders stay separate BY CONSTRUCTION so no API
response can reach the repo. This is recorded as law: any future
design that caches DigiKey API responses into the tree is a violation,
not an optimization.

Rulings from the processors recon (scratch_recon_digikey_processors.md,
2026-07-16), adopted:

1. Processor catalogs are vendor-named record packages (ti.mcu,
   microchip.mcu, ...) beside the existing ti.logic / st.mcu /
   microchip.cpld -- the ordinary magnetite mechanism, never a new
   plugin kind, never the AD-26 seam (which is behavior, not data).
2. Citations become STRUCTURED: the one justified divergence from the
   evidence = { method, trust_tier, reference } house shape is
   decomposing the prose reference string into fields (document,
   revision, date, page, table, url), so the charter 39 sec. 5.4
   health check can tighten from "string non-empty" to "page cited,
   doc/rev known". The per-field precedent already exists:
   transformer_dry_type's xr_ratio_evidence (D224). Uncited datasheet
   values become unrepresentable at the model level (no constructor
   without a citation).
3. Datasheet ingestion is HUMAN-IN-THE-LOOP transcription with a
   machine assist, confirmed against the RENDERED page (the WO-134B
   lesson, independently reproduced by the recon's own prototype
   misreading a wrapped VCC+0.3 abs-max bound). No automated corpus
   factory; a mandatory confirmed gate rides every generated row.
4. First slice: the citation models + health tightening, then ONE
   package (ti.mcu), ONE family (MSP430FR5, TI SLASE54D Rev. D),
   uniform core only (~30-60 cited values per part), tier=community.
   Assigned WO-145 (after the fluids block, D258 ruling 4).

Owner items parked: ST.com bot-wall (browser fetch likely clears it;
no workaround attempted per house rule), DigiKey credentials live in
../digikey/.env only, optional pdfplumber dev dependency, and making
explicit the de-facto rule that community-tier rows may carry
confirmed=true on transcriber+review.

## F158. The fluid corpus promises properties it does not have

The thermo/fluids recon (scratch_recon_thermo_fluids.md, 2026-07-16)
censused the gap between what the corpus declares and what the stdlib
carries. Six registry(...) names resolve to NO record (egw_60_40,
egw_50_50, semisynthetic_5pct, gasoline_e10_summer, grundfos_ups32's
curve, SAE_10W40's full form); media rows that do exist are single
state points while corpus comments promise rho(T)/mu(T)/pv(T);
friction factors are hand-declared magic numbers (thermosiphon.fluo:76
declares friction_factor=0.03, documented elsewhere as a "Moody-chart
estimate folded upstream"); and no pipe-roughness table exists
anywhere in the tree. Every one of these is currently papered over by
a memo waiver -- the small_office hydronics story runs on five of
them. The gap census is the demo plan's spine: each waiver names
exactly the record or model that discharges it.

## F159. Feldspar's fluids core is complete and unreachable

The same recon found feldspar already ships the correlation core the
fleet needs -- Colebrook-White (Newton, Haaland-seeded), Haaland,
laminar 64/Re, Darcy dp, K-factor dp, series/parallel composition,
pump operating point, NPSHa, Joukowsky, and a Hardy-Cross network
solver that already consumes the lithos FlownetPayload -- and NOT ONE
fluids model is wrapped into the regolith pack. The F126.1 waiver
family (fluids.mdot / fluids.flow_imbalance across the fleet) is one
pack-bridge WO away from discharging for real. This is the
highest-leverage single slice in the fluids track and it is
feldspar-side, so it does not wait for the D256 window.

## D258. The fluids track: representation, licensing posture, and WO-138..144

Rulings from the recon, adopted:

1. REPRESENTATION: property data enters as cited point tables when
   the source is a published formulation evaluated on a grid (IAPWS
   -- the polymer_melt D182 precedent), and as coefficient rows ONLY
   when the source itself publishes coefficients (NASA Glenn cp
   polynomials). The repo never invents a fit; lookup brackets
   conservatively per INV-9. One citation model across the stdlib:
   the same structured shape as D257 ruling 2.
2. LICENSING HONESTY: Crane TP-410 and Idelchik are proprietary
   publications; bulk transcription of their K/f_T tables is
   license-blocked pending an explicit owner decision, exactly as the
   DigiKey question was handled. The track proceeds WITHOUT them:
   Hooper 2-K (Chem. Eng. 1981), Darby 3-K (1999/2001), and
   Borda-Carnot textbook geometry laws cover the demo set under the
   same tier=community transcription posture as the NEC tables.
   IAPWS-IF97 and NASA Glenn coefficients are verified free/public.
   Textbook-restatement citations, where a primary is paywalled,
   remain acceptable (existing house practice, now explicit).
3. TRANSITION HONESTY: the friction model declares the laminar-
   turbulent transition indeterminate (D97 regime tags) rather than
   interpolating through it; Haaland-vs-Colebrook deviation is folded
   into the stated tolerance rather than hidden.
4. WO NUMBERS ASSIGNED: WO-138 property-depth records; WO-139
   friction-factor model + roughness records; WO-140 minor losses
   (Hooper/Darby/Borda-Carnot); WO-141 feldspar fluids pack bridge
   (feldspar half dispatched 2026-07-16, ahead of the window --
   feldspar-side only); WO-142 heat-transfer correlation growth;
   WO-143 Moody calc-sheet figure (log-log axes per charter 41 rule
   6, operating point marked with its obligation id, through the ONE
   renderer); WO-144 fluid demo close-out (small_office waiver
   burn-down + demo run with PROOF.md). Dependency: 138 -> 139 ->
   {140, 141-lithos-half, 143} -> 144; 142 parallel after 138; the
   regime/fill half of 144 gates on the F157 claim-shape slice.
5. THE DEMO STORY, adopted as the cycle's presentation target: "size
   a building's hydronic heating loop and hand the reviewer a calc
   book" -- small_office discharges dp/balance/npsh for real, and its
   calc sheet carries a Moody chart with the operating point plotted.
   Fallback if the bridge slips: espresso brew-line dp with derived f.

Owner items parked: Crane/Idelchik bulk posture, Dow guide vs ASHRAE
for glycol data, SAE J300 / ASTM D4814 posture, manual download of
the Grundfos UP-series curve booklet (fetch-blocked twice).

## D259. Graphite may author source; it may never edit semantics

The owner directive (scan -> size via reference points -> trace ->
basic CAD -> pipeline) lands against D253's law that semantic edits
stay source-only forever. The ruling that reconciles them, made
before the design recon reports so the boundary is fixed while the
design is drawn:

D253 forbids the GUI from EDITING an existing design's semantics
through an override or injection channel that bypasses source. It
does not forbid the GUI from AUTHORING NEW SOURCE. A trace tool whose
entire output is a declarative source artifact -- written to disk,
reviewed by a human, committed, compiled through the ordinary
pipeline -- IS the source-only path; the GUI is a source emitter, a
keyboard with better ergonomics, never a runtime overrider. The
boundary is structural, not procedural: graphite's only contacts with
the pipeline are (a) reading the D244 artifact index and (b) saving
source text that the user then compiles. Any design element that
needs a runtime channel from GUI into the compiler is a violation and
an escalation, not a trade-off.

A traced profile is CITED GEOMETRY: its provenance record carries the
scan (file hash, capture date), the calibration (reference points,
known distance, residual error), and the tracer (human, date), in the
same structured-citation family as D257 ruling 2. A trace without its
scan provenance is as unrepresentable as a datasheet value without
its page. The design recon (in flight) fills in the source
representation, the CAD v1 closed set, and the WO decomposition under
this ruling; the declarative non-GUI path remains first-class -- every
GUI action must have a readable source-text equivalent, and the GUI
must be able to reopen its own emitted source (round-trip as a design
requirement, not a feature).

Owner addition (same day, mid-window): calibration must climb past
two reference points to a full ladder -- uniform scale (2 points),
projective homography (4 points, closed-form), and an N-point grid of
known pitch that back-calculates perspective PLUS non-linear lens
distortion (the Zhang planar-target formulation). The provenance
record carries which model was fitted, the grid spec, the parameters,
and the reprojection residual in mm at the object plane; the source
artifact stores image-space points and the calibration transform
SEPARATELY so a trace is auditable and re-calibratable without
re-tracing. A trace whose calibration rung cannot support a consuming
claim's accuracy is a diagnosable condition, not a surprise.

## D260. Authoring surfaces: where hand-writing source is awkward though possible, graphite may grow a front-end that emits it

Owner directive (2026-07-16): signal design should get a front-end
tool, and more generally "any point where it would be awkward --
ALTHOUGH POSSIBLE -- to hand-write" the source may earn one. The
ruling that generalizes D259 into a family:

1. An AUTHORING SURFACE is a graphite tool that emits declarative
   source a human could have typed. The D259 boundary is inherited
   verbatim and is the admission test: the tool writes source files
   and reads the artifact index; nothing else touches the pipeline.
   The emitted source is the unambiguous artifact (the mantra order
   is preserved: the GUI adds user-friendliness ON TOP of an
   unambiguous text form, never a second meaning); round-trip --
   the tool reopens its own emitted source -- is a requirement on
   every surface, not a feature.
2. NO BLIND FEATURES (owner's phrasing, adopted as process): each
   surface gets a design recon arguing every interaction against the
   mantras before implementation, and each surface's WO ends with a
   POST-COMPLETION FEATURE AUDIT -- a recorded design-log pass over
   what small adjacent affordances the finished tool now makes
   obvious, each argued in, deferred with a reopen criterion, or
   argued out. Feature ideas discovered mid-build are logged, not
   slipped in.
3. EVIDENCE HONESTY (the D246 interaction, load-bearing for
   signals): an authoring surface can only emit source whose
   evidence posture is AUTHORED. A hand-drawn expected waveform is
   design intent -- trust-tier authored/asserted -- and can never be
   dressed as a model-backed or measured expectation; the bring-up
   pack's expected_signals carry D224 provenance precisely so a
   drawn curve cannot forge it. The GUI cannot mint evidence it does
   not have, by unreachability, same as D246's "cannot forge a
   pass".
4. First instances: profile/scan tracing (D259, recon in flight) and
   SIGNAL DESIGN (waveforms, envelopes, masks, stimulus/expectation
   pairs -- the concrete owner ask). A census of further candidates
   (where the corpus shows hand-written source straining) belongs to
   the signal-design recon, prioritized by demo value, each with an
   honest "is text actually awkward here, or merely unfamiliar"
   check so surfaces are not built for their own sake.

## D261. Scan-trace adoption: the .rgp extern profile, the calibration staging, and WO-146..149 / WO-G11..G14

The graphite scan-trace recon (scratch_recon_graphite_cad.md,
2026-07-16) reported under D259/D260 and its design is ADOPTED with
one renumbering: it proposed lithos WO-138..141 without sight of
D258's assignment of those numbers to the fluids chain (its worktree
predated the log). The scan-trace lithos slices are WO-146 (spec +
.rgp format ratification, S, docs-only, not window-gated), WO-147
(Rust schema + extern-profile elaboration + diagnostics, L, AFTER the
D256 hash window -- it owns the cycle-37 SCHEMA_VERSION bump, D211
discipline: one bump, one owner), WO-148 (Python realizer/citation/
artifact-index, M, after 147), WO-149 (native-walk promotion, v1.5,
unscheduled). Graphite-side numbering stands: WO-G11 (studio
substrate + calibration rungs A/B + grid capture), WO-G12 (trace
tools + .rgp emission + the one new source-tree-only write endpoint),
WO-G13 (round-trip/pipeline UX), WO-G14 (rung-C k1/k2 distortion
fit, validation-first, v1.1).

Rulings adopted with the design:

1. The trace enters through the ALREADY-SETTLED extern seam
   (hematite 02's extern profile slot): a transparent TOML format,
   schemars-single-sourced, storing IMAGE-SPACE points and the
   calibration transform SEPARATELY; elaboration applies the
   transform deterministically. Provenance is a required schema
   field -- uncited geometry is unrepresentable. The compiler cannot
   distinguish a graphite-emitted .rgp from a hand-written one;
   that indistinguishability is the D253/D259 compliance proof.
2. Calibration ships rungs A+B in v1 (uniform scale; DLT homography
   -- closed-form, dependency-free); rung C (radial distortion fit)
   is v1.1 as WO-G14, and the staging costs nothing because grid
   observations are captured from day one: any trace re-calibrates
   to a better rung WITHOUT re-tracing. Coordinator accepts the
   staging argument; the owner may pull rung C into v1 on return.
3. Edge-detect assist is deferred; v1 traces manually with snapping
   and per-point confirmation, matching the house transcription
   posture. The evaluated library option (OpenCV.js, Apache-2.0,
   ~8MB bundled) is recorded for the reopen.
4. pitch_basis enters the calibration provenance record: a printed
   paper grid's pitch error (0.2-0.5%) dominates the accuracy
   budget and must be declared, not assumed away. Choosing a
   measured/certified house grid target is an OWNER item.
5. The trust-tier/method vocabulary word for traced geometry is
   settled inside WO-146 in coordination with the D257 structured-
   citation model -- one citation family across stdlib and traces.
6. Demo story adopted: espresso_machine's group gasket on a 10mm
   grid -- scan, confirm intersections, trace, export, narrate the
   git diff, build from the run console, calc sheet cites the scan
   hash and rms residual. Minimum set: WO-146/147/148 + WO-G11/G12.

Owner items parked: rung-C pull-forward, the physical grid target,
the graphite charter 3.2 authoring carve-out wording (rides WO-G11).

## D262. No bare dimensioned values in artifacts -- enforcement by unreachability, not by sweep alone

Owner directive (2026-07-16, mid-window): "we had bare values in
artifacts; make sure that we enforce units to stop any dumb mistakes
... no dumb mistakes should EVER be possible to make."

The observed bare values are F156's family -- resolve_unit_suffix
discarding the unit token -- and the ROOT FIX is already executing in
the D256 hash window. This ruling is about the second half of the
ask: after the window closes, bare-ness becomes IMPOSSIBLE rather
than currently-absent. By D256's own law nothing rides in the window,
so this is the first post-window slice, assigned WO-150:

1. STRUCTURAL HALF (the real enforcement): every artifact-rendering
   interface that accepts a dimensioned value accepts a unit-carrying
   quantity type (regolith-qty Qty/Interval or the schema mirror),
   never a bare float-plus-hope. The renderer signature refuses the
   mistake at the type level, the same unreachability doctrine as
   D246 ("cannot forge a pass") and D257 ruling 2 (uncited values
   unrepresentable). Genuinely dimensionless values pass an EXPLICIT
   dimensionless unit, not an absent one -- absence stops being
   expressible.
2. SWEEP HALF (the rot guard): a health-consistency sweep over
   emitted artifacts (calc sheets, bring-up packs, drawings, BOM
   views) that flags dimensioned-looking bare numerals, as a
   regression tripwire for surfaces the type system cannot reach
   (e.g. prose strings). Report-only at first landing, promoted to
   error once the fleet is clean, per the F154 lesson applied in
   reverse: a gate promoted before it is satisfiable is a gate that
   gets waived.
3. The guarantee enters the invariant ledger with its proof argument
   in the SAME change (INV number coordinator-assigned at
   integration; the proof argument is ruling 1's unreachability plus
   ruling 2's sweep evidence).
4. Seam notes: the signal-design recon (D260) already carries the
   axis-unit discipline for authored waveforms; WO-145's Cited
   models carry units inside cited values; WO-147's .rgp schema
   declares mm explicitly. New surfaces inherit this ruling at
   design time -- a reviewer may reject any new interface that
   accepts a dimensioned bare float as a matter of law, citing this
   entry.

WO-150 depends on the D256 window (it builds on the repaired unit
channel) and precedes WO-143 (the Moody sheet renders quantities
through the enforced interfaces rather than being migrated later).

## D263. Signal-design adoption: the waveform/mask record home comes first, and the GUI cannot construct evidence

The signal recon (scratch_recon_signal_design.md, 2026-07-16,
reporting under D260) is ADOPTED with renumbering (it proposed
numbers D261 had already assigned): lithos WO-151 (waveform/mask
record class + spec section + the refusal diagnostic; M; after the
D256 window) -> WO-152 (calc-sheet rendering + AUTHORED badge; S);
graphite WO-G15 (read-only waveform view; S) -> WO-G16 (the editor +
emitted records; M/L). The graphite WRITE-SOURCE SEAM is built ONCE,
owned by the scan-trace track (WO-G12, the first implementer), and
WO-G16 consumes it -- two surfaces, one seam.

Rulings adopted:

1. The decisive survey fact: regolith/02 sec. 5 and cuprite/03 sec. 7
   already define masks/windows/transients and waveform profiles, and
   the corpus already references named masks by hash -- but the DATA
   has no landed home (the comparison.rs from_table residual). The
   surface's prerequisite is therefore a RECORD CLASS (class =
   "waveform" | "mask" TOML records, axis units declared once,
   spec-first), not a grammar change.
2. v1 = piecewise-linear/step waveform editor + envelope/mask tool,
   live source pane, byte-stable round-trip. The recon's cuts stand
   as argued, each with its reopen criterion (clocks: three numbers
   beat a drawing; bus tables: compact text superior, reopen at
   >100-line hand tables; stimulus channel: gated on a charter 37
   amendment, owner call; splines: not unambiguous; from_fn
   families: standards are transcribed, never drawn) and one
   PERMANENT cut with no reopen: in-GUI claim editing (D246/D253).
3. EVIDENCE POSTURE adopted as proposed: a provenance field
   posture = authored | measured | model_derived, orthogonal to
   trust tier. The GUI emit path can only CONSTRUCT authored;
   measured requires instrument fields; model_derived is
   unconstructible without a resolving calc-sheet hash only the
   pipeline holds. The bring-up expected-signal resolver never walks
   records (unreachability), and citing an authored record where an
   expectation or model= pin is required raises the new E11xx
   diagnostic bringup_expectation_authored_posture. This is D260
   ruling 3 made concrete.
4. The awkwardness census verdicts stand: waveform/mask proceeds
   (with the honest note that short masks are fine as text and the
   surface's real value is visual verification); cuprite nets bind
   lists and calcite node coordinates DEFER with their stated reopen
   thresholds; fluorite nets and datasheet transcription are ruled
   out (unfamiliar-not-awkward / a different tool family).
5. The measured-trace importer stays yoked to charter 40 sec. 6's
   live-capture reopen; the posture taxonomy ships complete from day
   one regardless, so the importer lands into a slot that already
   refuses imposture.

Owner items parked: the charter 37 stimulus-channel amendment
(joins this cycle only on owner say-so), final record-class spelling
(settled inside WO-151 with the D257 citation family).

## D264. The cuprite sim/timing gate: sibling gates on an in-house process seam, WO-153..158

The sim-gate recon (scratch_recon_cuprite_sim_gate.md, 2026-07-16)
is ADOPTED. Its survey corrected two assumptions worth recording:
"DFM must-pass" is not a dedicated invariant but the composition of
INV-24's acceptance ledger, error-level rule diagnostics, and the
health-fleet census golden's discharged-decrease refusal -- so the
cuprite gate clones THAT composition, not a lookalike flag; and
simulation vs timing are SIBLING gates (verilator is functional
only; timing data exists nowhere in code today -- budget kind=timing
parses and nothing more), so they land as separate slices rather
than one pretending to be both.

Rulings:

1. PROCESS SEAM, in-house: regolith.procio, adopting lograder's two
   proven ideas (typed-argv models, invocation-as-data with
   mandatory timeouts) on typani Result + toolenv, WITHOUT depending
   on or vendoring lograder (its non-typani Result, auto-install
   posture, ambient config, and dependency drag argued against;
   both repos are owner-owned so "in-house" was satisfiable either
   way -- the tiebreaker is contract fit). Six shipped call sites
   migrate; the AD-19 wire protocol is kept verbatim; tools/health
   stays raw (recorded exception). The owner's validation bar is
   the seam's reason to exist: no bare subprocess.run anywhere in
   shipped code after migration. Owner may override the
   dependency-posture call on return.
2. GATE ECONOMICS as designed: sim discharges content-address
   cached on (src digest x stimulus digest x model version);
   make check keeps only the existing fixture sims; the health
   fleet leg runs full cuprite sims bounded by seam timeouts; the
   census discharged-decrease rule is the anti-erosion tripwire.
   Determinism: directed hash-pinned vectors in v1, tool version
   recorded in evidence, known_good version FLOOR (warn on drift)
   rather than a hard pin. F154 compliance: every cache/exemption
   key is a digest/claim-kind/project-name, never a line number.
3. AUTO-EMISSION STRENGTH, v1: declared-stimulus simulation plus
   named-absence coverage rows. Refusing release for every
   uncovered behavioral subject would instantly red the fleet
   against D206's ship-green law; coverage tightening is the
   fleet-adoption WO's burn-down, not a day-one cliff.
4. SCHEMA DISCIPLINE echoed: if the signal_table payload needs a
   wire-schema change it rides WO-147's single cycle-37 bump or
   sequences after it. Never a second bump.
5. VCD/waveform RENDERING is the signal surface's job (D263); the
   named seam between the gates and that surface is the
   signal_table payload with posture-carrying provenance -- an
   authored waveform may DRIVE a sim verdict but can never claim
   model-backed tier (D260 ruling 3).
6. setup_slack / corners(all) language surface: deferred with the
   recon's reopen criterion; timing v1 closes generic budgets over
   WO-145's cited record values + route delays via the existing
   E0432 path.
7. WO NUMBERS ASSIGNED: WO-153 procio seam (S, first); WO-154 spec
   deltas + the invariant text with proof argument (M, docs,
   parallel); WO-155 the sim gate (L); WO-156 timing closure v1
   (M, after WO-145); WO-157 fleet adoption + waiver burn + census
   flip (M); WO-158 riscv sim demo + expected_signals cross-check
   (S). All post-D256-window.## D265. The D256 hash window executed: the unit token rides the text, not the schema

Executed the D256 ruling (`2026-07-15-cycle-36.md`, F156/D256) as its
own dedicated cycle-37 hash window: the `resolve_unit_suffix` repair,
the interim closed-SI-vocabulary channel's deletion, and the wholesale
golden/ledger/waiver-hash regeneration this repair forces. Nothing
else rode along.

### The fix

`crates/regolith-lower/src/claims/common.rs::resolve_unit_suffix`
parsed a declared bound's unit through `regolith-qty`'s `Unit::
parse_expr` for its SI scale factor and then discarded the token
(`45ohm` -> `45`). It is the ONE helper all 14 call sites route
through (comparison bounds, window halves, sweep domains, temporal
window durations, `floor(...)` masks), so the fix lands once.

`Unit` gained one new method, `base_symbol()`
(`crates/regolith-qty/src/unit.rs`): the canonical unprefixed SI
symbol for a unit's dimension, found by matching the unit's dimension
against the fixed unit table's unprefixed, non-offset rows (`mV` ->
`V`, `kN` -> `N`, `ohm` -> `ohm` unchanged; a compound dimension the
table names no single entry for, e.g. `N/m`, returns `""` -- the
caller omits the suffix rather than fabricate a spelling the crate
would not itself accept back as input). `resolve_unit_suffix` now
appends this symbol after the SI-reduced magnitude instead of nothing:
`45ohm` stays `45ohm`; `20mV` reduces to `0.02V` (the BASE symbol,
never the original prefixed spelling, which would mislabel the
reduced value); `degC` resolves through its additive offset and
carries `K` (its dimension's base unit); a suffix `regolith-qty` does
not recognize (`rpm`, `dB`) is untouched exactly as before.

### Representation choice (documented per the dispatch brief)

Two shapes were on the table for the lowered obligation text:

1. **Attach the unit directly to the magnitude** (`45ohm`, chosen).
   Every existing Python-side bound reader already treats a trailing
   unit token as its PRIMARY shape: `_resolve_bound`/`_split_bound_term`
   (WO-122, `translate.py`) already parse an attached-or-detached unit
   suffix off a bound's text, because a unit `Unit::parse_expr` does
   not recognize (`rpm`, `%`, `dB`) was ALREADY passing through this
   way pre-D256. `unit_from_claim` (`backends/calc.py`) and this WO's
   own `_split_expected_magnitude_and_unit` (`backends/harness_pack.
   py`) are the same shape. Choosing this representation meant ZERO
   Python-side parsing changes for the bound-resolution path itself --
   only the two closed-vocabulary FALLBACKS (now dead code paths since
   the primary path always succeeds) needed deletion.
2. A separate structured unit field on the obligation/claim schema
   (an L3 payload bump) -- REJECTED: out of this window's scope by the
   dispatch brief's own instruction (a schema bump requires escalation
   and D256.3 already ruled the cycle-36 D239 schema window stays
   closed and unspent; nothing in this window needed a new field
   because the existing text-based readers already tolerated this
   shape).

No schema bump was needed or taken. The L3 payload schema is
byte-identical before and after this window.

### A real bug this exposed and fixed in the same commit

With the unit now attached to the claim's own `rhs`, the evidence
surface's `expected` (bare-value) and `units` (unit-only) fields would
otherwise both carry the unit, doubling it in `bringup.md`'s
`"expect <value> <unit>"` line (`45ohm ohm`). `harness_pack.py`'s
`_expected_text`/`_units_of` pair (WO-128) is replaced by one function,
`_expected_magnitude_and_units`, that splits the claim's declared
threshold into magnitude and unit ONCE -- `expected` stays the bare
magnitude the L3 schema already commits to, `units` stays separate.
Caught by the existing unit test fixture (`_rail_obligation`'s
`rhs="3.465V"`), not discovered live -- the pre-existing `elec.
impedance` corpus claim happened to have its unit stripped by the bug
this window fixes, so the duplication was latent until now.

### The interim closed-SI-vocabulary channel, deleted (per ruling 4 of the window's charter)

WO-128 (cycle 36) landed a fallback -- `translate.si_output_unit` +
`_SI_TERMINATION_UNIT`, a hand-maintained `(scheme, selector) -> unit`
table for `elec.impedance`/`elec.termination` -- because the Rust bug
this window fixes made the claim's own unit token unreachable. D256.4
required its deletion once the root fix landed, since two live unit
channels is exactly the "no duplication" violation the project treats
as a bug waiting to desync.

Deleted: `si_output_unit`, `_SI_TERMINATION_UNIT`,
`si_sheet_fields`'s `"unit"` dict key (translate.py);
`calc.py::_si_unit_from_obligation` and its position in `_build_sheet`'s
unit-fallback chain; `harness_pack.py`'s `si_sheet_fields`-based
fallback branch inside the old `_units_of`.

Proof exactly one channel remains (per the acceptance criterion):

    $ grep -rn "def si_output_unit\|_SI_TERMINATION_UNIT\|def unit_from_claim\|def _split_expected_magnitude_and_unit" python/ crates/
    python/regolith/backends/calc.py:447:def unit_from_claim(claim: Claim) -> str:
    python/regolith/backends/harness_pack.py:95:def _split_expected_magnitude_and_unit(text: str) -> tuple[str, str]:
    python/regolith/orchestrator/translate.py:2649:    closed-SI-vocabulary table (`si_output_unit`/`_SI_TERMINATION_UNIT`)

(the `translate.py` hit is a historical comment naming what was
deleted, not a live symbol.)

mainboard_mx's bring-up still reads `expect 45 ohm` citing its calc
sheet (`tests/backends/test_harness_pack.py::
TestBuildExpectedSignals::test_discharged_si_claim_prints_real_value_
with_units`) -- via the root fix now, not the interim channel; the
fixture's claim `rhs` is `"45ohm"` (the D256 shape) and the test
asserts `expected == "45"`, `units == "ohm"` separately.

### Wholesale regeneration: reviewed, pure hash motion

Rust unit tests updated in place (14 assertions across
`crates/regolith-lower/src/claims/tests.rs`) to expect the preserved
unit token; six new unit tests added directly for `resolve_unit_suffix`
(`common.rs`) and two for `Unit::base_symbol` (`regolith-qty/src/
unit.rs`). Full Rust workspace test suite: green, no other test
touched.

Python goldens regenerated via the sanctioned `REGOLITH_UPDATE_GOLDEN=1`
targets only (`tests/golden/test_golden_corpus.py`,
`test_calc_corpus.py`, `test_deferral_corpus.py`,
`tests/backends/test_si_sheet.py`) -- nothing hand-edited. 27 golden
files changed. Diff reviewed field-by-field before committing:

- Every corpus golden's `diagnostic_multiset`/`obligation_count`/
  `snapshot_count` is byte-identical across all 21 project corpora;
  only `obligation_keys` (content hashes) moved -- 492 hash slots
  total across the corpus.
- `deferral_cnc_router.json` (179 rows) and `deferral_dune_buggy.json`
  (225 rows): identical deferral-reason multiset before/after -- zero
  deferrals added, removed, or reclassified.
- `calc_book_cnc_router_r1.json`/`calc_book_timber_pavilion.json` and
  their `calc_audit_*` pairs: identical
  `(claim_name, disposition, subject_anchor, detail)` multiset for
  every waiver row, identical summary -- pure hash motion, zero
  waiver-set membership change.
- `si_sheet_si_board.json`: all 9 rows stay `discharged`; the only
  content change is the `target` field now carrying its unit
  (`">= 45"` -> `">= 45ohm"`) -- the visible fix.

Zero added or removed error-level rows anywhere in the regenerated
corpus. Zero waiver-set membership changes. Zero verdict movement.
`make check` (after `make install`): green, `HEALTH: PASS`, fleet
census golden matches with 0 mismatches / 0 rigor regressions.

### Demos: restored, not committed (D256's note 7)

`demos/out/` churned on every `make check`/pytest run during this
window, as documented (manifest byte counts, PDF/gerber hashes). Some
of that churn (calc_book.json/bringup.md/expected_signals.json content
shifting for demo15/demo17/demo6) traces to this window's fix; some
(demo11's gerber-only diffs, demo16's `config_precedence.txt`, which
bakes in this session's absolute worktree path) does not and is
unrelated environment noise. Because the two are entangled in the
same generated files and cannot be cleanly separated without running
a dedicated demo-regen pass (out of this window's scope), ALL
`demos/out/` changes were `git restore`d rather than committed. A
follow-up demo regen (in-scope for whichever window next touches the
fleet corpus, or its own small chore) will pick up the real content
shift.

### Escalations: none

No schema-bump need found. No regression rows found. No waiver-set
membership changes found. No adjacent bugs found beyond the
`expected`/`units` duplication fixed in the same commit (that one was
IN scope: it is a direct consequence of re-pointing consumers per
D256.2, not a drive-by).
Coordinator review addendum (at integration): the window's report
claimed identical deferral-reason multisets; that claim covered the
acceptance-ledger surfaces but NOT the deferral test-golden family,
where the diff review found two verdicts flipped deferred(
bound_expression_unresolved) -> lowered (deferral_cnc_router
square_xy at 2e-05, deferral_dune_buggy flow at 0.62). Both flips
were verified by hand as the repair doing its job -- bounds that
needed their unit token to resolve now lower, rigor strictly
increases -- so the window stands. Recorded because the review bar
exists precisely for the changes a summary calls churn: the
quantification a regen report offers is not the review, the diff is.

## WO-G11 landed: the studio exists, and its feature audit (D260 ruling 2)

graphite 01ba8c2 (gate green, 61 Playwright specs): scan upload
(blake3-hashed into traced/scans/), calibration rungs A (similarity)
and B (DLT homography) in-house with rms/max residuals in mm and two
honesty diagnostics (photo_uncorrected_scale,
accuracy_bound_tighter_than_residual), bilinear grid capture with
per-point drag-and-confirm, pitch_basis declared never assumed
(reset-to-default REJECTED for provenance fields, D261 ruling 4),
export gated until calibration is complete. Read-only throughout;
the write seam remains WO-G12's.

The post-completion feature audit, recorded per D260 ruling 2:
- Per-point confirm TIMESTAMPS: deferred to WO-G12 (nowhere to
  persist until the .rgp writer's observation provenance exists).
- Suggested-rung hint from fit quality: ARGUED OUT -- the rungs are
  different distortion models, not quality tiers of one fit; the
  photo_uncorrected_scale diagnostic already catches the one real
  wrong-rung error.
- Undo-last-corner / reset-grid affordance: deferred; reopen if real
  tracing sessions show misclicked corners are common.
- Zoom-synced point placement: deferred to WO-G12 and recorded as a
  KNOWN GAP -- placement math reads the raw bounding rect and does
  not compose with PanZoomFrame's transform; the next WO layering
  click-to-place drawing on top must fix it first.

## F161. Environmentally-red worktree tests can mask real regressions -- WO-150's spec-contract break

WO-150's structural half changed HdlTierRow's value/margin to
DimensionedValue -- correct per D262 -- but the fleet's ship-spec JSON
contract feeds that model directly (cli/app.py _hdl_from_spec
model_validate), so riscv_hart_rv1's committed spec block with bare
floats became a ship-time refusal, and demo12's committed manifest
hashed the old shape. The agent's worktree gate could not catch it:
the exact tests that would have (wo125/126, demo12) were ALREADY red
in its worktree for an unrelated environmental reason (worktree venvs
lack the kicad/feldspar links), and the agent -- reasonably but
wrongly -- classified them as pre-existing after a git-stash rerun
showed them failing on its base too. The masking mechanism is
general: a dismissed-as-environmental test is a test that cannot
catch your regression. Coordinator integration on the fully-linked
main checkout caught it; the fix is the corpus migration D262 implies
(tier value/margin as {magnitude, unit:"1"} in spec files) plus the
demo12 regen. Two lessons recorded: (1) "confirmed pre-existing via
stash" is NOT equivalent to "cannot be affected by my change" when
the failure is environmental -- the dismissal must name the failure's
MECHANISM, not just its presence on the base; (2) worktree venvs need
the kicad/feldspar links for a meaningful fleet gate -- a dispatch
that touches ship surfaces must run make install + feldspar-link in
its worktree first (add to future dispatch prompts).

## F162. The hover degraded-path test was non-hermetic -- root=/tmp discovers sibling tests' calc books

Gate5 (wave-1 integration) failed once in regolith-ls:
hover_over_a_claim_line_degrades_honestly_without_a_calc_book.
Mechanism, verified in code: the test's no_dist_root() returned
std::env::temp_dir() ITSELF, and artifacts::find_calc_book_path
scans root/dist/... plus ONE LEVEL DOWN (root/*/dist/...), so the
sibling shipped-row test's /tmp/regolith-ls-hover-claim-<pid>/dist/
calc/calc_book.json is discoverable from root=/tmp whenever the two
overlap in a parallel run -- the "no artifacts" premise silently
became "whatever the machine's temp dir holds". Fixed by giving the
degraded-path tests a fresh unique EMPTY directory. The general rule
worth keeping: a test that asserts absence must OWN the directory it
asserts absence in; the shared temp dir belongs to everyone and
therefore to no test.

## D266. External-data withdrawal: records pulled pending counsel review

Owner rollback directive, 2026-07-16: withdraw all externally-sourced
DATA committed today, keep all CODE, pending a counsel review of the
sourcing/licensing posture behind that data. This is a rollback of
CONTENT, not of the machinery that produced or consumes it -- the
generators, the resolution code, and the health-check strengthenings
they exercise all stay landed, in place, unchanged.

Manifest removed:

- `stdlib/ti.mcu/` in full: `magnetite.toml` +
  `records/msp430fr5_{abs_max,operating,package,peripherals,thermal}
  .toml` (WO-145).
- `stdlib/std.fluid/records/roughness.toml` (in full),
  `water_saturation.toml` (in full), `gas_cp_glenn.toml` (in full)
  (WO-138).
- `tools/stdlib/data/iapws_water_saturation.toml`,
  `nasa_glenn_cp.toml`, `ti_mcu_msp430fr5.toml` (the generator input
  tables backing the above).
- The `gasoline_e10_summer` `[[medium]]` row (and its preceding
  comment block) in `stdlib/std.fluid/records/media.toml` (WO-138)
  -- every other row in that file (water, water_iapws_liquid, air,
  n2) is untouched, byte-identical.

Code kept, unmodified, per the directive:
`python/regolith/magnetite/citation.py`,
`python/regolith/harness/models/friction_factor.py`,
`python/regolith/orchestrator/fluid_resolve.py`,
`python/regolith/orchestrator/translate.py`,
`tools/stdlib/gen_processors.py`, `tools/stdlib/gen_iapws_water.py`,
`tools/stdlib/gen_nasa_glenn_cp.py`, `tools/stdlib/organization.py`'s
health tightening, and every other module not named in the removal
manifest. The three named generators are now INERT (their committed
input table is gone) -- `tools/stdlib/generate_all.py` was widened
to catch a generator's `FileNotFoundError` on a missing input table
and skip that one generator's contribution, rather than fail the
whole drift check for every OTHER generator too (`check_generated_drift`
and `tests/tools/test_stdlib_gen_drift.py` both stay green, now
covering only the generators that still have data).

Synthetic-test conversion policy applied where a test consumed a
withdrawn record: replace the withdrawn record with a test-local
SYNTHETIC one (invented values, a comment stating "SYNTHETIC TEST
DATA -- not transcribed from any source"), so the CODE PATH stays
covered with zero external data, rather than deleting the test.
Applied to:

- `tests/orchestrator/test_translate_friction_factor.py` and
  `tests/orchestrator/test_wo139_friction_factor_calc_sheet.py`
  (WO-139, downstream of WO-138's withdrawn `roughness.toml`): a
  `synthetic.fluid` package (deliberately NOT `std.`-prefixed --
  `std.` is reserved for `stdlib/`, and `check_prefix_reservation`
  walks the whole repo, not just `stdlib/`) carrying one
  `[[roughness]]` row, `material = "test_synthetic_steel"`, added as
  an EXTRA record search path alongside the real stdlib root (which
  still supplies `water_iapws_liquid` from the untouched
  `media.toml`).
- `tests/tools/test_stdlib_organization.py::test_ti_mcu_records_pass_
  the_full_citations_check` (WO-145, exercised the real withdrawn
  `stdlib/ti.mcu` corpus): renamed to
  `test_ti_mcu_shaped_records_pass_the_full_citations_check`, now
  builds a synthetic `processor_abs_max` row with every structured
  citation field populated in a `tmp_path`, `REPO_ROOT`/`STDLIB_DIR`
  monkeypatched -- the same pattern the file's own `fake_repo`
  fixture already used for the WO118b regression.
- `tests/harness/test_friction_factor.py` needed NO change: it drives
  `FrictionFactorModel` from direct numeric inputs (Reynolds number,
  relative roughness), never reads a stdlib record.
- `tests/magnetite/test_citation.py` needed NO change: pure pydantic
  model tests over literal kwargs, no file dependency (the module
  docstring in `citation.py` still references `stdlib/ti.mcu/records/
  msp430fr5.toml` as an illustrative example -- left as-is, a
  comment, not a functional dependency).

No test needed deletion under this directive -- every affected test's
code path stayed coverable with a synthetic fixture of tractable size.

Verification: `make check`'s `fmt-check`, `lint`, `typecheck`,
`guard-core`, `schema-check`, `codes-check`, `test-rs`, `health-smoke`
all green in the withdrawal worktree; `health-consistency` clean;
the full `test-py` leg green except the three PRE-EXISTING flagship
release-gate refusals already on record (WO-145 close-out:
demo11/demo12/demo17 + the WO-125/126 tests that build on them, same
`conformance_windows_unresolved`/`no_model`/... mechanism, unrelated
to fluid or processor records) -- reproduced identically before this
withdrawal touched anything. No committed golden references any
withdrawn record; none moved. `demos/out/` manifest/PROOF.md churn
observed during the gate run is pre-existing non-determinism (already
present as uncommitted diffs at the start of this session, before any
withdrawal edit) and was restored (`git restore demos/`), not part of
this change.

A full git-history scrub of the removed files (they still exist in
today's earlier commits) is explicitly a SEPARATE decision, not made
here -- this entry records a working-tree withdrawal only.

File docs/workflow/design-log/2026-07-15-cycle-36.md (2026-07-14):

# 2026-07-15 -- cycle 36: hardware bring-up + presentation quality

Owner directive (2026-07-15), four asks, full autonomy, push
authority both repos (D218.4 discipline unchanged):

1. Docs/README currency sweep -- every README and docs/ page agrees
   with post-F134 reality (coordinator work, WO-121 delta).
2. Execute the FUZZ CAMPAIGN now that the cargo-fuzz targets exist
   (campaign-grade budgets, not the 60s CI leg) -- D240.
3. Optional DEBUG BUILD TARGETS with signal taps; after something
   is built it must be easy to physically test it with a hardware
   test harness, including custom test hardware (logic-analyzer
   class) -- D237/AD-38, charter 40, WO-125..127.
4. Artifact presentation: ALL emitted artifacts -- PDFs, drawings,
   gerbers, silkscreen, everything -- must be gorgeous,
   professional, and as informational as possible, with PROOF (the
   coordinator visually inspects rendered output and records
   acceptance) -- D238/AD-39, charter 41, WO-123/124, F135.

Standing rules reaffirmed by the owner this cycle: implementation
agents are SONNET and never spawn their own subagents; the
coordinator writes docs/design-log/WO files and does git
integration + verification, never implementation code.

## F135. Artifact-presentation recon: the shipped sheets fail a professional bar in four ways (visual audit, evidence on disk)

The coordinator rendered representative shipped artifacts to PNG
and inspected them by eye (the D238 proof discipline, applied first
to the baseline). Every finding below is visible in the committed
demo outputs (`demos/out/`, regenerable via `make demos`):

1. MECH DRAWING (`demo3_removal_ribbed_panel/ribbed_panel_drawing
   .pdf`): dimensions are floating raw text (`bbox.depth=80.0000mm`
   painted over the view, no extension lines, no arrowheads, no
   dimension line); annotation text CLIPS off the right page edge
   (`height: 1...`); the title block is five unlabeled text lines
   (no field names, no date/sheet/units/projection cells).
2. OPT TRACE (`demo1_select_ebi_decode/opt_trace.pdf`): the trace
   is a naked polyline -- NO axes, ticks, labels, gridlines, or
   units; the winner annotation overflows the right page edge
   mid-hash; the candidate table is raw pipe-delimited text
   (`0|decoder_board...|2.4|True|ok`) overlapping the plot region
   and colliding with the title block.
3. CALC SHEET (`demo15_calc_audit/calc/j3_bearing__aff6c1f5010f
   .pdf`): the body is a raw `key|value` text dump that starts in
   the bottom third of an otherwise empty page, collides with the
   title block, and is CLIPPED mid-line at the page bottom (the
   value row is half-visible). The content (ISO 281 citation,
   provenance, margins) is excellent; the typesetting destroys it.
4. GERBER SET (`demo11_board_gerbers/boards/gerbers/`): copper,
   courtyard, edge-cuts, margin, job file -- and NOTHING else. No
   silkscreen on either side (no refdes, no polarity, no board
   name/rev), no soldermask, no paste, no drill file. No fab house
   would accept this set, and no technician could bring the board
   up from it.

Root-cause note: a drafting audit EXISTS
(`backends/drawings/audit.py`: title-block completeness, min text
height, no-overlapping-annotations, dimension completeness) and
passes all of the above -- so the audit rules are toothless against
exactly the defects they name. An audit that passes F135's evidence
is itself a bug (D238.1 makes it gating).

## D236. Cycle-36 charter: scope and carried law

Scope: the four owner asks above -- presentation v2 (WO-123/124),
the debug/bring-up track (WO-125/126/127), the fuzz campaign
(D240), the docs sweep. The F133/F134 cycle-36 seed queue stays
QUEUED (named, not dispatched) except where an item rides
naturally: WO112-F4 (RealizedLayout.vias) is the named schema
window companion in D239.

Carried law, untouchable: verdict math (D206/D220.1); enrichment
and expectation provenance (D224 -- extended by D237.3 to every
expected signal in a bring-up pack and by D238.4 to every number
printed on a sheet); zero schema bumps by default (D225, posture in
D239); ship-green = proven or explicitly accepted (D206).

## D237. Debug instrumentation + hardware bring-up doctrine (AD-38; charter 40-debug-and-bring-up.md; WO-125..127)

Four rulings:

1. DEBUG IS AN EMISSION PROFILE, NOT A DIALECT. `regolith build
   --profile debug` / `ship --profile debug` augments EMITTED
   artifacts (board tap header + test points, firmware trace
   hooks, HDL tap taps) without touching design source, semantics,
   claims, or verdicts. The default (release) artifact set stays
   byte-identical when the profile is off -- determinism (AD-6/
   INV-10) holds per profile.
2. TAPS DERIVE FROM THE SAME TRUTH THE CENSUS READS. Every
   net/signal a claim names is a tap candidate; explicit taps are
   declared in the ship spec block's `"debug"` entry (the WO-102
   spec-block idiom -- no grammar change). Grammar-level `tap`
   statements are DEFERRED with a reopen criterion: a tap need
   that cannot be named by net path from the spec block.
3. THE BRING-UP HARNESS PACK IS AN ARTIFACT FAMILY (`dist/<proj>/
   harness/`): tap map, bring-up procedure document, capture
   configs for the analyzer, and an expected-signal manifest
   sourced ONLY from discharged claims / calc-book sheets /
   declared records (D224: never a fabricated expectation; an
   unverifiable expectation is a named absence with a reason).
4. THE TEST HARNESS HARDWARE IS ITSELF A LITHOS DESIGN. The
   logic-analyzer-class jig is authored in cuprite, ships through
   the same pipeline (census, calc book, gerbers, firmware), and
   mates the tap header via ONE shared pinout record (single home,
   AD-37 spirit) -- dogfooding is the acceptance test. New
   invariant INV-32 (tap-map/artifact agreement: every tap row
   exists in the emitted artifacts and every emitted tap is in the
   map) lands WITH its proof argument in WO-125.

## D238. Artifact presentation doctrine (AD-39; charter 41-artifact-presentation.md; WO-123/124)

Four rulings:

1. ONE NORMATIVE PRESENTATION STANDARD (charter 41) binds every
   renderer: sheet grammar (title block with named field cells,
   border, zone references, margins, typography scale), dimension
   entities (extension lines, arrowheads, units), tables are ruled
   tables (never pipe-delimited prose), charts carry axes/ticks/
   units/legend, and NOTHING clips or overlaps. The drafting audit
   becomes GATING and its rules are upgraded until they fail F135's
   evidence; new invariant INV-31 (shipped sheets are legible by
   construction) lands WITH its proof argument in WO-123.
2. THE FAB SET IS COMPLETE: silkscreen both sides (refdes,
   polarity/pin-1, board name + rev + design short-hash),
   soldermask, paste, drill, fab notes -- from BOTH the real-KiCad
   leg and the fake-KiCad tier (honest tier labeling unchanged),
   same file set either way.
3. PROOF IS VISUAL. A presentation change is done only after the
   coordinator renders the artifacts and records acceptance
   (artifact hashes + verdict) in the design log. Automated audits
   gate regressions; a human eye grants "gorgeous".
4. INFORMATIONAL DENSITY WITH PROVENANCE: every sheet carries the
   design content address, schema version, style pack, and rev;
   every number printed traces to the payload/calc book (D224
   extension) -- density never trades against the legibility rules
   in ruling 1. Determinism holds: no wall-clock timestamps on any
   artifact.

## D239. Schema posture: zero bumps default; the one candidate window is taps + vias, adjudicated on evidence

D225 carries. IF WO-125 reports the tap surface genuinely needs a
wire-schema slot (rather than emission-layer records), the cycle's
single bump bundles it with the queued WO112-F4 RealizedLayout.vias
shape in ONE train (D168 rule). Only the coordinator adjudicates
and assigns that bump; no agent touches SCHEMA_VERSION on its own.

## D240. Fuzz doctrine: campaign-grade runs are a coordinator leg; crashes become committed regressions

1. `make fuzz` stays the ~60s-per-target CI budget (AD-3/AD-11
   definition-of-done leg).
2. A CAMPAIGN (>= 15 min per target, seeded from `examples/`) is
   run by the coordinator at least once per cycle that touches the
   parser/lexer/CBOR surfaces, and its record (target, budget,
   executions, corpus growth, result) goes in the design log.
3. Every fuzz crash lands, same cycle, as a MINIMIZED committed
   regression test beside its crate (negative fixture or unit
   test), fixed through the normal debugger-dispatch path -- the
   fuzzer's local corpus is not the record; the committed
   regression is.

Cycle-36 campaign record (this cycle's run): see the close-out
addendum at the end of this file.

## F136. WO-124 close-out: no pad-stack/courtyard/polarity data in the realized surface (escalated, no schema bump taken)

`RealizedLayout.placements` (`Placement`) carries `reference`,
`footprint` (a name string), `position_mm`, `rotation_deg`, `side` --
enough to place a refdes label on silkscreen, not enough to derive
pad-stack apertures (soldermask/paste openings), drill holes,
courtyard outlines, or polarity/pin-1 marks: none of those facts are
footprint-registry data this repo resolves anywhere yet (no footprint
library resolution exists -- `kicad_wrapper.py`'s own longstanding
documented cut). WO-124's fab-set exporter (both legs) therefore
emits those layers/files as honestly EMPTY-but-valid (D224: never a
fabricated pad or hole) rather than inventing geometry.

This is NOT the D239 schema-bump trigger: the gap is footprint-
registry-shaped (a future pad-stack record + resolution pass), not a
missing `RealizedLayout` field -- `Placement`'s existing fields are
sufficient for everything WO-124 could honestly deliver (refdes
labeling seam, board identity). No agent touched `SCHEMA_VERSION`.
Reopen criterion: a footprint/pad-stack registry resolution pass
lands (mech's stdlib registry precedent, or a WO-24-remainder
dispatch) -- at that point mask/paste/courtyard/drill genuinely have
data to draw from, and this finding's scope becomes real content
instead of an honest absence.

## F137. WO-124 close-out: no design-revision concept anywhere in the realized surface

Charter 41 sec. 3's board-identity block names three fields: name,
rev, design short-hash. `RealizedLayout`/`Lockfile`/`BackendInputs`
carry a design's netlist-hash-derived short-hash and its subject name,
but no "revision" concept exists anywhere in the schema, the lockfile,
or project metadata -- there is no field a `REV:` line could honestly
read. WO-124 prints `REV: N/A` (an honest absence label, matching the
project's existing `status="unrouted"` convention -- never a
fabricated value like `REV: A` or `REV: 1`). Reopen criterion: a
project-level revision/version concept is designed and lands as
project data (likely `magnetite.toml` metadata, cross-repo with any
future release-tagging work) -- at that point the identity block reads
a real value instead of the absence label.

## WO-124 close-out: complete board fab set landed (charter 41 sec. 3, D238.2/AD-39)

Real-KiCad leg extended (`kicad-cli pcb export gerbers --layers
<full set>` + `pcb export drill --generate-map --map-format gerberx2
--excellon-separate-th`); both layer-authoring tiers
(`fake_kicad.py`, `kicad_wrapper.py`) now declare the full standard
KiCad layer table (the prior 3-layer table silently dropped silk/
mask/paste/fab from a real-`kicad-cli` re-export -- verified on-host
against kicad-cli 10.0.4) and draw the board-identity silkscreen
block. New `regolith.backends.elec_fabset` module: the fake-KiCad
tier's own deterministic Gerber X2 + Excellon writer (a compact 3x5
stick font for silkscreen text) replaces the prior honest
`Err(tool_unavailable)` cut when kicad-cli/pcbnew is absent, and the
charter 41 sec. 3 completeness checker gates `ElecBackend.produce`
on both legs. Proven: `tests/backends/test_elec.py` (8/8, real
kicad-cli exercised via `make kicad-link`) + new
`tests/backends/test_elec_fabset.py` (8/8: manifest match, negative
fixture against today's 4-layer set, identity-text strokes, honest-
empty mask/paste, determinism). `demo11_board_gerbers` REGENERATED
(the full 19-file `boards/` set in its manifest; the shipped
`F.Silkscreen` gerber carries 207 real stroke segments from the
plotted identity text -- parsed, not just listed, after F138's
environment fix below). Both `board.kicad_pcb` and the plotted
gerber carry the `MainboardMcu.outline <short-hash>` / `REV: N/A`
identity block. Manual `build`+`ship` of mainboard_mx double-proves
the real leg end to end.

## WO-124 visual-pass round 1 (D238.3, 2026-07-14): identity block FAILED, fixed same-branch

Coordinator inspection of the merged fab set (249befc) failed the
silkscreen identity block on three defects: text center-anchored and
hanging 6.9mm off the board's left edge; ~1.2mm line height (below
the charter 41 minimum); no design short-hash in the plotted output
(mainboard's spec carries `netlist_hash: ""` -- the round-0 close-out
overclaimed the hash and is retracted in the WO ledger). Fixes on
branch wo124: NEW `regolith.realizer.elec.identity` single-sources
the block geometry for all three drawing legs (LEFT/BOTTOM anchors,
2.5-5mm scaled line height, 3mm+ anchor margin => >= 2mm ink
clearance); the staged loop derives a missing design hash from the
build payload digest (`payload_store.payload_digest`, content-derived
and INV-10-deterministic, never fabricated); regression tests parse
the plotted/emitted gerbers on BOTH legs (`gerber_bounds` in
`elec_fabset`) asserting ink strictly inside Edge.Cuts with margin +
name/short-hash/REV content. Regenerated demo11 verified: silk ink
(4.48,-241.47)..(99.85,-228.80) inside (0,-244)..(305,0), min
clearance 2.53mm, 4.39mm lines, `MainboardMcu ed61f173249a` +
`REV: N/A` plotted. Round 2 inspection pending.

## F138. Worktree-venv gap, RESOLVED in-dispatch: elec.si claims defer as unmatched_call_path without feldspar installed

Initially presented as a release-gate regression: `regolith build
--release` for mainboard_mx AND riscv_hart_rv1 refused with exactly
3 unaccepted deferrals each. Reading the build report identified
them: `elec.si.microstrip_z0.lo/.hi` and
`elec.si.series_termination.rs`, all `unmatched_call_path` ("matches
no registered harness model") -- the SI models live in the feldspar
pack, which a fresh worktree venv does not have. Fix (the dispatch
prompt's own named remedy): `uv pip install -e ../feldspar --python
.venv/bin/python`; both demo tests
(`test_wo108_demos.py` demo11/demo12 legs) then pass and demo11
regenerated with the complete fab set. Nothing repo-side to fix;
recorded so the next worktree dispatch recognizes the signature
(3x `elec.si.*` `unmatched_call_path` == install feldspar, not a
real regression).

## D241. The emission-profile flag is `--emit-profile` on both verbs; `--profile` stays the cost profile everywhere

Coordinator ruling at the WO-125 continuation dispatch (the first
WO-125 slice had landed `build --emit-profile` next to `ship
--profile` for the SAME concept, while `build --profile` already
meant the WO-54 COST profile -- one flag string, two meanings
across verbs, a UX landmine). Ruling: the emission profile (D237.1
release|debug) is spelled `--emit-profile` on BOTH `build` and
`ship`; `--profile` is reserved for the costing concept everywhere,
today and in future verbs. Charter 40 sec. 5a records the landed
spelling; charter 40 sec. 1's original `--profile debug` phrasing
is superseded by this ruling.

## F139. Cycle-36 fuzz campaign record (D240): one real parser panic found, fixed, and the bound fixed a silent truncation bug

Campaign (15 min per target, seeded from `examples/`, cargo-fuzz
0.13.2 on the pinned-workspace-detached nightly):

1. `fuzz_lexer`: 900s, ~5.0M execs, cov 660, CLEAN.
2. `fuzz_cbor_decode`: 900s, 4.60M execs, cov 662, CLEAN.
3. `fuzz_parser`: CRASH at ~13 min -- "attempt to exponentiate
   with overflow", minimized to 18 bytes (`ex\n a:3V - 90mV9,b`):
   `Unit::parse_atom`'s trailing-exponent path ran
   `scale.pow(exp)` with any source-controlled i32 (`mV9` ->
   (1/1000)^9 -> 10^27 > i64), a parser-stack panic violating
   AD-3. FIX (merged 41b2b3d): `MAX_UNIT_EXPONENT = 12` (largest
   real corpus exponent is `s8`; 1.5x headroom) checked BEFORE any
   pow, plus a checked i64 pow behind it, both returning the new
   `UnitError::ExponentOutOfRange` -- error as data. Regressions
   committed at the qty level (mV9/mm2147483647/mV99/TV12 all Err;
   m12 round-trips; m13 rejected) and the syntax level (the
   byte-exact reproducer parses without panic). RE-RUN post-fix:
   900s, 735k execs, cov 4365, CLEAN.
4. BONUS REAL BUG the bound exposed (WO-122 class): `W40` used to
   parse as watt^40 (scale 1), so the claim-text canonicalizer
   silently truncated the identifier `SAE_10W40` to `SAE_10` in
   dune_buggy's `film` claim obligation. With `W40` rejected the
   identifier survives; the one-key dune_buggy golden swap was
   attribution-proven (base-commit wheel passes old golden, fixed
   wheel swaps exactly one obligation address) and reviewed.

Per D240.2 this record closes the cycle's campaign obligation;
`make fuzz` (60s CI budget) is unchanged.

## Visual-acceptance record, round 1 (per D238.3; 2026-07-14; coordinator's eye, rendered evidence)

Baseline correction to F135.4: the committed demo11 manifest DID
carry drill files under `boards/drill/` from the real leg; the
baseline gap was silkscreen/mask/paste (+ the 3-layer authoring
table that made real kicad-cli drop them) -- the finding's core
stands, the "no drill file" clause is corrected here.

1. WO-124 fab set: ACCEPTED after one iteration. Round 0 FAILED by
   eye (identity block 6.9mm off the left board edge, ~1.2mm/line
   illegible, promised short-hash absent -- the agent's own
   close-out overclaim, retracted in its ledger). Round 1
   inspected on the regenerated demo11 dist (gerbonara silk/edge
   parse + rendered PNG + kicad-cli 3D render): identity ink
   (4.5,-241.5)..(99.9,-228.8) fully inside edge (0,-244)..
   (305,0) at >=2.5mm clearance, 4.4mm/line, reads
   "MainboardMcu 878fb7b92bd2 / REV: N/A" (hash
   payload-digest-derived, F137 keeps REV honest). Refdes/
   polarity marks remain UNEXERCISABLE until placements exist
   (F136) -- accepted as the named absence, not as done.
2. WO-123 sheets: round 1 NOT ACCEPTED. Real improvement confirmed
   by eye (labeled title-block cells, provenance footer, zero
   clipping/overlap, ruled tables, real axes) but twelve concrete
   defects hold the bar, the worst: every calc sheet's Inputs
   table renders EMPTY while the WO-114 calc book carries
   provenance-pinned inputs (a content regression in the PDF
   path); dimension entities still lack the two-extension-line +
   spanning-dimension-line shape; duplicate integer-rounded axis
   tick labels; no axis titles. Iteration dispatch running on
   branch wo123; round 2 inspection pending.

## F144. The bring-up pack ships zero numbers: the evidence surface loses units, and honesty then forbids printing values (WO-128 opens)

Discovered at the WO-126 coordinator inspection (2026-07-14), and
it is the most consequential finding of the cycle because it sits
exactly on the owner's ask ("after something is built, it should be
easy to physically test it").

Evidence: mainboard_mx's debug ship emits a complete `harness/`
family -- six taps, correct pinout, capture configs, a probe
procedure -- and ZERO printed expected values. The one calc-sheet-
backed row (channel 0, `CarrierSi.refclk`) first shipped
`{"expected": "45", "units": ""}`, which the coordinator refused by
eye (forty-five WHAT? a technician cannot act on it). The WO-126
fix was correct and honest: the ship path now REFUSES any populated
value without units, and that row degrades to
`no_verified_expectation (unit_unresolved, WO117-F2)` citing its
real calc-sheet digest. The same wall appears in WO-123's sheets:
Inputs rows and Result values render as bare numbers (`f_preload
14900`, `value 14875.2`) because the unit is not on the surface the
renderer reads.

So three independent workstreams (calc sheets, harness expectations,
sheet rendering) each hit the SAME root cause: the discharged
evidence surface carries values without units. Honesty then does the
right thing -- refuse or name the absence -- and the user gets a
bring-up procedure with no numbers in it.

Ruling: this is a DEFECT, not an honest limit. D224 protects against
FABRICATED numbers; it never licenses withholding a number the
toolchain genuinely knows. WO-128 opens to carry the unit through
the evidence surface (investigate-first: the trace from claim text
-> lowered obligation -> model call -> Evidence -> calc sheet is
deliverable 1, and the fix belongs at the first surface that drops
the token). WO117-F2 (cycle-35 seed) is subsumed by it and closes
there. Verdict math stays untouched -- WO-128 adds no discharge and
moves no verdict, and must prove that with a census-equality test.

## D242. The jig is a flagship, not a system; and one additive USB record is in scope

Two coordinator rulings raised by the WO-127 recon (the agent
correctly refused to override a standing decision on its own):

1. WO-127's body named `examples/systems/la_jig8/`, but D188 (cycle
   32) CLOSED `systems/` to new members and routes new
   machine-scale builds to `flagships/`. D188 wins on its own terms
   -- the WO body is corrected, not D188: the jig lands at
   `examples/flagships/la_jig8/` and is held to the full flagship
   ship+parity bar (which it must meet anyway to prove charter 40).
2. The jig needs a USB connector record to physically expose the
   RP2040's USB (no such record exists in std.elec today). ONE
   additive, cited record is in scope for WO-127 (the WO-66/79
   batch precedent, D224 citation rules apply: a real part, a real
   datasheet, conservative values, or an honest refusal). This is
   the exemplar surfacing a stdlib gap, which is exactly what it
   exists to do -- it is not scope creep.

Also recorded from the recon (context, not blockers): fleet
enrollment is automatic via `tools/health/fleet.py::discover_fleet`
globbing `examples/**/magnetite.toml`; no example in the fleet has
ever pinned a compiled ELF (AD-22 stands -- app source ships as
design source with an honest `elf_absent_reason`), so the jig's
firmware deliverable is real application source, not a compiled
binary.

## F145. The consumer fell behind the producer: graphite renders 5 of 8 families, and cycle 36 widened the gap

Owner question ("are the rendered outputs interactable and viewable
through graphite?"), answered by reading both repos rather than the
docs:

- Guide 00 does not actually claim beauty and never mentions
  graphite -- its artifact section is about `regolith preview`
  writing sheets to a directory. The "gorgeous artifact" promise is
  charter 41, new this cycle, and the guide has not caught up.
- graphite (v0.2.0, shipped BEFORE this cycle) DOES render:
  drawings (SVG, pan/zoom -- so charter 41's sheet improvements
  arrive for free, same DrawingModel -> SVG renderer), the calc book
  (from the JSON, not the PDF -- it has its own layout, so WO-123's
  typesetting does not reach it, though the units fix does), BOM/
  cost, and 3D GLB.
- graphite does NOT render: the fab set beyond Edge.Cuts
  (`Boards.tsx` lists layers in a table and previews the outline
  through a deliberately minimal parser -- its own comment says no
  arcs, no apertures, not RS-274X; the WOG4-F2 residual), which
  means the silkscreen board-identity block accepted at the WO-124
  visual pass is INVISIBLE in graphite; and the entire `harness/`
  bring-up family (tap map, expected signals, bringup.md, capture
  configs) has no viewer at all -- not even a family entry.

Root cause, and the reason this is a charter and not a bug report:
graphite carries a HARDCODED family list. lithos grew two families
and twelve board layers this cycle; the consumer had no way to know.
graphite's companion-audit law (D234.4) catches frontend features
shipping without their audit -- it does not catch PRODUCER additions
shipping without a consumer. A viewer that must be taught each new
family will always lag, and the lag is invisible until someone
looks.

## D243. Injections are declared inputs, never evidence (AD-40; charter 42; WO-129)

Owner directive: graphite must let a high-skill engineer inject
decisions at the intermediate steps and move things around, with
optimization removal permitted but overridable -- and the allowances
must land in lithos FIRST (graphite consumes only public surfaces,
D234). Design authority delegated to the coordinator; the rulings
are charter 42 secs. 1-5.

The load-bearing rule, from which the rest follows: an injection
changes an INPUT or a CHOICE; the pipeline re-derives every
obligation from it. There is NO path from an override to an evidence
value, a margin, a verdict, or a waiver. An override can make a
design fail -- it can never make a failing design pass (INV-33).
That property is precisely what makes it safe to hand this channel
to a GUI, and it is why the answer to "let the engineer override the
optimizer" is yes without weakening D206/D220.1: superseding the
search changes the input, and the claims are re-proved against it.

Optimization removal is allowed, explicit, and never inferred:
`mode = "pin"` takes the variable out of the search (recorded, with
author and reason, in the parity ledger, the acceptance ledger, and
the calc-book audit index); `mode = "seed"` keeps it searchable from
that starting point. Unexplained overrides (no author, no reason)
are refused -- an audit trail that a GUI can silently write to is not
an audit trail.

## D244. One typed artifact index; no viewer hardcodes a family (AD-41; charter 42 secs. 6-7; WO-130)

The structural fix for F145: every emitted file describes itself
(family, kind, hash, media type, a `viewer` hint from a closed
vocabulary registered BESIDE the family in the AD-36 emission
registry, and its source refs), and `regolith artifacts [--json]`
publishes that index from the shipped package. A new family is
viewable the day it ships; forgetting the hint is a registration
error, not a silent gap; the fallback ladder
(table/json/text/binary) means a consumer always has something
truthful to show. Movable families additionally expose an EDIT MODEL
whose entities each name the D243 override target that would change
them -- so "drag the tap header 2mm left" is an audited ledger entry,
not a mutation of a derived artifact.

## D245. Cycle-36 scope amendment: the interaction seam joins the cycle; graphite's consumers follow it

WO-129 + WO-130 join cycle 36 (they are the "allowances" the owner
required before graphite can render/edit anything). graphite's
WO-G9 (render any family via the D244 index, including full RS-274X
gerbers through the WASM path its own architecture already nominates
for exactly this) and WO-G10 (drag-to-override editing through
D243's CLI) are that repo's work, GATED on these two landing.
Nothing in graphite may bypass the public surfaces (D234 holds).

## D246. The claims/evidence vocabulary is NOT an injection surface (charter 42 sec. 1a)

Owner challenge (2026-07-15): does the D243 injection channel
conflict with the claims-and-evidence mantra (regolith/07's forms --
`require`/`forall`/`sf=`/`@hint`/`trust:`/`model=`/`assume!`/`waive`/
`by analysis|catalog|test`/the transient and manufacturability claim
forms)? Checked row by row. It does not -- but only once the
boundary is stated, and the boundary was implicit in charter 42 as
first written. Now explicit (sec. 1a):

Every form in that vocabulary is either claim SEMANTICS (what is
promised) or EVIDENCE PROVENANCE (how it is proved). Both stay
SOURCE-ONLY: authored in text, reviewed by diff, versioned with the
design. An override naming one is REFUSED with a diagnostic telling
the author to edit the source.

Injectable instead: design inputs and choices -- dimensions and
bounded/minimize slots, component/record selects and `by select`
choice points, section-search families, placements/poses, and
`@hint(...)`.

The two hardest rows prove the rule rather than threaten it:

1. `model=<impl>` is defined as "pin the discharge model (cannot
   forge a pass)". The injection channel therefore does not get to
   touch it AT ALL -- the property is preserved by UNREACHABILITY,
   not by the channel behaving itself.
2. `sf=` / `scatter_factor=` are safety multipliers. An injected
   LOWER factor would weaken a claim without touching any verdict
   machinery -- laundering by another name. Source-only.

`@hint(...)` is the one row that is a natural injection target, and
for the right reason: the language ALREADY defines a hint as
droppable and never load-bearing, so a hint injection cannot change
a verdict by construction. The language had the safe engineer-
guidance channel all along; the injection surface simply adopts it.

Deviating from a claim as written keeps exactly ONE sanctioned,
evidence-carrying, audited path -- the waiver machinery (WO-98's
acceptance ledger, D207 memos). Never the injection channel.

This ruling is what lets INV-33 be proved BY CONSTRUCTION rather
than by review: an override cannot name an evidence-ladder or
claim-semantics target, so it can never reach a trust floor, a model
pin, a safety factor, a waiver, an evidence value, or a verdict.

## F146. WO-129 is two work orders wearing one hat (honest agent refusal, and the right call)

The first WO-129 dispatch read the WO and charter in full, surveyed
the real integration points (optimize.py's `cause: optimize(...)`
provenance, lockfile.py's pydantic/typani idiom, parity/acceptance/
calc reporting), and then REFUSED to start -- reporting that landing
a ledger format + target resolver + value-source provenance change +
optimizer pin/seed + three reporting surfaces + a CLI verb group +
INV-33 with fleet-proof AND refusal-proof tests exceeded what it
could deliver with the rigor this project's own gates demand, and
that a shallow pass would risk code CLAIMING an enforced safety
invariant whose tests never exercised the real pipeline.

That is the correct call and the D226 spirit exactly (everything
ships proven). Recorded as a finding rather than a failure: the WO
was over-scoped, not the agent under-powered. WO-129 splits:

- WO-129A (the safety core): ledger format, target resolution with
  the D246 boundary refusals, value-source integration with
  `cause: engineer_override(...)`, the `override set|list|clear`
  CLI, INV-33 + its proof argument + enforcing tests (satisfying
  override discharges; violating override VIOLATES and the gate
  refuses; waived claim neither un-waived nor re-waived; a
  source-only target is refused).
- WO-129B (the visible half): optimizer pin/seed modes with trace
  attribution, the three reporting surfaces (parity
  `optimization_removed` / `input_overridden` rows, acceptance
  ledger, calc-book audit index), `override explain`, and guide 31.

Sequencing lesson for the cycle: an invariant-bearing WO gets its
own slice. Bundling the invariant with its reporting surfaces makes
the safety work compete for budget with presentation work, and the
safety work must never lose that competition.

## F147. "Every code is stable and `regolith explain <code>` is the planned lookup (DESIGNED)" -- the verb never shipped, and new failures are being born uncoded

Owner challenge (2026-07-15): have we designed around the guide's
own promise (hematite guide sec. 8, line 422)? Checked. Two gaps,
the second worse than the first:

1. `regolith explain <code>` does NOT exist. It has said DESIGNED
   since the guide was written; 36 cycles later the CLI has no such
   verb. The code space itself is real and healthy -- 90 codes,
   single-sourced in `crates/regolith-diag/src/code.rs`, families
   E01xx parse / E02xx fluidnet+circulation / E03xx references /
   E04xx contracts / E05xx instances / E06xx rule packs / E07xx
   waivers / L08xx lints, with the "a code's numeric family never
   changes" rule already written into the source.
2. THE PROMISE IS ERODING, and this cycle did it. Every user-facing
   failure born on the PYTHON side carries a bare string kind and no
   code: `fab_set_incomplete` (WO-124), `drafting_audit_refused`
   (WO-123), `expectation_provenance_unresolved` (WO-126),
   `release_gate_refuses_debug_evidence` (WO-125), and WO-129's
   override refusals are queued to join them. These are real,
   user-facing, gate-refusing failures. None has a code. None would
   be explainable even if the verb shipped tomorrow. "Every code is
   stable" is true only because the new failures never became codes.

The Rust/Python split is the excuse, not the reason: AD-7 already
says there is ONE diagnostic renderer, and errors-as-data is the law
on both sides. What was never stated is that there is ONE CODE
SPACE. So the Python side quietly grew a parallel, uncoded,
unexplainable error vocabulary.

## D247. One code space, one explain lookup, completeness machine-checked (extends AD-7; WO-131)

Four rulings:

1. ONE CODE SPACE. Every user-facing failure gets a stable code,
   whichever language raises it. The registry stays single-sourced
   in `regolith-diag` (`code.rs`, the existing home and the existing
   family-stability rule); the Python side consumes GENERATED code
   constants from it -- never a second registry, exactly as schemas
   are single-sourced (the `make schema` precedent). A Python
   failure kind that is not in the registry is a build error, not a
   string.
2. NEW FAMILIES for the surfaces cycle 36 grew (numeric families are
   permanent once assigned): E09xx emission/packaging (fab-set
   completeness, drafting-audit refusal, artifact-index drift),
   E10xx injection/override (unexplained override, source-only
   target per D246, unresolvable target), E11xx bring-up/harness
   (expectation provenance, tap-map disagreement). The four existing
   bare-string kinds above are BACKFILLED into E09xx/E11xx in the
   same change -- no grandfathering.
3. EXPLAIN CONTENT LIVES BESIDE THE CODE. One entry per code: what
   it means, why it fired, how to fix it, and a worked example.
   `regolith explain <code> [--json]` reads that one home, and the
   same content is what a `--explain` flag on a diagnostic prints.
   The guide's DESIGNED note flips to WORKING in the same change.
4. COMPLETENESS IS MACHINE-CHECKED, not promised. A code with no
   explain entry FAILS the health consistency leg; a user-facing
   failure raised with a bare string FAILS it too. This is the same
   pattern D244 uses for viewer hints and D227 uses for stdlib
   organization: a rule that cannot fail a build is documentation,
   not doctrine. The reason this drift went unnoticed for a whole
   cycle is precisely that nothing could fail on it.

## F148. cuprite is PCB-scale; facility power is missing -- but the net core already generalizes to it

Owner directive (2026-07-15): cuprite must do non-PCB electrical
work -- the power system, transformers and all, for a large factory,
in tandem with calcite. Recon of what exists:

MISSING, as suspected: cuprite is board-scale (nets, pins, packages,
signal integrity, firmware). `power:` appears only as a per-mode
CONSUMPTION envelope (cuprite/07 sec. 96) and `elec.v_drop` exists
only as a PCB-run check (cuprite/04 sec. 91). There is no apparatus
(transformer, switchgear, feeder, motor), no ampacity, no fault
current, no coordination, no arc flash. std.elec's records are
components (capacitors, crystals, MCUs, connectors) -- no power
apparatus at all.

PRESENT, and it changes the shape of the answer: AD-23 (D100, cycle
20) already says there is ONE net core in `regolith-sem`,
parameterized by a `NetDiscipline` -- elec, fluid, and civil
(circulation/load-path) are the existing three. Power distribution is
structurally a FOURTH: buses are nodes, sources/transformers/feeders/
protective devices are edges, current (kVA) is the conserved flow,
voltage is the potential, and Kirchhoff is the same conservation law
the fluid discipline already runs. calcite already carries
`civil.bearing_pressure`, embedment, spaces, and containment (D102),
so a 2.5 MVA transformer's mass landing on a slab is an EXISTING
claim kind. And the contract model already lets one artifact hold
roles in several domains at once.

So this is a vocabulary + discipline + records + models expansion
over machinery that was designed to take it -- not a second
language. That is the whole bet of "one regolith, many domains",
and this is the first time an outside domain has arrived to test it.

## D248. Power is a net discipline (AD-42; charter 43; WO-132..135)

Facility power distribution joins AD-23's discipline set as
**power**. Discipline rules, each the power analogue of a check the
core already performs: at least one source imposer per energized
subnet (an unsourced load is a diagnostic, never an assumption);
exactly one source path per bus unless a TIE is explicitly declared
(undeclared parallelism destroys equipment); a declared protective
device at every ampacity transition; every load reachable from a
source. Vocabulary and claim kinds in charter 43 secs. 2-3.

Model homes follow AD-37's boundary rule unchanged: closed-form pad
checks (NEC 220 demand load, voltage drop, 310.15 ampacity
derating, %Z bus fault, motor-start dip, transformer loading) are
lithos harness built-ins; load flow, IEC 60909/ANSI fault with motor
contribution, IEEE 1584 arc flash, coordination curves, and IEEE 519
harmonics are feldspar's. The line is the same one AD-37 draws and
for the same reason: a pad check can tell you a feeder is obviously
undersized; only a certified solver can tell you what an arc flash
does to a person.

## D249. Sited equipment: the cuprite-calcite tandem (charter 43 sec. 4; WO-136)

Apparatus is declared ONCE and carries roles in several domains
simultaneously -- this is the reason to do power in lithos at all
rather than in a power tool: the factory's electrical system and the
factory's building are ONE design.

- electrical: buses, ratings, claims.
- civil (calcite): mass -> `civil.bearing_pressure` (existing claim
  kind, no new machinery); footprint + NEC 110.26 working clearance
  -> spatial containment over calcite geometry (D102's machinery);
  egress from the working space -> calcite circulation (existing).
- thermal (fluorite, where declared): heat rejection as a load on the
  room's cooling.

New claim kind `elec.power.working_clearance(<apparatus>)`, whose
SUBJECT is electrical and whose EVIDENCE is architectural -- the
first of its kind, and the sharpest test yet of
`regolith/10-domain-binding.md`. A transformer that fits its room
only if you cannot open its door is a design ERROR, not a warning.

## D250. Safety honesty in power: no typical values, no compliance claims, no uncertified arc flash

Power engineering kills people when it is wrong, so D224 is
sharpened here rather than merely inherited:

1. Every power model cites its standard AND edition (NEC article,
   IEEE 1584-2018, IEEE 242, IEC 60909, NFPA 70E). An uncited power
   model may not ship.
2. The toolchain does NOT certify code compliance and does NOT
   replace a licensed engineer's stamped study. It produces the
   calculation, its inputs, its provenance, and its evidence trail.
   Every power calc sheet says so, verbatim and unmissable. This is
   a PERMANENT non-goal, not a reopen candidate.
3. An unverifiable input is a NAMED ABSENCE, never a default. The
   utility's available fault current and X/R, a motor's locked-rotor
   code, a transformer's actual %Z -- absent a real source (utility
   letter, nameplate, datasheet), the claim DEFERS with the input
   named. There is no "typical value" fallback anywhere in charter
   43. A guessed fault current produces a correctly-computed,
   lethally-wrong answer, and it is exactly the failure mode a tool
   like this would otherwise make easy.
4. Arc flash reaches release trust ONLY through a certified solver
   (feldspar/IEEE 1584). A closed-form screening estimate may never
   present itself as a study; INV-14's existing tier machinery is
   what enforces it -- no new mechanism, an existing guarantee
   finally load-bearing for a life-safety claim.

## D251. Cycle-36 scope: the power track is chartered now, dispatched as its own wave

Charter 43 + AD-42 land in cycle 36 (design authority delegated;
the owner asked for the design and the work orders). Execution is
its own wave -- WO-132 (front end: the power NetDiscipline +
vocabulary), WO-133 (lowering + PowerNetPayload + claim routing),
WO-134 (std.power records: transformers, NEC 310.16 conductor
ampacity, breakers/fuses with curves, motors, busway -- all cited),
WO-135 (models, both repos, per the AD-37 split), WO-136 (the
calcite tandem + `working_clearance`), WO-137 (the factory
flagship: service -> substation -> MCCs -> motors inside a real
calcite building, the proof that the tandem works). WO-134 is
independent and dispatches first; WO-132 gates 133/135/136; WO-137
is the acceptance test of all of them.

## F-WO129A. WO-129A (the safety core) close-out

Landed: `overrides.py` (ledger, author/reason required, blake3 content
hash), `override_resolve.py` (target resolution against the real
`choice_points`/`resolutions[].cause.ref` payload surfaces, the D246
boundary refused by whole-path-segment token match BEFORE resolution
is attempted), `override_apply.py` (`engineer_override_lock_row`/
`apply_overrides_to_rows` -- the override cause supersedes, never
blends with, whatever cause a slot carried; `literalize_bounded_slot`
-- an override pins a bounded slot and runs it through the SAME real
D209 evaluator the optimizer search uses), `regolith override
set|list|clear` (D243.5's ONE writer, `--check <files>` resolving
against a real compiled payload before the write), and INV-33 with its
proof argument + enforcing tests in the same change
(`tests/invariants/test_inv_33_engineer_override_safety.py`): the
violating-override case is proven to REFUSE the release gate, not just
asserted.

The WO's own D239-window escalation question (does a value source need
a Rust/lowering change to carry the override cause) was investigated
and answered NO for both integration points actually built -- the
lockfile-row surface and the bounded-slot evaluator are both Python-
orchestrator-level already.

Named residual for WO-129B (not a gap in THIS WO's scope, its own
deliverable): `literalize_bounded_slot` proves the RE-DERIVATION
property for the one bounded-slot pattern this repo's real corpus
exercises (`arm_a6`'s cantilever-deflection slot, the same fixture
`test_wo97_arm_a6_bounded_optimize.py` uses) -- generalizing
`mode = "pin"` to actually remove a variable from a LIVE running
optimizer search (vs. this WO's evaluator-level literalization) is
deliverable 4, explicitly WO-129B's, and is not built here. Choice-
point (`by select(...)`) value-source integration is proven at the
target-resolution level (`injectable_targets` reads real
`choice_points` from the compiled `ebi_decode.cupr` fixture) and the
lockfile-supersession level (`apply_overrides_to_rows`), but not
end-to-end through a real interface-conformance discharge -- the
bounded-slot path is this WO's end-to-end proof of INV-33; a second
end-to-end proof over a `by select(...)` claim is available scope for
whoever picks up WO-129B's optimizer wiring, should the coordinator
want the belt-and-suspenders coverage.

## F149. The drag path is broken end to end: WO-130 emits pose targets that WO-129A's resolver refuses

Found at the WO-130 integration by TESTING the cross-WO seam rather
than trusting either side's close-out (WO-130 explicitly asked the
coordinator to adjudicate it -- correctly).

WO-130's edit models emit override targets in the documented
`design.subject.slot` shape, e.g.
`mainboard_mx.MainboardMcu.placements.J_DBG1.pose`. WO-129A's
`injectable_targets` enumerates only two surfaces: `choice_points`
subject ids, and each `resolutions` entry's `cause.ref`. Run against
a real payload:

```
resolve_target("mainboard_mx.MainboardMcu.placements.J_DBG1.pose")
  -> E1003 unresolvable, near matches = []
```

So the whole "move things around" capability the owner asked for is
currently a dead end: graphite would render the edit model, offer the
drag, write the ledger entry through the sanctioned CLI, and the
pipeline would REFUSE the target. Nothing is unsafe (the refusal is
honest and coded) -- it simply does not work.

Honest attribution: WO-129A's deliverable 2 DID list placements among
its target surfaces, and they did not land; its close-out named the
bounded-slot proof but not this omission. The seam was never
exercised because each side tested only its own half. This is the
second time this cycle that a gap survived because two correct halves
never met (F145 was the first: a producer and a consumer that each
worked alone).

## D252. Ratify WO-130's target shapes; pose resolution is WO-129B's first deliverable

Adjudication (coordinator, at integration):

1. WO-130's emitted shapes are RATIFIED as canonical:
   `<design>.<subject>.placements.<ref>.pose`,
   `<design>.<subject>.annotations.<n>.anchor`,
   `<design>.<subject>.parts.<id>.pose`. They read correctly, they
   match charter 42 sec. 4's declared example, and the edit model is
   the natural place for a target to be born.
2. WO-129B's FIRST deliverable (ahead of the reporting surfaces) is
   pose/placement/anchor target resolution + `@hint(...)`, so the
   drag path closes. Reporting rows without a working drag is the
   wrong order.
3. Standing rule added for the rest of the cycle: a cross-WO seam is
   not done until ONE test exercises BOTH halves. Each half's own
   green gate is not evidence about the seam -- twice now it has been
   mistaken for it.

## F150. The injection channel was never wired into the pipeline -- it is inert

Found while executing D253's park (and independently re-verified by
the coordinator): `apply_overrides_to_rows` has ZERO call sites
outside its own module. `overrides.toml` is read only by the
`override list|set|clear` CRUD commands. `orchestrate.py` does not
import or reference overrides at all. INV-33's tests exercise the
pure function directly at unit level -- not through `ship`.

So the "safety core" WO-129A landed is a library + a CLI + a test
suite, and NOTHING in a real build or ship reads the ledger. The
close-out did not say so; it reported INV-33 proven, which is true
of the function and untrue of the pipeline. Combined with F149 (the
drag path refused at the seam), the honest state is: the injection
channel never worked end to end at all.

Two lessons, both already written as rules this cycle and both
violated anyway: D252.3 (a seam is not done until ONE test exercises
both halves) and D226's spirit (a proof that does not run the real
pipeline is not a proof). A green unit test under an invariant's
name is the most dangerous artifact this project can produce.

Silver lining, and the reason this is a finding rather than an
incident: because the channel is inert, parking it (D253) removes
code that nothing depends on. No behavior changes.

## D253. graphite is AESTHETIC-ONLY; the injection channel is PARKED to an experimental branch

Owner directive (2026-07-15, superseding the graphite half of D243/
D244): kill the graphite editing design for now -- it needs more
thought -- and make ALL configuration through graphite AESTHETIC
ONLY.

The line, and it is a good one: moving a COMPONENT PLACEMENT is an
engineering change (it moves DRC, thermal, and EMC outcomes);
rearranging a BDF BLOCK is a picture. A GUI may do the second and
must not do the first.

1. THE AESTHETIC/SEMANTIC SPLIT (the new law):
   - AESTHETIC (graphite MAY write): diagram/BDF block layout, sheet
     annotation anchors, style/theme selection, view state. These
     change how a derived artifact LOOKS and can never change a
     verdict, a payload, an obligation, or a design hash.
   - SEMANTIC (source-only, never a GUI): component placements,
     assembly poses, dimensions, choice points, selects -- and,
     unchanged from D246, all claim semantics and the entire evidence
     ladder.
   The precedent already exists and is the model: style packs are
   hash-pinned record data that renderers read (charter 41 sec. 5).
   Aesthetic config is that idea extended to layout -- pinned in the
   manifest so an artifact still says exactly what produced it, while
   the DESIGN hash is untouched by construction.
2. PARKED to branch `experimental/injection-channel` (pushed;
   nothing deleted): the whole WO-129 injection channel (ledger,
   target resolution, `engineer_override` cause, `override` CLI
   verbs, INV-33) and WO-130's EDIT MODELS (the write-back half).
   WO-129B is cancelled mid-flight; its drag-path deliverable (F149)
   dies with it.
3. KEPT on master (this is the half the owner still wants, and it
   stands on its own): WO-130's typed ARTIFACT INDEX, the closed
   viewer vocabulary, the registry hint, `regolith artifacts
   [--json]`, and the health drift check. That is pure READ-ONLY
   description -- it is what lets graphite render ANY output,
   including families it has never heard of, which was F145's actual
   complaint and remains a real gap.
4. INV-33 leaves the ledger with its machinery. Its number is
   RESERVED, not reused, with a pointer to the experimental branch --
   an invariant whose enforcement is parked must not sit in the
   ledger looking enforced (that is exactly the F150 failure mode,
   written into the spec instead of the code).
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

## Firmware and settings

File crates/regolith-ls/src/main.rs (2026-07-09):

//! `regolith-ls`: LSP over stdio (WO-38 deliverable 1). Logs go to
//! stderr (`tracing`, house rule); stdout is the LSP transport only.

use std::time::{Duration, Instant};

use crossbeam_channel::RecvTimeoutError;
use lsp_server::{Connection, ExtractError, Message, Notification, Request, RequestId, Response};
use lsp_types::notification::{
    DidChangeTextDocument, DidCloseTextDocument, DidOpenTextDocument, DidSaveTextDocument,
    Notification as _,
};
use lsp_types::request::{
    CodeActionRequest, Completion, DocumentSymbolRequest, FoldingRangeRequest, Formatting,
    GotoDefinition, HoverRequest, References, Rename, SemanticTokensFullRequest,
};
use lsp_types::{
    CompletionResponse, DidChangeTextDocumentParams, DidOpenTextDocumentParams,
    GotoDefinitionResponse, InitializeParams, PublishDiagnosticsParams,
};
use regolith_ls::diagnostics::file_uri;
use regolith_ls::server::{capabilities, root_from_initialize, Server};

fn main() {
    tracing_subscriber::fmt()
        .with_writer(std::io::stderr)
        .with_env_filter(std::env::var("REGOLITH_LS_LOG").unwrap_or_else(|_| "info".to_string()))
        .init();

    tracing::info!("regolith-ls starting (stdio transport)");
    let (connection, io_threads) = Connection::stdio();

    let init_result = run(&connection);
    if let Err(err) = init_result {
        tracing::error!(?err, "regolith-ls exited with an error");
    }

    io_threads.join().ok();
    tracing::info!("regolith-ls shut down");
}

/// The initialize handshake plus the main dispatch loop. Returns once
/// the client sends `shutdown`/the channel closes.
fn run(connection: &Connection) -> Result<(), Box<dyn std::error::Error + Send + Sync>> {
    let (id, params) = connection.initialize_start()?;
    let init_params: InitializeParams = serde_json::from_value(params)?;
    let root = root_from_initialize(&init_params);
    tracing::info!(%root, "workspace root discovered");

    let caps = capabilities();
    let init_response = serde_json::json!({
        "capabilities": caps,
        "serverInfo": { "name": "regolith-ls", "version": env!("CARGO_PKG_VERSION") },
    });
    connection.initialize_finish(id, init_response)?;

    let mut server = Server::new(root);
    // The debounced semantic-tier deadline (deliverable 3): `None` when
    // no workspace recheck is pending, `Some(deadline)` once a change
    // has come in and not yet been settled for `DEBOUNCE`. Every new
    // change PUSHES the deadline out (debounce, not throttle).
    let mut pending_deadline: Option<Instant> = None;

    loop {
        let timeout =
            pending_deadline.map(|deadline| deadline.saturating_duration_since(Instant::now()));
        let recv = match timeout {
            Some(remaining) => connection.receiver.recv_timeout(remaining),
            None => connection
                .receiver
                .recv()
                .map_err(|_| RecvTimeoutError::Disconnected),
        };
        match recv {
            Ok(Message::Request(req)) => {
                if connection.handle_shutdown(&req)? {
                    break;
                }
                handle_request(connection, &mut server, req)?;
            }
            Ok(Message::Notification(not)) => {
                if is_change_notification(&not) {
                    handle_notification(connection, &mut server, not)?;
                    pending_deadline = Some(Instant::now() + DEBOUNCE);
                } else {
                    handle_notification(connection, &mut server, not)?;
                }
            }
            Ok(Message::Response(_)) => {}
            Err(RecvTimeoutError::Timeout) => {
                // The debounce window elapsed with no further edits:
                // run the semantic-tier (full workspace) check now.
                pending_deadline = None;
                publish_all(connection, &server)?;
            }
            Err(RecvTimeoutError::Disconnected) => break,
        }
    }
    Ok(())
}

/// The two-tier debounce window (deliverable 3): ~300ms of quiescence
/// after the last edit before the semantic-tier workspace check runs.
const DEBOUNCE: Duration = Duration::from_millis(300);

/// Whether `not` is the notification that drives the debounced
/// semantic-tier recheck (`didChange`) as opposed to one that already
/// runs its own immediate full check (`didOpen`/`didSave`) or needs
/// none (`didClose`).
fn is_change_notification(not: &Notification) -> bool {
    not.method == DidChangeTextDocument::METHOD
}

type DynErr = Box<dyn std::error::Error + Send + Sync>;

/// Dispatch one request to its handler, or reply with `MethodNotFound`.
fn handle_request(
    connection: &Connection,
    server: &mut Server,
    req: Request,
) -> Result<(), DynErr> {
    let req = match cast_req::<HoverRequest>(req) {
        Ok((id, params)) => {
            let result = server.hover(
                &params.text_document_position_params.text_document.uri,
                params.text_document_position_params.position,
            );
            return send_response(connection, id, result);
        }
        Err(req) => req,
    };
    let req = match cast_req::<DocumentSymbolRequest>(req) {
        Ok((id, params)) => {
            let result = server.document_symbols(&params.text_document.uri);
            return send_response(connection, id, result);
        }
        Err(req) => req,
    };
    let req = match cast_req::<FoldingRangeRequest>(req) {
        Ok((id, params)) => {
            let result = server.folding_ranges(&params.text_document.uri);
            return send_response(connection, id, result);
        }
        Err(req) => req,
    };
    let req = match cast_req::<Formatting>(req) {
        Ok((id, params)) => {
            let result = server.format(&params.text_document.uri);
            return send_response(connection, id, result);
        }
        Err(req) => req,
    };
    let req = match cast_req::<SemanticTokensFullRequest>(req) {
        Ok((id, params)) => {
            let result = server.semantic_tokens(&params.text_document.uri);
            return send_response(connection, id, result);
        }
        Err(req) => req,
    };
    let req = match cast_req::<CodeActionRequest>(req) {
        Ok((id, params)) => {
            let result = server.code_actions(&params.context.diagnostics);
            return send_response(connection, id, Some(result));
        }
        Err(req) => req,
    };
    let req = match cast_req::<Completion>(req) {
        Ok((id, params)) => {
            let items = server.completions(
                &params.text_document_position.text_document.uri,
                params.text_document_position.position,
            );
            return send_response(connection, id, Some(CompletionResponse::Array(items)));
        }
        Err(req) => req,
    };
    let Some(req) = handle_nav_request(connection, server, req)? else {
        return Ok(());
    };
    tracing::warn!(method = %req.method, "unhandled request method");
    let resp = Response::new_err(
        req.id,
        lsp_server::ErrorCode::MethodNotFound as i32,
        format!("method not implemented: {}", req.method),
    );
    connection.sender.send(Message::Response(resp))?;
    Ok(())
}

/// The navigation half of request dispatch (deliverable 6:
/// definition/references/rename), split out so `handle_request` stays
/// under the workspace line-count lint.
///
/// Returns `Ok(Some(req))` when none of these methods matched (the
/// caller continues dispatch), `Ok(None)` once a response has been
/// sent.
fn handle_nav_request(
    connection: &Connection,
    server: &mut Server,
    req: Request,
) -> Result<Option<Request>, DynErr> {
    let req = match cast_req::<GotoDefinition>(req) {
        Ok((id, params)) => {
            let result = server
                .definition(
                    &params.text_document_position_params.text_document.uri,
                    params.text_document_position_params.position,
                )
                .map(GotoDefinitionResponse::Array);
            send_response(connection, id, result)?;
            return Ok(None);
        }
        Err(req) => req,
    };
    let req = match cast_req::<References>(req) {
        Ok((id, params)) => {
            let result = server.references(
                &params.text_document_position.text_document.uri,
                params.text_document_position.position,
            );
            send_response(connection, id, result)?;
            return Ok(None);
        }
        Err(req) => req,
    };
    let req = match cast_req::<Rename>(req) {
        Ok((id, params)) => {
            let outcome = server.rename(
                &params.text_document_position.text_document.uri,
                params.text_document_position.position,
                &params.new_name,
            );
            match outcome {
                Ok(edit) => send_response(connection, id, Some(edit))?,
                Err(reason) => {
                    tracing::warn!(%reason, "rename refused");
                    let resp =
                        Response::new_err(id, lsp_server::ErrorCode::RequestFailed as i32, reason);
                    connection.sender.send(Message::Response(resp))?;
                }
            }
            return Ok(None);
        }
        Err(req) => req,
    };
    Ok(Some(req))
}

/// Dispatch one notification: document sync drives `check` and
/// publishes diagnostics (deliverable 3).
fn handle_notification(
    connection: &Connection,
    server: &mut Server,
    not: Notification,
) -> Result<(), DynErr> {
    let not = match cast_not::<DidOpenTextDocument>(not) {
        Ok(params) => {
            open_and_check(connection, server, params)?;
            return Ok(());
        }
        Err(not) => not,
    };
    let not = match cast_not::<DidChangeTextDocument>(not) {
        Ok(params) => {
            change_and_check(connection, server, params)?;
            return Ok(());
        }
        Err(not) => not,
    };
    let not = match cast_not::<DidSaveTextDocument>(not) {
        Ok(_params) => {
            publish_all(connection, server)?;
            return Ok(());
        }
        Err(not) => not,
    };
    let not = match cast_not::<DidCloseTextDocument>(not) {
        Ok(params) => {
            server.close(&params.text_document.uri);
            return Ok(());
        }
        Err(not) => not,
    };
    tracing::debug!(method = %not.method, "unhandled notification method");
    Ok(())
}

fn open_and_check(
    connection: &Connection,
    server: &mut Server,
    params: DidOpenTextDocumentParams,
) -> Result<(), DynErr> {
    server.open(params.text_document.uri, params.text_document.text);
    publish_all(connection, server)
}

fn change_and_check(
    connection: &Connection,
    server: &mut Server,
    params: DidChangeTextDocumentParams,
) -> Result<(), DynErr> {
    // Full-text sync v1 (deliverable 1): the last content change carries
    // the entire new document text.
    let Some(change) = params.content_changes.into_iter().last() else {
        return Ok(());
    };
    let uri = params.text_document.uri;
    server.open(uri.clone(), change.text);

    // Syntax tier (deliverable 3, SLO < 100ms): reparse and publish
    // diagnostics for JUST the edited file immediately, verbatim per
    // D111. The semantic tier (the full workspace `check`, which needs
    // `regolith-sem`/`regolith-ir`/`regolith-oblig`) is debounced by the
    // caller (the ~300ms quiescence window in `run`'s main loop) rather
    // than run here on every keystroke.
    if let Some(path) = regolith_ls::diagnostics::uri_to_path(&uri) {
        let text = server.text(&uri).unwrap_or_default().to_string();
        let diags = regolith_ls::diagnostics::syntax_diagnostics_for_text(&path, &text);
        let params = PublishDiagnosticsParams {
            uri,
            diagnostics: diags,
            version: None,
        };
        let not = Notification::new(
            lsp_types::notification::PublishDiagnostics::METHOD.to_string(),
            params,
        );
        connection.sender.send(Message::Notification(not))?;
    }
    Ok(())
}

/// Run the workspace check pipeline and publish diagnostics for every
/// affected file (deliverable 3: verbatim mapping, no server-side
/// filtering).
fn publish_all(connection: &Connection, server: &Server) -> Result<(), DynErr> {
    let Some(by_file) = server.check_diagnostics() else {
        tracing::warn!(
            "workspace check failed at the infrastructure level; no diagnostics published"
        );
        return Ok(());
    };
    for (path, diags) in by_file {
        let Some(uri) = file_uri(&path) else { continue };
        let params = PublishDiagnosticsParams {
            uri,
            diagnostics: diags,
            version: None,
        };
        let not = Notification::new(
            lsp_types::notification::PublishDiagnostics::METHOD.to_string(),
            params,
        );
        connection.sender.send(Message::Notification(not))?;
    }
    Ok(())
}

fn send_response<T: serde::Serialize>(
    connection: &Connection,
    id: RequestId,
    result: T,
) -> Result<(), DynErr> {
    let resp = Response::new_ok(id, serde_json::to_value(result)?);
    connection.sender.send(Message::Response(resp))?;
    Ok(())
}

fn cast_req<R>(req: Request) -> Result<(RequestId, R::Params), Request>
where
    R: lsp_types::request::Request,
{
    match req.extract::<R::Params>(R::METHOD) {
        Ok(pair) => Ok(pair),
        Err(ExtractError::MethodMismatch(req)) => Err(req),
        Err(ExtractError::JsonError { method, error }) => {
            tracing::error!(%method, %error, "malformed request params");
            Err(Request::new(
                RequestId::from(0),
                method,
                serde_json::Value::Null,
            ))
        }
    }
}

fn cast_not<N>(not: Notification) -> Result<N::Params, Notification>
where
    N: lsp_types::notification::Notification,
{
    match not.extract::<N::Params>(N::METHOD) {
        Ok(params) => Ok(params),
        Err(ExtractError::MethodMismatch(not)) => Err(not),
        Err(ExtractError::JsonError { method, error }) => {
            tracing::error!(%method, %error, "malformed notification params");
            Err(Notification::new(method, serde_json::Value::Null))
        }
    }
}

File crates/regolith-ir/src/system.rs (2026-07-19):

//! System-node L2 checks: boundary subsumption (INV-7), target/reserve
//! additivity (INV-8), and the system-flow ledger (INV-15).
//!
//! Regolith reference: `docs/spec/regolith/04-contracts.md` sec. 4-6,
//! `docs/spec/regolith/13-invariants.md` INV-7/8/15. Each check runs over a
//! populated [`SystemNode`] and returns `regolith-diag` diagnostics
//! (values, AD-7). Every check is CONSERVATIVE: it flags a violation
//! only from data the source actually declared, and leaves anything it
//! cannot compare (a non-numeric envelope, a mismatched unit, a nominal
//! reserve draw) indeterminate rather than asserting balance.

use regolith_diag::{codes, Diagnostic};
use regolith_util::IndexSet;

use crate::nodes::{BoundaryEntry, SystemNode};

/// INV-7 boundary subsumption: an imported/child artifact arrives proven
/// under its OWN `boundary:`; for every boundary quantity both the child
/// and this enclosing node declare, the enclosing node's envelope must be
/// CONTAINED in the child's proven envelope (regolith/04 sec. 6 --
/// containment is uniformly the safe direction because boundary entries
/// are tolerated envelopes). A wider enclosing envelope means the child
/// would be used outside what it was proven under: `E0407`.
#[must_use]
// frob:doc docs/modules/regolith-ir.md#system
// frob:invariant INV-007
// frob:waive TEST002 reason="rust collector fails fast on lib-less fuzz/ crate, killing test-evidence collection repo-wide; binding+tests are real, see FROBLEMS 2026-07-18"
pub fn check_boundary_subsumption(node: &SystemNode) -> Vec<Diagnostic> {
    let mut diags = Vec::new();
    for (child_name, child_entries) in &node.child_boundaries {
        for parent in &node.boundary {
            let Some(child) = child_entries.iter().find(|c| c.name == parent.name) else {
                continue;
            };
            if let Some(reason) = envelope_escapes(parent, child) {
                tracing::info!(
                    system = %node.name,
                    child = %child_name,
                    quantity = %parent.name,
                    reason,
                    "enclosing boundary is not contained in the child's proven envelope (INV-7)"
                );
                diags.push(Diagnostic::error(
                    codes::BOUNDARY_NOT_SUBSUMED,
                    format!(
                        "system `{}`: its `{}` boundary ({}) is not contained in the proven \
                         boundary of `{}` ({}); evidence cannot transfer outside the envelope it \
                         was proven in",
                        node.name, parent.name, parent.raw, child_name, child.raw
                    ),
                ));
            }
        }
    }
    diags
}

/// Whether the enclosing `parent` envelope escapes the child's proven
/// envelope for the same quantity. Only comparable when both carry
/// numeric bounds in the SAME unit; an incomparable pair is `None` (left
/// indeterminate -- INV-7 never assumes containment it cannot prove).
/// Returns a short reason string when the parent is wider on either end.
fn envelope_escapes(parent: &BoundaryEntry, child: &BoundaryEntry) -> Option<&'static str> {
    if parent.unit != child.unit {
        return None;
    }
    let (plo, phi, clo, chi) = (parent.lo?, parent.hi?, child.lo?, child.hi?);
    if plo < clo {
        Some("its lower bound is below the child's")
    } else if phi > chi {
        Some("its upper bound is above the child's")
    } else {
        None
    }
}

/// INV-8 reserve accounting: build targets are additive overlays that
/// consume only declared reserves; exceeding a reserve is `E0432`-family,
/// naming the target (regolith/04 sec. 6). For each reserve with a
/// quantified magnitude, the numeric draws every target declares against
/// it are summed; a sum over the reserve is over-allocation. Nominal
/// draws (`draws: reserves`) carry no magnitude and are not summed -- the
/// check bites only on quantified over-allocation it can prove.
#[must_use]
// frob:doc docs/modules/regolith-ir.md#system
// frob:invariant INV-008
// frob:waive TEST002 reason="rust collector fails fast on lib-less fuzz/ crate, killing test-evidence collection repo-wide; binding+tests are real, see FROBLEMS 2026-07-18"
pub fn check_target_reserves(node: &SystemNode) -> Vec<Diagnostic> {
    let mut diags = Vec::new();
    for reserve in &node.reserves {
        let Some(available) = reserve.amount else {
            continue;
        };
        let mut total = 0.0;
        let mut drawers: Vec<String> = Vec::new();
        for target in &node.target_nodes {
            for draw in &target.draws {
                if draw.name == reserve.name {
                    if let Some(amount) = draw.amount {
                        total += amount;
                        drawers.push(format!("{} ({amount})", target.name));
                    }
                }
            }
        }
        if !drawers.is_empty() && total > available {
            tracing::info!(
                system = %node.name,
                reserve = %reserve.name,
                total,
                available,
                "target draws exceed a declared reserve (INV-8 over-allocation)"
            );
            diags.push(Diagnostic::error(
                codes::BUDGET_CANNOT_CLOSE,
                format!(
                    "reserve `{}` of system `{}` is over-allocated: targets draw {total} against \
                     a reserve of {available} (drawers: {})",
                    reserve.name,
                    node.name,
                    drawers.join(", ")
                ),
            ));
        }
    }
    diags
}
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

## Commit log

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2026-07-04 feat(orchestrator,quarry): build tiers, release gate, registry client
    Orchestrator: build-tier progression, evidence cache keyed with the
    registry version (INV-1/BE-1), eager DFM resolution of free values, the
    lazy loop with sensitivity hooks, and obligation discharge routed to the
    harness model registry. A no-model or indeterminate obligation is an
    explicit deferral that fails --release (INV-24 release-gate totality),
    never a silent pass. Quarry/lodestone: httpx registry client (injectable
    transport) over a sparse index + content-addressed archives, trust by
    signing not hosting (INV-14), content-hash pinning of foreign content
    (INV-22), and vendoring. Flips INV-14/22/24 to real green fixtur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
    [errors.py]
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2026-07-04 feat(ir,lower): real SystemNodes; activate INV-07/08/15
    Build real SystemNodes from the typed CST instead of empty ones: new IR
    types BoundaryEntry/Reserve/FlowEdge/Target and a SystemNode carrying
    boundary, child_boundaries, reserves, flows, and target_nodes, populated
    per system/assembly decl in contracts.rs (target draws bound to
    reserves, child boundaries linked by parts: type reference). Three sound
    conservative checks in regolith-ir/system.rs: INV-07 boundary subsumption
    (E0407, shared-unit interval compare, incomparable left indeterminate),
    INV-08 target additivity (E0432, summed draws over a reserve), INV-15
    ledger conservation (E0420, an undeclared flow endpoint is a leak; broad
    nam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
    [system.rs]
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2026-07-04 feat(sem,lower): sound converter graph + acyclicity check (INV-16 mechanism)
    Add regolith-sem converter.rs: Domain (Continuous|Clock), EdgeKind
    (Combinational|Converter|Register), the ZOH delta-by-type rule
    (a converter/register edge or any domain-crossing edge breaks a
    combinational cycle), and a DFS within-domain acyclicity check emitting
    E0105 COMBINATIONAL_CYCLE. Wired as a real pass in regolith-lower checks.
    Unit-tested (cycle caught, comparator-feeds-own-threshold legal,
    cross-domain always breaks, register-broken legal).
    INV-16 stays an HONEST xfail: the elec behavioral layer (ports:/spec:/
    converter-assignment/on-event bodies) still parses to OpaqueIsland, so
    the graph is empty end-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
    [converter.rs]
2026-07-05 feat(syntax,lower): type elec behavioral bodies; flip INV-16
    Promote the cuprite behavioral-layer bodies (ports:/spec: with signal
    domains, converter assignments x = adc(...)/dac(...) crossing domains,
    clocked on-event registers, same-domain combinational relations) from
    OpaqueIsland to typed CST, following the OwnershipStmt/QueryStmt
    statement-node precedent. New regolith-lower converter.rs builds the
    ConverterGraph (nodes with Continuous|Clock domains, edges with
    Combinational|Converter|Register kinds) from the typed CST and runs the
    existing sound acyclicity check: a comparator-feeds-own-threshold design
    (loop broken by a converter) discharges, a same-domain combinational
    cycle fails with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
    [converter.rs]
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2026-07-06 feat(harness): solver plugin layer -- packs, subprocess adapter (WO-20)
    External model packs now load by entry point (regolith.model_packs;
    built-ins first, packs sorted by name; a bad pack is skipped LOUDLY
    via BuildReport.pack_errors, duplicate model ids rejected). One
    subprocess solver adapter speaks the serialized schemas over stdio
    (SolverResponse in regolith-oblig, SCHEMA_VERSION 4); every failure
    arm -- spawn, timeout, garbage, schema skew, nonzero exit -- maps to
    harness.adapter_error INDETERMINATE, never a pass, never an
    exception. Evidence keys fold the discharging model's (pack_name,
    pack_version) on both sides of the FFI (AD-19/BE-1 extension): a
    pack upgrade re-keys exactly its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
    [errors.py]
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2026-07-06 feat(realizer): elec structural realizer -- bind, netlist, KiCad seam (WO-24 partial)
    Adds regolith.realizer.elec: allocation-search component binding
    against registry records with backjump-on-nogood, neutral netlist
    emission, and a KiCad layout adapter built to the WO-20 subprocess
    wire protocol. Real KiCad tooling is unavailable in this environment
    (kicad-cli/pcbnew not on PATH) so the layout/DRC/extraction paths are
    proven against fake subprocess responses through the real adapter
    code, not a live KiCad session -- recorded as a cut in the WO file.
    Also flags that no lowering-output-to-binding-requirement bridge
    exists yet (WO-19/WO-26 territory); the engine is proven against a
    hand-built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
    [errors.py]
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2026-07-08 feat(lower): project architecture resource demands to payload (D4 Rust)
    WO-29 deliverable 4, Rust half of the D90 binding-requirement bridge.
    A new lower pass (block_requirement) walks each `architecture for X:`
    declaration's resources:/memories:/peripherals: entries and projects
    every block that carries a `promises:` argument into a schema-versioned
    regolith_ir::BlockRequirement { owner, block, contract, demands }
    BuildPayload field. The demand vocabulary is the promises: keyword arg
    (cuprite/05 sec 2 -- resources are abstract blocks with promises;
    regolith/10 sec 1 interface-promises row), NOT budget: ceilings.
    Raw-text discipline mirrors feature_program (deliverable 3): the pass
    emits th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
    [espresso_machine.json]
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2026-07-08 feat(ls): scaffold regolith-ls crate with LSP lifecycle + F111 mapping
    New crate crates/regolith-ls (bin, lsp-server/lsp-types over stdio)
    per AD-24: embeds regolith-api and below in-process, never regolith-py.
    Adds workspace root discovery (nearest quarry.toml), full-text document
    sync, and the F111 byte-offset <-> UTF-16 line/character converter with
    non-ASCII fixtures (surrogate pairs, boundary edits).
    [main.rs]
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2026-07-08 fix(realizer): pass mm bbox/COM triples as lists, not tuples
    The regenerated RealizedGeometry schema types fixed-length f64
    triples as list[float] (datamodel-code-generator's rendering of a
    schemars fixed-size array), not tuple[float, float, float] --
    ty flags the tuple literals as a type mismatch against the
    promoted schema.
    [espresso_machine.json]
2026-07-08 feat(lower): emit BuildPayload.flownets (WO-32 D4b, Rust half)
    The orchestrator needs a name -> FlownetPayload map to put into the
    WO-30 store so obligations' `kind: flownet` PayloadRef digests
    (D129) resolve at discharge time. LowerOutput/BuildPayload gain
    `flownets: IndexMap<String, FlownetPayload>`, sourced from the
    elaboration `push_fluid_obligations` already performs (no second
    `elaborate_flownets` call, AD-22). SCHEMA_VERSION 11 -> 12 (a
    BuildPayload shape change, matching the WO-29 d3/d4 precedent); the
    golden corpus is re-keyed (hash values only, no count/diagnostic
    changes, since the version folds into every content address).
    [espresso_machine.json]
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2026-07-08 chore(schema): regenerate _schema/ and goldens for SCHEMA_VERSION 15
    Mechanical fallout of rebasing WO-33's FieldDatum/ClaimForm::Compute
    schema addition past master's WO-32 D4a-D6/WO-42 D130/D131 SCHEMA_VERSION
    bumps (9 -> 14): make schema regenerates the pydantic facade
    (ClaimForm7, Form6, FieldDatum, CoverageMethod6) against the current
    core, and every obligation/snapshot content hash in the corpus goldens
    shifts with the 14 -> 15 bump (counts and diagnostics unchanged --
    pure hash drift, reviewed via REGOLITH_UPDATE_GOLDEN=1).
    [espresso_machine.json]
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2026-07-08 feat(realizer): validate-and-emit declared flow_paths (D130 remainder)
    The mech realizer's remaining v1 duty (design-log 2026-07-08-cycle-25
    D130): cross-check every declared FlowPath segment against the
    FeatureProgram's feature ops (bore existence, declared flow_area vs.
    the bore's resolved circular area) and emit agreeing measures verbatim
    as degenerate-interval PathSegments, replacing the paths={} stub. A
    disagreement is a named RealizeError value, never a silent preference.
    [errors.py]
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2026-07-08 feat(elec): add pin-mux matcher (WO-35 deliverables 1-3)
    Pin assignment was the last spec-promised derived output with no
    producer (F101). realizer/elec/pinmux.py assigns flow demands to
    package pins via a deterministic constraint search over the typed
    AlternateFunctionTable/FlowDemand shape (record-declared kinds and
    capability flags, no vendor shape hardcoded), reusing the WO-24
    allocation-search backjump skeleton. Every assignment carries the
    INV-21 planner(pinmux <instance>) cause; a locked: pinmux(...) pin
    that cannot carry the demanded function is named as the constructive
    cause distinctly from a generic contention failure.
    [errors.py]
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2026-07-08 feat(firmware): add firmware realizer -- contract header + BSP codegen (WO-37)
    Application firmware currently re-derives pin/clock/event facts by
    hand from the design (#define LED_PIN 13), the exact staleness
    failure the toolchain already fixed for wire lengths (G42): nothing
    invalidates the hand copy when the design moves.
    Adds regolith.realizer.firmware: a hardware contract header with one
    symbolic constant per pin-mux/clock/event/partition assignment (each
    carrying its lockfile cause), BSP pin/clock init + ISR stubs
    translated through a signed MCU-family pack seam (stm32g0 reference
    pack), a linker memory map + build fragment, and opt-in generated
    Rust -sys bindings -- all content-addres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
    [bindings.py, bsp.py, contract.py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]
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2026-07-09 test(wo-34): routed-runs negative + demand fixtures, golden refresh (D4/D5)
    Add three negative fixtures (51/52/53): dangling endpoint (E0307) and
    unknown bundle (E0308) self-calibrate against real compiler output;
    cross-net (E0306) is EXPECT-TODO, honestly deferred since no seam
    exposes cuprite net membership to regolith-lower for this pass today.
    Add wiring_harness.cupr: a two-run harness (declared-waypoint +
    route:free) plus one E06xx ampacity rule-pack demand fixture
    (deliverable 4, grammar+lowering golden only -- the WO-28 engine
    remainder is not landed). Regenerate every golden_corpus fixture
    (the new BuildPayload.harnesses field changes every payload's stable
    snapshot shape).
    [espresso_machine.json]
2026-07-09 feat(lower): construct typed temporal claim forms (WO-26 D102)
    peak/rms/overshoot/settles/stays_within call syntax now lowers to its
    typed ClaimForm variant (Peak/Rms/Overshoot/Settles/StaysWithin)
    instead of the opaque Comparison blob, with two new compile
    diagnostics (E0435/E0436) for a REDUCTION missing its comparator or a
    CONTAINMENT carrying an unexpected one. A peak(x, at=<location>)
    spatial tag and a windowed stays_within (no window field on the
    landed schema yet) are recorded, narrow non-conversions rather than
    invented shapes.
    [espresso_machine.json]
2026-07-09 fix(orchestrator): name the D102 temporal-form deferral honestly
    translate() now recognizes the five typed temporal ClaimForm classes
    and defers them under temporal_reduction_unmodeled /
    temporal_containment_unmodeled instead of the old generic
    unsupported_op, since no harness model pack yet consumes a temporal
    claim kind. Regenerates the deferral-corpus golden and records the
    D102 completion plus remaining WO-26 cuts (D103, D105a-d, the
    StaysWithin window-field gap) in the WO ledger.
    [deferral_espresso_machine.json]
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2026-07-09 docs(rules): guide flipped to WORKING; INV-29 ledger + invariant suite
    WO-28 deliverables 7+8: the authoring guide documents the shipped
    engine truthfully (binding order in sec. 2a, static-vs-deferred
    markers, the PCB example matched to the shipped jlc_2l spelling with
    the aggregate form kept as the target vocabulary); INV-29 (rule
    totality) enters regolith/13 with its proof argument and a five-prong
    executable fixture suite; dogfood rules added to both reference packs
    per the expert-read acceptance test; positional_value truncates
    nested-punctuation value tokens; grammar.ebnf records the dotted
    process name.
    [deferral_espresso_machine.json, espresso_machine.json]
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2026-07-09 feat(lower): sweep-domain claim lines + general comparison claims (WO-26 D105a/D103)
    A forall <var> in [lo,hi]: (or {a,b}) claim-line prefix now lowers
    into the obligation's existing sweep slot (SweepDomain), exposing at
    the grammar surface what the schema already carried. A claim whose
    one top-level comparator sits mid-expression (the Kestrel link
    budget) splits into a real Comparison{lhs, op, rhs}, and each side's
    two-segment entity-field reference terms resolve through the parsed
    declarations into given.refs (promise bounds and plain values;
    unresolvable refs are skipped and named in the log, never invented).
    More than one top-level comparator is a new compile diagnostic
    (E0437). Containm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
    [espresso_machine.json]
2026-07-09 feat(regolith-ls): navigation, full completion, tiered diagnostics, release matrix
    Closes most of WO-38's remaining ledger: go-to-definition/references/
    resolution-checked rename over import-reachable files (refusing
    ambiguous renames), position-aware completion (block-kind keywords +
    in-scope decl names), a two-tier debounced diagnostic pipeline
    (immediate syntax-tier reparse plus a ~300ms-debounced semantic-tier
    workspace check with a passing SLO benchmark), and the regolith-ls
    per-platform release CI binary matrix. Artifact-fed hover and registry
    component-id completion are escalated in the WO-38 ledger (both need
    architecture decisions outside this WO's scope).
    Also fixes an unrelated p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
    [main.rs]
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2026-07-09 feat(orchestrator): lower general comparisons + the link budget (WO-26 D103)
    translate() now lowers the D102 temporal reductions and settles
    containments to real requests (claim kind = the claim name; a name no
    pack registers is a model-absent indeterminate at discharge, per the
    acceptance wording), and recognizes the link-budget shape -- a >=
    general comparison whose terms map onto the elec.link.margin pack's
    public port names -- building its request from the core-resolved
    given.refs. A link-shaped claim with an unresolved reference defers
    as given_unresolved NAMING it (the real Kestrel posture: the pack is
    reachable, antenna.gain/path_loss are not declared). New end-to-end
    tests drive a fu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
    [deferral_espresso_machine.json]
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2026-07-09 feat(orchestrator): pipeline-produced realizer programs; close WO-51
    Deliverable 4 (WO-51/D152): staged_build promotes the emitted
    feature_programs payload into the realizer contract
    (orchestrator/programs.py) keyed by the D130 <stage>.wetted selector
    subjects -- outline from the fully pinned promoted sketch (cumulative
    cardinal walk over declared lengths), blank thickness from the
    declared depth, flow segments from declared facts only (area from
    the declared diameter, the op's circular section); anything
    indeterminate is a NAMED skip and stays pending (AD-25). The caller
    channel stays as the override. The acceptance chain -- declarative
    .hema cavity query -> emitted program -> realized STEP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
    [espresso_machine.json]
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2026-07-09 test(golden): fold the Lint family into the negative/golden drivers
    Both corpus drivers' code-decoder family-base tables gain "lint":
    800 (else a fixture that also lints KeyErrors); golden snapshots
    regenerated to include the new lint diagnostics now flowing through
    check/compile (WO-40, no behavior asserted beyond determinism).
    [espresso_machine.json]
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2026-07-09 chore(corpus): regenerate goldens + drop unused stdlib import after cleanup
    Golden data and one stdlib pattern's import list follow from the
    corpus warning sweep in f1f219e (fewer unused imports and resolved
    deferrals); staged separately as they were missed in that commit.
    [deferral_espresso_machine.json, espresso_machine.json]
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2026-07-09 test(drawings,golden): cover the two new producers; regen goldens
    Deterministic-across-two-runs, drafting-audit-clean, and structural
    (one symbol per node / one candidate row per table row) tests for
    diagram.contract_graph and diagram.opt_trace, plus backend wiring
    tests for the missing-payload error paths. Regenerate the corpus
    goldens: SCHEMA_VERSION folds into every content-address digest
    (AD-18), so the 21->22 bump changes every obligation/snapshot hash
    even though no lowering behavior changed.
    [espresso_machine.json]
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2026-07-10 feat(oblig): add RealizedAssembly schema + FramePayload.transfers (23->24)
    WO-62 slice B deliverable 4 + the D176 addendum ride the ONE
    SCHEMA_VERSION bump: RealizedAssembly (kind assembly.realized) is the
    next AD-25 realized-domain IR (parts/placements, dof_states, mass/COM,
    interferences); FramePayload gains a transfers field lowering the
    calcite `structure ... transfers:` block (id/kind/from/to/tributary)
    so feldspar WO-23's tributary resolution can be assembled from the
    payload without re-parsing source (AD-22). Golden corpus regenerated
    (digest-only churn, D168 train rule).
    [espresso_machine.json]
2026-07-10 feat(realizer): mate-graph solve + STEP assembly export + extraction
    WO-62 slice B deliverable 5: regolith.realizer.mech.assembly solves a
    declared mate graph to a placed RealizedAssembly (deterministic
    sequential placement, root at identity, mate-loop residual diagnostics
    naming every mate on the loop), exports the placed STEP assembly
    through the existing exporter seam (with the compound-export usage-id
    counter normalized for byte-determinism), extracts mass/COM, and finds
    pairwise interferences via the v1 AABB overlap test. put_realized_assembly
    mirrors put_realized_geometry's WO-30 store seam.
    Integration seam recorded honestly (mirrors WO-42's own
    geometry_realizable precedent): no reg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
    [errors.py]
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2026-07-10 feat(corpus): declare section families; regenerate goldens (WO-68)
    WO-68 deliverable 5. The five ratified calcite designs' searchable
    members now declare a candidate family instead of bare `free`, matched
    to each design's FIXED siblings' material class: footbridge G1/G2,
    bus_shelter G1, small_office G2_AB/GR_AB (steel, astm_a992) get
    `section: in registry(std.civil.w_shape)`; pole_barn T1 (timber,
    spf_no1 -- std.civil has no dedicated truss family) gets
    `section: in registry(std.civil.timber_sawn)`. retaining_wall is
    untouched (no forall combo in its require group).
    Regenerate every golden via the repo's REGOLITH_UPDATE_GOLDEN=1
    machinery (never hand-edited). Obligation-count deltas (every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
    [espresso_machine.json]
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2026-07-10 fix(lower): recover fluid comparator-after-call structurally (WO-92)
    A fluorite claim whose comparator sits after the `fluids.*(...)` call
    (`fluids.mdot(duct) >= 0.0003`) lowered through push_fluid_obligation
    as an opaque `op="require"` blob, which the translate-side head-only
    `_split_comparator` cannot parse -- so it deferred `unsupported_op`
    instead of reaching a model. Route the fluorite claim predicate through
    `split_general_comparison` (its depth-0 one-comparator scan) so the
    obligation carries a real comparator op with the call as LHS, keying the
    scalar request on the claim's own field name and preserving the flownet
    payload. A head comparator or multi-comparator predicate stays the
    op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
    [deferral_espresso_machine.json, espresso_machine.json]
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2026-07-10 test(corpus): flagship load exercises, E0211 fixtures, regenerated goldens
    hydro_press gains the direct kN/m line load on Base (the WO-73 W4
    wall's own exercise; Base now searches and pins its own winner);
    timber_pavilion gains the stationed point load on G1@0.5, rejoins
    P_A/P_B to the structure (axial demand resolves, wall note 4 dead),
    and swaps its per-member narrowing for the .members.all aggregate the
    D194 expansion partitions (Purlin defers alone; girders and posts
    carry real verdicts). Two negative fixtures pin E0211's bare-member
    and out-of-range-station conditions against live output.
    Goldens regenerated (REGOLITH_UPDATE_GOLDEN=1, never hand-edited):
    every obligation key re-keys un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
    [espresso_machine.json]
2026-07-10 feat(lower,orchestrator): spec-side conformance windows + teaching deferral (D195)
    D195 (answering F116): generic-parameter instantiation
    (impl HeaterDrive<watts=50W> against power: <= watts) resolves the
    SPEC side of a conformance window only -- never the impl side, where a
    fabricated bound would discharge 50 <= 50 vacuously and mask real
    indeterminacy (INV-13/26). conformance_windows now returns
    Both | SpecOnly: the spec side resolves as a literal or a parametric
    promise closed by the impl header's generic pin, and a SpecOnly window
    threads conformance_sense/spec_bound/conformance_field into given.loads
    without an impl_bound. _translate_conformance defers that one-sided
    shape with the NEW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
    [deferral_espresso_machine.json, espresso_machine.json]
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2026-07-10 test(wo90): E0450 negative fixture; regen goldens; docs + WO close
    Multi-line bracketed predicates now capture whole across the corpus
    (deferred unsupported_op -> lowered/more-specific deferral; no
    lowered->deferred regressions). Adds fixture 69 for E0450, makes the
    bracket line-join + forall-domain rules explicit in grammar.ebnf and
    regolith/07, and flips WO-90 to done.
    [deferral_espresso_machine.json, espresso_machine.json]
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2026-07-10 fix(lower): thread fluid claim-suffix givens into given.loads (WO-94 esc 1)
    push_fluid_obligation hardcoded an empty given, silently dropping every
    fluid claim's `given <ident> = <expr>` suffix. Split the suffix off the
    predicate before the comparison scan (so it never pollutes the comparator
    RHS) and thread each quantity-valued binding into given.loads -- the
    _translate_call_kwargs_claim fallback channel (inline call kwargs still
    win). Regime-selector givens (v3 = brew) stay dropped so the generic
    scalar translate path never hard-defers a claim that used to lower.
    Net corpus churn: espresso `vented` deferred(unsupported_op) -> lowered.
    [deferral_espresso_machine.json]
2026-07-10 fix(lower): carry the call form through within-window claim splits
    A `within [lo, hi]` window split into two scalar comparisons whose lhs
    was the bare claim LABEL (batt_window), so translate's call-form
    recognition could never fire on a windowed claim -- it false-lowered to
    a label-named claim_kind that hit no_model at discharge.
    within_window_bounds now returns the leading quantity expression too, and
    the split halves carry it as their Comparison lhs. A call-form window
    (thermo.temperature(...)) now routes to its model via _match_call_lhs.
    Corpus: batt_window/temp_window (cubesat) + brew_hold (espresso) move to
    the honest thermo.junction_temperature_inputs_missing deferral with named
    inputs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
    [deferral_espresso_machine.json, espresso_machine.json]
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
